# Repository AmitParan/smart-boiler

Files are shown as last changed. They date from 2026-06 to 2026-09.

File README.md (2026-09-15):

# Smart Electric Boiler — דוד חשמלי חכם

**An autonomous retrofit energy-management system for domestic electric water heaters.**

Final engineering project · Afeka College of Engineering, Tel Aviv
Students: **Elad Moalem** (אלעד מועלם) · **Amit Paran** (עמית פארן)
Supervisor: **Dmitry Teif** (דמיטרי טייף)

**Communication:** Master ↔ slave over **Power Line Communication** (KQ-330
modems on the 220 VAC wiring) — the default build. A WiFi (UDP) transport is
available as an option.

> ### 👨‍🏫 Reviewing this project? Start with the **[Guided Code Tour →](CODE_TOUR.md)**
> A short walkthrough of the safety architecture, the FreeRTOS mutex design, the
> wire protocol and the transport abstraction — each claim shown alongside the
> few lines of code that prove it, plus **four checks you can reproduce yourself**
> on the hardware in under ten minutes.

---

## Table of contents

1. [The problem](#1-the-problem)
2. [The solution — two-tier hybrid heating](#2-the-solution--two-tier-hybrid-heating)
3. [System architecture](#3-system-architecture)
4. [Hardware](#4-hardware)
5. [Safety architecture](#5-safety-architecture)
6. [Communication](#6-communication)
7. [Firmware architecture (FreeRTOS)](#7-firmware-architecture-freertos)
8. [The control brain](#8-the-control-brain)
9. [Repository layout](#9-repository-layout)
10. [Build and flash](#10-build-and-flash)
11. [Demo mode — 8 automated scenarios](#11-demo-mode--8-automated-scenarios)
12. [Results](#12-results)
13. [Documentation index](#13-documentation-index)

---

## 1. The problem

A conventional Israeli electric boiler ("דוד חשמלי") is a **blind, open-loop
machine**. The user flips a switch, waits, and gets no feedback about water
temperature or how much hot water is actually available. Three physical
inefficiencies follow from that:

| Problem | Consequence |
|---|---|
| **Open-loop operation** | The user over-heats "just in case", or under-heats and gets a cold shower |
| **Standing thermal losses** | A 80–150 L tank held at high temperature bleeds heat to the room continuously, 24 h a day |
| **Whole-tank heating** | Washing your hands heats 150 L of water to serve 2 L of demand |

The obvious fix — a **tankless instant heater** — is not available to most Israeli
homes. Those units demand **14 kW–24 kW** and three-phase service. A standard
apartment is limited to **single-phase, 16 A ≈ 3 kW**.

## 2. The solution — two-tier hybrid heating

This project fits **within the 3 kW household ceiling** by splitting the job
across two coordinated heating tiers instead of one big element.

```
   ┌──────────────────────────────────────────────────────────────┐
   │  TIER 1 — Moderate Storage                                   │
   │  Hold the main tank at only 35–40 °C, not 60–70 °C.          │
   │  A cooler tank loses far less heat to the room, so standing   │
   │  losses collapse. The tank is a warm buffer, not a kettle.    │
   └──────────────────────────────────────────────────────────────┘
                                │  water leaves the tank at ~35-40 °C
                                ▼
   ┌──────────────────────────────────────────────────────────────┐
   │  TIER 2 — Flow-Triggered Top-Up                              │
   │  A 3000 W inline heater in series with the outlet pipe adds   │
   │  a focused +3-7 °C ONLY while water is actually flowing,      │
   │  and only under hardware interlock. Energy is spent on the    │
   │  water you are using, at the moment you use it.               │
   └──────────────────────────────────────────────────────────────┘
```

The tank never has to be hot — it only has to be *warm enough* that a 3 kW
inline booster can close the remaining gap in real time. That is what keeps the
system inside a single-phase 16 A supply while still delivering a hot shower.

On top of the thermodynamics sits an **adaptive learning layer** that records
when the household actually showers and pre-heats ahead of predicted demand,
so the tank is ready without being held hot all day.

## 3. System architecture

Two microcontrollers, deliberately separated by role:

```
┌───────────────────────────────┐              ┌───────────────────────────────┐
│  MASTER — indoor command unit │              │  SLAVE — boiler-side unit     │
│  ESP32-S3                     │              │  ESP32-C6                     │
│  Viewe UEDX80480050E-WB-A     │◄────────────►│  custom PCB                   │
│  800x480 capacitive touch     │   1 packet   │                               │
│                               │   per second │                               │
│  · LVGL v8 touchscreen HMI    │              │  · 3x DS18B20 temperature     │
│  · SystemManager state machine│              │  · YF-B6 flow sensor          │
│  · Smart preheat learning     │              │  · ACS758 current sensing     │
│  · WiFi / NTP / weather       │              │  · 2x SSR drive (burst PWM)   │
│  · 8-scenario demo bench      │              │  · analog hardware interlock  │
└───────────────────────────────┘              └───────────────────────────────┘
        the user's world                              the plumbing's world
```

**Why two units?** The boiler is usually in a service balcony or on the roof —
behind reinforced concrete, often inside or near a MAMAD (safe room). Putting
the touchscreen there would be useless, and relying on WiFi reaching there was
judged unsafe for a control link. The control link therefore runs over **the
building's own 220 VAC wiring** using **Power Line Communication (PLC)**, which
passes through concrete that WiFi cannot.

> **Transport options.** PLC over KQ-330 modems is the default link. The
> communication layer is abstracted, so the same firmware can alternatively run
> the link over **WiFi (UDP)** with a single build flag, carrying byte-identical
> packets. Everything above the transport is shared by both options
> (see [section 6](#6-communication)).

## 4. Hardware

### 4.1 Slave GPIO map — ESP32-C6 *(book Table 7)*

| GPIO | Function | Direction | Component |
|:---:|---|---|---|
| **4** | `SSR_Internal` | Output (PWM) | Tank heater SSR |
| **5** | `SSR_Boost` | Output (PWM) | Inline booster SSR |
| **7** | `One_Wire_Bus` | In/Out | 3 × DS18B20 on one bus |
| **6** | `Flow_Sensor` | Input (interrupt) | YF-B6 Hall-effect flow meter |
| **10** | `PLC_RX` | Input (UART) | KQ-330 DOUT, via level shifter U3 |
| **11** | `PLC_TX` | Output (UART) | KQ-330 DIN |
| **3** | `Current_ADC` | Input (analog) | ACS758LCB-050B |

Defined in [`slave/src/config/config.h`](slave/src/config/config.h).

### 4.2 Master GPIO map — ESP32-S3 *(book Table 9)*

| GPIO | Function | Direction | Component |
|:---:|---|---|---|
| **17** | `MASTER_TX_PIN` | Output | KQ-330 DIN |
| **13** | `MASTER_RX_PIN` | Input | KQ-330 DOUT |
| **43 / 44** | `UART0_TX/RX` | — | USB CDC debug console |
| — | Touch + RGB | — | Managed by the board package (800×480) |

Defined in [`master/src/config/config.h`](master/src/config/config.h).

### 4.3 Key components

| Component | Part | Role |
|---|---|---|
| Master MCU | ESP32-S3 (Viewe UEDX80480050E-WB-A) | HMI, decisions, connectivity |
| Slave MCU | ESP32-C6-DevKitC-1 | Sensing, switching, safety |
| Power-line modem | KQ-330 | 9600 bps UART over 220 VAC |
| Solid-state relays | SSR-40DA (zero-crossing) | Switch both heating elements |
| Temperature | 3 × DS18B20 (1-Wire) | Tank, boiler outlet, boost outlet |
| Flow | YF-B6 Hall-effect | `F = 6.6 × Q` (Hz per L/min) |
| Current | ACS758LCB-050B | 40 mV/A, power calculation + fault detection |
| Comparator | LM393N + NTC | Autonomous 85 °C thermal cutoff |
| Interlock switching | 2N2222A BJT, BS170 MOSFET | Watchdog and flow gates |
| Level shifter | SN74LV1T34 | 5 V ↔ 3.3 V on the modem link |
| PSU | HLK-10M05 | 220 VAC → 5 V, isolated |

Full schematic, Gerbers, drill files and BOM live in [`pcb/`](pcb/).
Datasheets for every part are in [`datasheets/`](datasheets/).

## 5. Safety architecture

Safety is **dual-layer**: fast software checks, plus an **analog hardware
envelope that works even if the microcontroller is dead**. This is the heart of
the project and the reason the design is defensible.

### 5.1 The four hardware gates *(book §9.1.4)*

| Gate | Built from | What it physically prevents |
|---|---|---|
| **a. Internal Watchdog Gate** | 2N2222A BJT + DC-blocking capacitor | Controller freeze. The SSR latches **only** while it receives a continuous 1 kHz pulse train. A frozen MCU leaves a constant DC level, the capacitor blocks it, the base charge bleeds away and the heater is cut within ≈1 s. |
| **b. External Boost Gate** | Watchdog + flow interlock + PWM | Triple-gated. The booster cannot energise unless the controller is alive **and** water is genuinely flowing. |
| **c. Flow Interface** | BS170 MOSFET, 15–60 Hz | Dry-fire protection. When flow pulses stop, the RC network discharges and cuts the booster within 1.0 s. |
| **d. Analog Comparator + Thermal Cutoff** | LM393N + NTC, V<sub>ref</sub> ≈ 0.63 V | Boiling. At ≈85 °C the comparator output flips and disconnects SSR power directly — **no firmware involved at all**. |

> **This is why `ledcWrite(pin, 127)` at 1 kHz is not optional.**
> It looks like a PWM power setting; it is actually the **carrier that proves the
> controller is alive** to gate (a). Replacing it with `digitalWrite(HIGH)` would
> be read by the hardware as a controller-freeze fault and the heater could never
> stay on. See [`slave/src/tasks/pwm_task_internal.cpp`](slave/src/tasks/pwm_task_internal.cpp).

### 5.2 Hardware truth table *(book Table 11)*

`1` = live PWM pulse train · `DC/0` = logic low / fault / blocked · `X` = don't care

| NTC safety | CMD internal | CMD boost | Flow | SSR internal | SSR boost | Meaning |
|:---:|:---:|:---:|:---:|:---:|:---:|---|
| 0 (overheat) | X | X | X | **0** | **0** | NTC disconnects everything — system-wide safe state |
| 1 (OK) | DC / 0 | DC / 0 | X | 0 | 0 | Idle — no commands from the controller |
| 1 (OK) | 1 | DC / 0 | X | **1** | 0 | Base tank heating, independent of flow |
| 1 (OK) | DC / 0 | 1 | 1 | 0 | **1** | Booster only — requires flow |
| 1 (OK) | X | X | **0** | X | **0** | Flow interlock forces the booster off |
| 1 (OK) | 1 | 1 | 1 | **1** | **1** | Both tiers active under hardware supervision |

### 5.3 Software safety — `TaskSafety`, every 50 ms

[`slave/src/tasks/safety_task.cpp`](slave/src/tasks/safety_task.cpp) runs at the
**highest FreeRTOS priority (4)** and independently verifies:

1. Every temperature sensor is below **80 °C** (software cutoff, below the 85 °C hardware trip)
2. The booster is never commanded while flow **< 1.0 L/min** (dry-fire)
3. No **uncommanded current** is flowing — catches a welded/shorted SSR
4. A **CMD packet arrived within the last 5 s** — otherwise the link is presumed lost
5. Every temperature reading is **physically plausible** (−55…+125 °C) — a
   disconnected DS18B20 reports −127 °C, which would otherwise convince the
   controller the water is freezing and make it heat indefinitely while check 1
   stays silent. A failed sensor must stop the heater, not command full power.

Any failure latches `system_fault`, and both SSRs are cut immediately.

## 6. Communication

### 6.1 Binary packet protocol

Frame layout, identical on both sides
([`*/src/config/boiler_protocol.h`](slave/src/config/boiler_protocol.h)):

```
[ 0xAA | LEN | TYPE | SEQ | ...payload... | CRC8 | 0x55 ]
  start                                            end
         └────── CRC-8/SMBUS (poly 0x07) ──────┘
```

| Packet | Direction | Size | Contents |
|---|---|:---:|---|
| **CMD** | Master → Slave | 9 B | PWM internal %, PWM boost %, flag bits |
| **STATUS** | Slave → Master | 17 B | 3 × temperature, flow, power, status bits |

Temperatures are sent as `int16 × 10` (0.1 °C resolution), flow as `uint16 × 10`.
Cadence is **1 packet per second**, with a rolling sequence number so either side
detects a dropped packet.

### 6.2 The transport layer — PLC, with a WiFi option

The master and slave communicate over **Power Line Communication**: each board
drives a KQ-330 modem over UART (9600 bps), and the modems carry the packets
across the 220 VAC mains wiring. The link medium is abstracted behind
[`link.h`](slave/src/comms/link.h), so the **exact same bytes** can alternatively
travel over WiFi.

The PLC link was verified working on the bench: a CMD every second, a STATUS
reply, CRC-8 validation and sequence numbers, with the KQ-330 timing constants
(2 ms/byte, 200 ms half-duplex guard) locked in firmware.

```
       sendCommand() / PLC_SendStatus()          ← protocol, unchanged
                     │
          link_send() / link_poll()              ← the abstraction
                     │
           ┌─────────┴─────────┐
     link_plc.cpp        link_wifi.cpp
   KQ-330 over UART        UDP over WiFi
```

| | `link_plc.cpp` **(default)** | `link_wifi.cpp` (option) |
|---|---|---|
| Framing | Byte-by-byte receive state machine | A datagram **is** a frame |
| TX timing | 2 ms inter-byte gap (modem requirement) | none |
| Half-duplex guard | 200 ms after RX before TX | none — UDP is full duplex |
| Discovery | n/a | Automatic; no IP is configured anywhere |

Selected by one build flag in `platformio.ini` — **the same on both sides**:

```ini
build_flags =
    ; -DLINK_WIFI    ; flag absent (default) -> KQ-330 power-line modem
                     ; uncomment             -> WiFi (UDP)
```

### 6.3 PLC installation notes

- Both KQ-330 modems must be on the **same electrical phase** of the mains.
- The modem is half-duplex, so the protocol is strictly master-initiated
  request/response, with a 200 ms guard before the slave replies.
- Bytes are paced 2 ms apart, as the modem requires.

A step-by-step procedure for checking the modem link during installation is in
[`TROUBLESHOOTING_PLC.md`](TROUBLESHOOTING_PLC.md).

## 7. Firmware architecture (FreeRTOS)

### 7.1 Slave task hierarchy *(book Table 19)*

| Priority | Task | Period | Responsibility |
|:---:|---|---|---|
| **4** (highest) | `TaskSafety` | 50 ms | Closed-loop safety, hard SSR cutoff |
| **3** | `TaskPWM_Internal`, `TaskPWM_Boost` | 2000 ms window | Burst-mode SSR power control |
| **2** | `TaskTemp`, `TaskFlow`, `TaskCurrent`, `TaskPLC` | 100–500 ms | Sensing and the comms link |
| **1** (lowest) | `TaskSerial` | loop | Debug console, `d`/`r` mode switching |

### 7.2 Memory guards — the four mutexes *(book Table 20)*

The slave is fully concurrent, so every shared variable is protected:

| Mutex | Written by | Read by |
|---|---|---|
| `guard_temps` | `TaskTemp` | `TaskPLC`, `TaskSafety`, `TaskPWM_Boost` |
| `guard_flow` | `TaskFlow` | `TaskPLC`, `TaskSafety`, `TaskPWM_Boost` |
| `guard_current` | `TaskCurrent` | `TaskPLC`, `TaskSafety` |
| `guard_cmd` | `TaskPLC` | `TaskPWM_Internal`, `TaskPWM_Boost`, `TaskSafety` |

Created in [`slave/src/main.cpp`](slave/src/main.cpp) **before any task starts**.

### 7.3 Master — dual-core split *(book Table 17)*

The ESP32-S3's two cores are separated deliberately so that a heavy LVGL redraw
can never delay a control packet:

| Core | Work |
|---|---|
| **Core 0** | `TaskMasterComms` — 1 s CMD cadence, STATUS reception, CRC-8 |
| **Core 1** | LVGL GUI, touch, WiFi/NTP, weather, automated test bench |

### 7.4 Burst-mode power control

The booster must deliver a *specific* power, not simply on/off. Required power
comes from the thermodynamic relation:

```
P = ṁ · Cp · ΔT
```

For 5 L/min (ṁ = 0.0833 kg/s) and ΔT = 6 °C:
`P = 0.0833 × 4184 × 6 ≈ 2090 W` — about **70 %** of the 3000 W element.

The controller therefore runs a **2000 ms time-proportional window**: 1400 ms ON,
600 ms OFF. Because the SSR is zero-crossing, a 2 s window contains 200 mains
half-cycles at 50 Hz, so 70 % resolves to 140 half-cycles — fine-grained control
with no switching noise injected onto the power line.

```
Power envelope   ████████████████████░░░░░░░░    1400 ms ON / 600 ms OFF
1 kHz carrier    ▌▌▌▌▌▌▌▌▌▌▌▌▌▌▌▌▌▌▌▌            watchdog proof-of-life
Mains output     ∿∿∿∿∿∿∿∿∿∿∿∿∿∿∿∿∿∿∿∿            switched at zero crossings
```

## 8. The control brain

### 8.1 SystemManager — finite state machine

[`master/src/control/SystemManager.cpp`](master/src/control/SystemManager.cpp)
evaluates in strict priority order:

| Priority | State | Trigger | Output |
|:---:|---|---|---|
| 1 | `SAFETY_OVERRIDE` | Link lost **or** T ≥ 85 °C | Both PWM = 0 |
| 2 | `STATE_OFF` | User switched off | Both PWM = 0 |
| 3 | `STATE_SHOWER_BOOST` | Flow detected **and** tank < 45 °C | Booster on |
| 4 | `STATE_HEATING_TANK` | No flow **and** tank < 40 °C | Tank heater on |
| 5 | `STATE_STANDBY` | Temperature satisfied | Idle |

### 8.2 Smart preheat — the learning layer

[`master/src/control/smart_preheat.cpp`](master/src/control/smart_preheat.cpp)
records the time of each real shower (detected as flow crossing the threshold
from zero) and predicts when the household will next want hot water, starting
the tank early enough to be ready. It **never** overrides a manual ON, **never**
touches safety, and stands down entirely if the link to the slave is lost.

Three user-selectable operating modes:

| Mode | Behaviour |
|---|---|
| **Manual** | Reactive only, no pre-heating |
| **Ready-by** | User sets target times; the system computes when to start |
| **Smart** | Learned usage patterns drive pre-heating automatically |

## 9. Repository layout

Both firmwares use the same scheme, so understanding one gets you the other.

```
master/src/                              slave/src/
├── main.cpp      boot, WiFi/NTP,        ├── main.cpp      boot, mutexes,
│                 LVGL render loop       │                 task creation
├── config/       pins, wire protocol,   ├── config/       pins, wire protocol,
│                 LVGL + display config  │                 ports, WiFi secrets
├── comms/        transport + task       ├── comms/        transport + protocol
├── control/      SystemManager, smart   ├── core/         shared state, mutexes,
│                 preheat, app mode      │                 DEMO/REALTIME mode
├── data/         statistics, network    ├── tasks/        6 FreeRTOS tasks
├── ui/           LVGL screens           └── diagnostics/  test sketches
├── demo/         8-scenario bench
└── diagnostics/  test sketches
```

### Where do I look for…?

| Question | File |
|---|---|
| What decides when the heater turns on? | `master/src/control/SystemManager.cpp` |
| What do master and slave send each other? | `*/src/config/boiler_protocol.h` |
| How do the bytes travel? | `*/src/comms/link.h`, `link_plc.cpp`, `link_wifi.cpp` |
| How is an SSR actually switched? | `slave/src/tasks/pwm_task_internal.cpp` |
| What protects against overheating? | `slave/src/tasks/safety_task.cpp` |
| Where are the demo scenarios? | `master/src/demo/demo_scenarios.cpp` |
| Which GPIO is what? | `*/src/config/config.h` |
| How does the learning work? | `master/src/control/smart_preheat.cpp` |

> **Note on `#include`:** every include stays short (`#include "config.h"`)
> because each `platformio.ini` adds the `src/` subfolders to the include path.
> No source file needed editing when the folders were introduced.

## 10. Build and flash

Requires [PlatformIO](https://platformio.org/). Both projects are independent.

```bash
# Slave (ESP32-C6)
cd slave
pio run --target upload
pio device monitor
```

```bash
# Master (ESP32-S3)
cd master
pio run --target upload
pio device monitor
```

Set `upload_port` / `monitor_port` in each `platformio.ini` to your actual COM
ports (`pio device list` will show them).

### WiFi option — credentials (slave)

Only needed when building with `-DLINK_WIFI`. The slave has no touchscreen, so
its credentials are compiled in:

```bash
cd slave/src/config
cp wifi_secrets.example.h wifi_secrets.h    # then edit with your SSID/password
```

`wifi_secrets.h` is **gitignored** and never reaches GitHub. ESP32 radios are
**2.4 GHz only** — a 5 GHz-only network will not connect.

### Windows build note

`slave/platformio.ini` sets `core_dir = C:/pio`. This is **required on Windows**:
RISC-V gcc forwards all 278 framework include paths to the assembler, and with
`<WiFi.h>` included (WiFi option) the command line reaches 32,870 characters against Windows'
32,767 limit — reported misleadingly as `cannot execute as.exe`. Create the short
path once (no admin needed):

```bash
mklink /J C:\pio %USERPROFILE%\.platformio
```

## 11. Demo mode — 8 automated scenarios

The master runs a complete automated test bench
([`master/src/demo/demo_scenarios.cpp`](master/src/demo/demo_scenarios.cpp)) that
injects scripted sensor values, so the **entire control and safety chain can be
demonstrated without plumbing or 220 V loads**. The slave still fires its real
SSRs, so the behaviour is genuine end-to-end.

| # | Scenario | Demonstrates |
|:---:|---|---|
| 1 | Pre-Heating (tank only) | `STATE_HEATING_TANK`, internal SSR, 2500 W |
| 2 | Preheated Shower | `STATE_SHOWER_BOOST`, booster SSR, 3000 W |
| 3 | Warm Shower Boost Cutoff | Both SSRs off once 45 °C is reached |
| 4 | Standby / Redundant Request | Correct idle, 0 W |
| 5 | Predictive Solar Bypass | System yields to solar gain, stays off through a 28→42 °C sweep |
| 6 | Communication Loss | Link cut → slave 5 s watchdog → hard cutoff |
| 7 | Overtemperature | Software cutoff at 80 °C, hardware interlock simulated at 85 °C |
| 8 | Stuck SSR | Uncommanded current detected within 50 ms |

Switch modes from the Settings screen, or on the slave console: `d` = DEMO,
`r` = REALTIME, `?` = status.

## 12. Results

- **30–50 % reduction** in daily electricity consumption versus a conventional
  boiler, while fully preserving user comfort
- Validated on a laboratory test bench **and** through MATLAB/Simulink
  system-level simulation across all operating scenarios and edge cases
- Communication robustness and immediate safety response demonstrated
- Operates entirely within a standard **single-phase 16 A / 3 kW** household supply

The complete energy analysis, simulation models and scenario plots are in
[`Matlab/`](Matlab/).

## 13. Documentation index

| Path | Contents |
|---|---|
| [`README_v3.md`](README_v3.md) | Detailed development documentation, bug log, TODO |
| [`SYSTEM_DOCUMENTATION.md`](SYSTEM_DOCUMENTATION.md) | System-level reference |
| [`docs/plc-protocol.md`](docs/plc-protocol.md) | Packet protocol specification |
| [`docs/smart-brain.md`](docs/smart-brain.md) | Learning algorithm design |
| [`docs/smart-preheat.md`](docs/smart-preheat.md) | Pre-heat decision logic |
| [`TROUBLESHOOTING_PLC.md`](TROUBLESHOOTING_PLC.md) | KQ-330 link installation and check procedure |
| [`pcb/`](pcb/) | Schematic, board layout, Gerbers, drill files, BOM |
| [`datasheets/`](datasheets/) | Datasheets for every component used |
| [`Matlab/`](Matlab/) | Simulink model, 8 scenario scripts, energy analysis |
| [`tools/`](tools/) | `serial_logger.py`, `udp_link_probe.py` (WiFi option) |

---

<sub>Afeka College of Engineering, Tel Aviv · Final Engineering Project</sub>

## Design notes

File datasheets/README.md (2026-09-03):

# Component Datasheets

Add the PDF datasheet for each component used in the project.

## Components to add

| Component | Part Number | File |
|---|---|---|
| Microcontroller (Master) | ESP32-S3 | `esp32-s3-datasheet.pdf` |
| Microcontroller (Slave) | ESP32-C6 | `esp32-c6-datasheet.pdf` |
| Display | Viewe UEDX80480050E-WB-A | `viewe-uedx80480050e-datasheet.pdf` |
| PLC Modem | KQ-330 | `kq-330-datasheet.pdf` |
| Temperature Sensor | DS18B20 | `ds18b20-datasheet.pdf` |
| Flow Sensor | YF-B6 | `yf-b6-datasheet.pdf` |
| Current Sensor | ACS758LCB-050B | `acs758-datasheet.pdf` |
| Solid State Relay (Internal) | SSR (internal heater) | `ssr-internal-datasheet.pdf` |
| Solid State Relay (Boost) | SSR (boost heater) | `ssr-boost-datasheet.pdf` |
| Comparator (Safety) | LM393N | `lm393n-datasheet.pdf` |
| NPN Transistor (Switching) | 2N2222 | `2n2222-datasheet.pdf` |
| MOSFET (Flow Interlock) | BS170 | `bs170-datasheet.pdf` |

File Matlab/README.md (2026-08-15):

========================================================================
             SMART ELECTRIC BOILER -- SIMULATION SUITE
========================================================================

MATLAB / Simulink / Simscape models and analytical studies for a 
retrofit Smart Electric Boiler. The goal is to reduce electricity 
consumption WITHOUT reducing user comfort by heating only when needed, 
keeping a low standby temperature, preheating before predicted use, 
and using an inline boost heater on demand.

This suite validates the thermal model, runs 8 scenarios, and produces 
committee-ready figures and KPI tables.

------------------------------------------------------------------------
1. SYSTEM UNDER TEST
------------------------------------------------------------------------

+-------------------+----------------------------------+------------------------------------+
| Component         | Spec                             | Role                               |
+-------------------+----------------------------------+------------------------------------+
| Water tank        | 150 L (150 kg), Cp=4184 J/(kg*K) | Main thermal reservoir             |
| Internal heater   | 2500 W                           | Heats the whole tank               |
| Inline boost      | 3000 W (Andetong JDU30, UA=33)   | Instant on-demand lift of flow     |
| Temp sensor       | DS18B20                          | Tank / delivered temperature       |
| Flow sensor       | YF-B6                            | Detects draw (LPM)                 |
| Current sensor    | ACS758                           | Power metering + stuck-SSR check   |
| Controller        | ESP32 + FreeRTOS                 | Smart control logic                |
| Comms             | PLC Master <-> Slave             | Distributed control (packet loss)  |
| Actuators         | SSRs (internal + boost)          | Switch the heaters                 |
| Safety            | Flow interlock, SW/HW over-temp  | Fail-safe protection               |
+-------------------+----------------------------------+------------------------------------+

Key Physical Constants (defined in boiler_params.m):
- UA_Losses = 1.5 W/K (Rth = 0.667 K/W)
- Ambient Temperature = 20 degrees C
- Comfort Threshold = 38 degrees C
- Supply Voltage = 230 V
- Standby Target = 30 degrees C
- Active Target = 40 degrees C
- Conventional Target = 65 degrees C

------------------------------------------------------------------------
2. REPOSITORY STRUCTURE
------------------------------------------------------------------------

BoilerProject/
|-- boiler_params.m            % SINGLE source of truth for constants (load first)
|-- run_all.m                  % Runs Scenarios 1-8 sequentially, saves all figures
|-- summary_table.m            % Aggregates all-scenario KPIs into a table figure
|-- summary_bar.m              % Smart vs Dumb energy bar (energy scenarios)
|-- energy_philosophy.m        % Analytical 24h real-life "why we save" study (3 cases)
|-- Scenario_1_Preheating.m
|-- Scenario_2_ColdShowerStart.m
|-- Scenario_3_WarmShowerCutoff.m
|-- Scenario_4_RedundantRequest.m
|-- Scenario_5_SolarBypass.m
|-- Scenario_6_PLC_CommLoss.m
|-- Scenario_7_Overtemp.m
|-- Scenario_8_StuckSSR.m
|-- lib/
|   |-- pack_boiler_params.m   % Snapshots workspace constants into struct P
|   |-- getSig.m               % Robust logged-signal fetch (duplicate-name safe)
|   |-- extract_signals.m      % Pulls model signals into a struct S
|   |-- dumb_baseline.m        % Conventional 65C boiler reference model
|   |-- plot_boiler_std.m      % Standard 4-row scenario figure plotting tool
|   +-- kpi_report.m           % Computes + prints KPIs, publishes LAST_KPI
|-- figures/                   % Auto-saved PNGs for report and presentation slides
+-- Boiler_System_Model.slx    % Simscape thermal + control model

------------------------------------------------------------------------
3. REQUIREMENTS
------------------------------------------------------------------------

- MATLAB R2020a+ (uses exportgraphics, XEndPoints; falls back to print if older)
- Simulink + Simscape (required for Scenarios 1-4 which run Boiler_System_Model)
- Scenarios 5-8 and analytical studies are PURE MATLAB (Simulink model not required)

------------------------------------------------------------------------
4. QUICK START
------------------------------------------------------------------------

In the MATLAB Command Window:

    >> cd BoilerProject
    >> run_all             % Runs all 8 scenarios and saves PNGs to figures/
    >> summary_table       % Generates cross-scenario KPI evaluation table
    >> summary_bar         % Produces comparative energy bar chart
    >> energy_philosophy   % Runs the 24h analytical energy-saving proof

Note: Every scenario script begins by loading boiler_params, ensuring 
constants are always defined and preventing workspace cleanup errors.

------------------------------------------------------------------------
5. MODEL INTERFACE (SCENARIOS 1-4)
------------------------------------------------------------------------

Inputs (base-workspace timeseries): 
- sim_Flow (LPM)
- sim_LDR (0-1023)
- sim_Habit (0/1 predicted-use)
- sim_User_Mode (1 = manual/active, 2 = auto)

Logged signals: 
- T_Internal, T_Boost, Cmd_Internal, Cmd_Boost, Safe_Internal, P_Internal_Actual_W

PLC Packet Loss Control:
Controlled by Block_3_PLC_Channel/Switch threshold:
- -1   = 0% loss (used for all clean thermodynamic runs)
- 0.05 = approx. 52% loss (raw model default)
- 1.1  = 100% full communication loss

Model-Frozen Policy:
The core Simulink file (.slx) is never modified. Fault behaviors, safety 
override conditions, and predictive solar logics for Scenarios 5-8 are 
fully emulated script-side by post-processing or overriding the struct S.

------------------------------------------------------------------------
6. STANDARD FIGURE LAYOUT (plot_boiler_std)
------------------------------------------------------------------------

Every model-based scenario script renders 4 synchronized rows on a dynamic 
time axis (scaled automatically to seconds, minutes, or hours):
Row 1: Main Reservoir Temperature (Smart tank, Dumb baseline, Target lines)
Row 2: Cumulative Electrical Energy (Smart vs Dumb) -- or Power for safety
Row 3: Water Flow & Delivered Temp (shaded booster Delta-T band during flow)
Row 4: Actuator / SSR Command States

------------------------------------------------------------------------
7. THE EIGHT SCENARIOS
------------------------------------------------------------------------

+---+-----------------------+----------+----------------------+--------------------------+
| # | Name                  | Duration | Focus                | Baseline Reference       |
+---+-----------------------+----------+----------------------+--------------------------+
| 1 | Pre-Heating           | ~4.2 h   | Energy Efficiency    | Dumb 65 degrees C        |
| 2 | Preheated Shower      | 10 min   | Comfort / Hot Water  | Passive (No heating)     |
| 3 | Warm Shower Cutoff    | 10 min   | Active Control       | Passive                  |
| 4 | Redundant Request     | 5 min    | Idle Behavior        | --                       |
| 5 | Predictive Solar      | 24 h     | Solar Intelligence   | Elec-only & Conv-solar   |
| 6 | PLC Comm Loss         | 60 s     | Comm Fail-Safe       | --                       |
| 7 | Redundant Safety      | accel.   | Multi-threshold SW/HW| --                       |
| 8 | Stuck SSR Lockout     | 0.5 s    | Current Diagnostics  | --                       |
+---+-----------------------+----------+----------------------+--------------------------+

* Scenario 1 -- Pre-Heating:
Heats stagnant 150 L tank to the 40C smart target and compares with 
conventional heating to 65C. Demonstrates validated thermal model and the 
>50% standby energy savings. Curves overlap until smart tank hits 40C.

* Scenario 2 -- Preheated Shower:
Smart system predicted shower and preheated tank to 40C. An 8 LPM draw 
occurs, and the 3000 W inline boost tops up the delivered temperature 
(Delta-T approx. 5.4C). Conventional boiler was off (cold water).
Key Metric: Delivered temperature and comfort %, not energy.

* Scenario 3 -- Warm Shower / Dynamic Cutoff:
Tank starts at 45C, active target is 42C. Boost remains OFF while tank 
alone is sufficient. As tank drops below 42C, the boost instantly snaps 
ON (shaded band appears). Internal element has no flow interlock (only over-temp).

* Scenario 4 -- Redundant Request (Standby):
Auto mode with no predicted use (sim_User_Mode = 2, sim_Habit = 0). System 
holds 30C standby state and ignores repetitive manual ON commands to avoid 
overheating.

* Scenario 5 -- Predictive Solar (Analytical, Sunny + Cloudy):
Three-way daily comparison with 19:00 shower:
- Electric-only (1h manual): often results in cold shower (comfort failure)
- Conventional solar (1h blind manual): wastes electrical energy on sunny days
- Smart hybrid: continuously forecasts solar yield (remaining solar integration)
  and applies a precise electrical top-up only when needed.
Outputs: 2x2 plots, solar harvested indicators, green electric-pulse bands.

* Scenario 6 -- PLC Communication Loss:
Timeline: idle -> active heating -> sudden comm loss. Proves fail-safe. 
When the PLC link drops, the user demand remains active but the safety 
interlock immediately drops power to 0W. Resolution: 50 ms.

* Scenario 7 -- Thermal Runaway & Redundant Safety (Two Cases):
Tight 60-100C axis, dual-layer thresholds:
- Case 7A (SW success): software de-energizes the SSR at 80C.
- Case 7B (HW backup): software fails (stuck SSR), temperature climbs to 
  85C where physical hardware cutoff switch trips and cuts raw supply power.

* Scenario 8 -- Stuck SSR caught by Current Sensor (ACS758):
Electrical fail-safe layer. Software commands OFF but current continues 
to flow. The ACS758 current sensor detects the current-vs-command mismatch 
and trips an independent magnetic lockout relay in 50 ms -- preventing 
thermal runaway before any temperature rise occurs.

------------------------------------------------------------------------
8. ANALYTICAL STUDY -- energy_philosophy.m
------------------------------------------------------------------------

Model-independent, thermodynamic (m*Cp*dT/dt) 24h simulation analyzing 
three real-life residential behaviors (event-driven, boiler OFF between showers):
1. Dumb Wasteful: Switched on early, heats tank to 65C. Comfort OK, but 
   high standby losses and severe overheating.
2. Dumb Cold: Switched on only 1h before use. Inefficient, results in cold water.
3. Smart Hybrid: Precise preheat to 40C combined with inline boost. Comfort OK, 
   very low energy usage.

Produces diverging cumulative energy plots, an exact 4-way stacked energy 
breakdown (standing losses, useful delivered at 38C, over-heat waste, 
and residual stored energy), and a KPI comparison table.

------------------------------------------------------------------------
9. KPI DEFINITIONS
------------------------------------------------------------------------

- Smart / Dumb Energy [kWh]: Integral of (P_internal + P_boost) dt.
- % Saved: 1 - E_smart / E_dumb (suppressed when dumb baseline is passive).
- Useful Delivered [kWh]: Integral of mdot*Cp*(min(T_deliver, 38) - T_inlet) dt 
  during flow periods (comfort normalized).
- Comfort %: Fraction of active flow time where T_deliver >= 38 degrees C.
- Boost Delta-T: T_deliver - T_Internal during flow (= P_boost / (mdot*Cp)).
- Sheath Temp: T_water + P_boost/UA_boost (thick-film safety limits).
- Trip Latency: Elapsed time from fault onset to safety lockout (Scenarios 7/8).

------------------------------------------------------------------------
10. THERMAL MODEL VALIDATION
------------------------------------------------------------------------

Simscape tank validated against the exact analytic solution of the 
continuous ordinary differential equation: m*Cp*dT/dt = P - UA*(T - T_amb)
with a constant 2500W heating input:
- RMSE (Simscape vs Analytic) < 0.5 degrees C
- Injected power verified at 2500W via logged P_Internal_Actual_W
- Verified losses: 0W at start, 30W at 40C (UA = 1.5 W/K)

Fixed bugs documented during validation:
- Heater block gain fixed to P_Internal_W, not P_Internal_W/2500.
- Convective coefficient (h_Internal) raised to 1000 W/(m^2*K) to ensure 
  effective thermal coupling with the water.
- Ambient thermal reference modified to absolute Kelvin (293.15 K), not 20.
- PLC channel packet-loss switch threshold set to -1 (0% loss) for standard runs.
- Addressed duplicate Cmd_Internal logging in getSig.m.

------------------------------------------------------------------------
11. TUNING KNOBS (LOCATED AT THE TOP OF EACH SCRIPT)
------------------------------------------------------------------------

- Scenarios 2 & 3: T_tank_start, FLOW_LPM, T_target_logic
- Scenario 5: Qsun, Qcld (solar peaks), manual_lead
- Scenario 7: ramp (accelerated rate), Tsw = 80, Thw = 85
- Scenario 8: t_cmd, t_trip (50 ms lockout delay), I_nom
- energy_philosophy: showers, dur, FLOW, user_margin

------------------------------------------------------------------------
12. OUTPUTS
------------------------------------------------------------------------

Figures are automatically written to the figures/ directory as high-resolution 
PNG files (170-200 DPI). Real-time KPI summaries are printed to the command 
line during execution. Run summary_table and summary_bar to compile 
final aggregated presentation graphics.

========================================================================

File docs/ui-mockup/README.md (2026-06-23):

# Smart Boiler — UI Redesign Mockup

Interactive HTML mockup of the redesigned master touchscreen UI (ESP32-S3, 800×480, LVGL).
Open [`index.html`](index.html) in any browser — no build step, no hardware needed.

This is a **design prototype**, not firmware. It defines the target look, layout, and
navigation before the screens are ported into LVGL (`master/src/ui_manager.cpp`).

## Why this redesign

Three problems with the original single-screen UI drove this work:

1. **WiFi entry was messy** — a cramped modal where the "save password" checkbox overlapped the keyboard.
2. **Main UI was inefficient** — everything fought for space on one screen.
3. **Touch targets were too small** for the 5" panel.

## Design decisions

- **Navigation:** Home + tiles. The home dashboard holds the daily essentials; big tiles open focused sub-screens with a back button. Transitions are a smooth fade + slide.
- **Language:** English (matches current firmware).
- **Audience:** consumer-first, plus a hidden **Diagnostics** page (opens via long-press on device) showing raw sensor/PLC/SSR values for development.
- **Touch targets:** minimum 64px everywhere.

## Screens

| Screen | Purpose |
|---|---|
| **Home** | Water-temp circle, big ON/OFF, shower-status strip, `Auto` pre-heat badge, nav tiles |
| **Settings** | Large 92px −/+ target-temp control; links to Schedule and Diagnostics |
| **Schedule** | `Smart learn` vs `Ready by` time (per weekday/weekend), learning progress, next weather-adjusted pre-heat — per [`docs/smart-brain.md`](../smart-brain.md) §7 |
| **Network** | Full-screen WiFi list + password screen |
| **Stats** | Usage metrics + 24h "when you shower" histogram (the brain's learning data) |
| **Diagnostics** | Hidden raw-data grid for development |

## WiFi password flow (key change)

The old checkbox is **gone**. Instead:

- The keyboard fills the freed space (keys ~62px tall — important on the small screen).
- A show/hide eye toggle was added to the password field.
- **After** a successful connect, a dialog asks *"Save this password?"* (Not now / Save).
  Rationale: only offer to save a password that actually worked, and maximize keyboard size.

> Porting note: this means credential-saving moves out of the connect handler
> (currently `ui_manager.cpp` saves on the checkbox state) to *after* `WL_CONNECTED`.

## Status

Design phase. Next step (when the device is available): port these screens into LVGL using a
reusable component kit (`make_big_button` / `make_card` / `make_nav_bar`) + a screen manager.

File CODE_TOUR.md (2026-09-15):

# Guided Code Tour — for reviewers

This document is a short, guided path through the parts of the codebase that
carry the real engineering: **safety**, **concurrency**, **the wire protocol**,
and **the transport abstraction**.

It is deliberately **not** a code dump. Each section states a claim the project
makes, then shows the few lines that prove it, then links to the full file.
Every snippet is under 25 lines and can be read in one screen.

**How to read this:** sections 1–4 are the evidence. Section 5 tells you how to
**reproduce every claim yourself** on the hardware in a few minutes.

> Line-number links point at commit `d3754fe`, so they stay accurate permanently.

---

## 1. Safety — the part that works when the software doesn't

The system drives two mains-voltage heating elements. The design assumption is
that **the microcontroller will eventually fail**, so safety cannot depend on it.

### 1.1 The 1 kHz carrier is a hardware watchdog, not a power setting

This is the single most important — and most misreadable — line in the codebase.

[`slave/src/tasks/pwm_task_internal.cpp:8-18`](https://github.com/AmitParan/smart-boiler/blob/d3754fe/slave/src/tasks/pwm_task_internal.cpp#L8-L18)

```cpp
//  HARDWARE-INTERLOCK REQUIREMENT  (Project Book: "Internal Watchdog Gate")
//  The SSR gate is DC-blocking (series input capacitors). It latches ONLY
//  while it receives a continuous high-frequency pulse train ("AC" proof of
//  a live controller). A constant DC level is read as a controller-freeze
//  fault and the gate physically cuts the heater within ~1 s (RC, tau ~= 1 s).
//    => ledcWrite(pin, 127) @ 1 kHz supplies that MANDATORY carrier.
//    => DO NOT replace with digitalWrite(HIGH) (README "SW-3"): constant DC
//       trips the hardware watchdog and the heater can never sustain ON.
ledcAttach(PIN_SSR_INT, 1000, 8);
```

`ledcWrite(pin, 127)` looks like "50 % power". It is not. It is the
**proof-of-life carrier** that keeps the analog watchdog gate (2N2222A + series
capacitor) energised. If the firmware crashes and leaves the pin at a constant
level, the capacitor blocks it, the base charge bleeds away through R3, and the
heater is physically disconnected in about one second — **with no code running**.

Actual power control is done separately, by the 2000 ms burst window below the
carrier. See project book §9.1.4(a) and Figure 32.

### 1.2 Fault state is checked before anything else

[`slave/src/tasks/pwm_task_internal.cpp:23-28`](https://github.com/AmitParan/smart-boiler/blob/d3754fe/slave/src/tasks/pwm_task_internal.cpp#L23-L28)

```cpp
if (system_fault) {
    ledcWrite(PIN_SSR_INT, 0);
    internal_ssr_on = false;
    vTaskDelay(pdMS_TO_TICKS(100));
    continue;
}
```

The fault check is the **first** statement in the control loop, before any
command is read or any mutex is taken. A latched fault cannot be starved,
delayed or out-voted by the control path. The identical block opens
`TaskPWM_Boost`.

### 1.3 Detecting a *welded* SSR — current with no command

One of the five safety checks, and the one that shows failure-mode
thinking rather than limit-checking.

[`slave/src/tasks/safety_task.cpp:82-85`](https://github.com/AmitParan/smart-boiler/blob/d3754fe/slave/src/tasks/safety_task.cpp#L82-L85)

```cpp
bool any_commanded    = (local_pwm_int > 0u) || (local_pwm_bst > 0u);
bool do_current_check = (currentMode == MODE_DEMO) || current_sensor_valid;
if (do_current_check && !any_commanded && local_current > 0.5f) {
    fault = true;
```

A solid-state relay's characteristic failure is to fail **closed** — welded on,
with the element live and the controller convinced it is off. Comparing measured
current against commanded state catches exactly that, within one 50 ms cycle.

Note `current_sensor_valid`: the check is **skipped in REALTIME if the ACS758
failed its boot calibration**, because an uncalibrated ADC would produce phantom
faults. Refusing to act on data known to be untrustworthy is deliberate.

### 1.4 The link watchdog, and why `cmd_ever_received` exists

[`slave/src/tasks/safety_task.cpp:97`](https://github.com/AmitParan/smart-boiler/blob/d3754fe/slave/src/tasks/safety_task.cpp#L97)

```cpp
if (cmd_ever_received && (millis() - last_cmd_received_ms > PLC_TIMEOUT_MS)) {
```

If the master goes silent for 5 s, the slave assumes the link is lost and cuts
both elements. The `cmd_ever_received` guard prevents a **false trip at boot**,
when `last_cmd_received_ms` is still zero and no CMD could possibly have arrived
yet — the link may take several seconds to come up after power-on (up to 20 s
when built with the WiFi option).

### 1.5 Design → implementation traceability

The software checks in `TaskSafety` implement the **Logic Truth Table
(book Table 10)**; the analog gates implement the **Hardware Truth Table
(book Table 11)**. The mapping is one-to-one:

| Book Table 11 row | Enforced by |
|---|---|
| NTC overheat → everything off | LM393N comparator (hardware only, no firmware) |
| Boost requires flow | `safety_task.cpp:67-75` **and** the BS170 flow gate |
| Controller freeze → heater off | 1 kHz carrier + DC-blocking capacitor (§1.1) |
| Uncommanded current → fault | `safety_task.cpp:82-94` |
| Implausible sensor reading → fault | `temp_task.cpp` range check + `safety_task.cpp` check 5 |

Two of these rows are enforced **twice** — once in software, once in analog
hardware. That redundancy is the point.

**Full file:** [`slave/src/tasks/safety_task.cpp`](https://github.com/AmitParan/smart-boiler/blob/d3754fe/slave/src/tasks/safety_task.cpp) — priority 4, runs every 50 ms.

---

## 2. Concurrency — four mutexes, and who may touch what

The slave runs seven FreeRTOS tasks that share sensor and command state. Every
shared variable is protected by exactly one mutex, and the ownership rules are
documented in the header rather than left implicit.

### 2.1 The guards are declared with their scope stated

[`slave/src/core/shared_data.h:73-77`](https://github.com/AmitParan/smart-boiler/blob/d3754fe/slave/src/core/shared_data.h#L73-L77)

```cpp
extern SemaphoreHandle_t guard_temps;    ///< guards temps[3]
extern SemaphoreHandle_t guard_flow;     ///< guards current_flow
extern SemaphoreHandle_t guard_current;  ///< guards current_rms, power_watts
extern SemaphoreHandle_t guard_cmd;      ///< guards cmd_pwm_internal/boost/flags
extern portMUX_TYPE      timerMux;       ///< ISR-safe spinlock for flow pulse counter
```

`timerMux` is a **spinlock, not a mutex** — it protects the flow pulse counter
inside an interrupt service routine, where blocking on a semaphore is forbidden.
Using the right primitive for ISR context is a deliberate distinction.

### 2.2 Ownership map — implements book Table 20

| Mutex | Written by | Read by |
|---|---|---|
| `guard_temps` | `TaskTemp` | `TaskPLC`, `TaskSafety`, `TaskPWM_Boost` |
| `guard_flow` | `TaskFlow` | `TaskPLC`, `TaskSafety`, `TaskPWM_Boost` |
| `guard_current` | `TaskCurrent` | `TaskPLC`, `TaskSafety` |
| `guard_cmd` | `TaskPLC` | `TaskPWM_Internal`, `TaskPWM_Boost`, `TaskSafety` |

Each guard has exactly **one writer** and several readers. Single-writer
ownership means no write-write race is structurally possible.

### 2.3 Created before any task can run

[`slave/src/main.cpp:24-33`](https://github.com/AmitParan/smart-boiler/blob/d3754fe/slave/src/main.cpp#L24-L33)

```cpp
guard_temps   = xSemaphoreCreateMutex();
guard_flow    = xSemaphoreCreateMutex();
guard_current = xSemaphoreCreateMutex();
guard_cmd     = xSemaphoreCreateMutex();

if (!guard_temps || !guard_flow || !guard_current || !guard_cmd) {
    Serial.println("[FATAL] Failed to create mutexes - halting.");
    while (true) { vTaskDelay(pdMS_TO_TICKS(1000)); }
}
```

All four are created **before `xTaskCreatePinnedToCore` is called even once**, so
no task can ever observe a null handle. Allocation failure **halts the system**
rather than continuing unprotected — a boiler controller with broken mutual
exclusion must not run.

### 2.4 The access pattern: snapshot, release, then decide

[`slave/src/tasks/safety_task.cpp:29-38`](https://github.com/AmitParan/smart-boiler/blob/d3754fe/slave/src/tasks/safety_task.cpp#L29-L38)

```cpp
if (xSemaphoreTake(guard_temps,   pdMS_TO_TICKS(5)) == pdTRUE) {
    local_temps[0] = temps[0]; local_temps[1] = temps[1]; local_temps[2] = temps[2];
    xSemaphoreGive(guard_temps);
}
if (xSemaphoreTake(guard_flow,    pdMS_TO_TICKS(5)) == pdTRUE) {
    local_flow = current_flow; xSemaphoreGive(guard_flow);
}
```

Three properties worth noticing:

1. **Bounded wait.** Every take uses a 5 ms timeout, never `portMAX_DELAY`. The
   highest-priority safety task can never be blocked indefinitely by a lower one.
2. **Copy, then release.** Each mutex is held only for the duration of the copy —
   the safety logic runs afterwards on local copies, so it holds no lock while
   deciding.
3. **Never more than one guard is held at a time.** Verified across every task
   that touches a mutex (`plc_comms`, `safety_task`, `temp_task`, `flow_task`,
   `current_task`, both PWM tasks): each `xSemaphoreTake` is matched by its
   `xSemaphoreGive` before any other take — there is no nesting anywhere in the
   codebase. Without hold-and-wait, a deadlock cycle cannot form.

---

## 3. The wire protocol

### 3.1 A self-documenting frame

[`slave/src/config/boiler_protocol.h:15-21`](https://github.com/AmitParan/smart-boiler/blob/d3754fe/slave/src/config/boiler_protocol.h#L15-L21)

```
//  Wire frame layout (little-endian multi-byte fields):
//  [ 0xAA | LEN | TYPE | SEQ | ...payload... | CRC8 | 0x55 ]
//    ^                   |<--- LEN bytes --->|
//    start                                         end
//
//  CRC-8/SMBUS (poly 0x07) covers bytes [TYPE .. last payload byte].
```

This header is **byte-identical on master and slave** — a single shared
definition of truth for the link.

### 3.2 `#pragma pack(1)` — struct layout *is* the wire format

[`slave/src/config/boiler_protocol.h:58-66`](https://github.com/AmitParan/smart-boiler/blob/d3754fe/slave/src/config/boiler_protocol.h#L58-L66)

```cpp
//  #pragma pack(1) eliminates compiler padding → sizeof == wire size
#pragma pack(1)

struct BoilerStatusPacket_t {
    uint8_t  startByte;       // PROTO_START         = 0xAA
    uint8_t  length;          // STATUS_PAYLOAD_LEN  = 13
    uint8_t  packetType;      // PROTO_TYPE_STATUS   = 0x01
    uint8_t  sequence;        // rolling 0..255, receiver detects lost packets
    int16_t  tempInternal;    // tank temp [°C × 10]  e.g. 652 = 65.2 °C
```

Without `#pragma pack(1)` the compiler would insert padding to align `int16_t`
on a 2-byte boundary, and `sizeof(struct)` would no longer equal the number of
bytes on the wire — so a straight `memcpy` to the transport would send garbage.
Packing lets the struct be cast directly to a byte buffer and back.

**Temperatures are sent as `int16 × 10`, not `float`.** At 0.1 °C resolution that
is 2 bytes instead of 4, halving the payload. On the original power-line link —
roughly **100 bps effective** — that is not a micro-optimisation, it is the
difference between meeting the 1 packet/second budget and missing it.

### 3.3 A real packet, decoded

This is an actual 17-byte STATUS frame captured from the running system
(`[M<-S] seq=222 | t1=25.0 t2=23.0 t3=26.0 | flow=0.0 pwr=2499W | sts=0x02`):

```
AA 0D 01 DE FA 00 E6 00 04 01 00 00 C3 09 02 52 55
```

| Bytes | Field | Value | Meaning |
|---|---|---|---|
| `AA` | startByte | 0xAA | frame start |
| `0D` | length | 13 | payload length |
| `01` | packetType | STATUS | slave → master |
| `DE` | sequence | 222 | rolling counter |
| `FA 00` | tempInternal | 250 | **25.0 °C** (little-endian, ÷10) |
| `E6 00` | tempBoilerOut | 230 | 23.0 °C |
| `04 01` | tempBoostOut | 260 | 26.0 °C |
| `00 00` | flowRate | 0 | 0.0 L/min |
| `C3 09` | powerWatts | 2499 | 2499 W |
| `02` | statusByte | `0b00000010` | `STATUS_INTERNAL_ON` |
| `52` | crc8 | 0x52 | CRC-8/SMBUS over bytes 2–14 |
| `55` | endByte | 0x55 | frame end |

You can verify the CRC yourself against
[`proto_crc8()`](https://github.com/AmitParan/smart-boiler/blob/d3754fe/slave/src/config/boiler_protocol.h#L102-L113),
and you can capture your own frames live — see §5.3.

---

## 4. The transport abstraction

The master↔slave link runs over **Power Line Communication** (KQ-330 modems on
the 220 VAC wiring) by default, with **WiFi (UDP)** available as a build option.
The strongest argument for the abstraction is what the two implementations look
like next to each other. **Same signature, same bytes in, same bytes out.**

### 4.1 Sending a frame — two worlds

<table>
<tr><th>PLC — KQ-330 over UART (default)</th><th>WiFi — UDP (option)</th></tr>
<tr><td>

```cpp
void link_send(const uint8_t* data,
               uint8_t len) {
    for (uint8_t i = 0u; i < len; i++) {
        Serial1.write(data[i]);
        delay(KQ330_INTER_BYTE_DELAY_MS);
    }
}
```

</td><td>

```cpp
void link_send(const uint8_t* data,
               uint8_t len) {
    if (!link_ready()) return;
    IPAddress dst = /* peer or broadcast */;
    udp.beginPacket(dst, PORT);
    udp.write(data, len);
    udp.endPacket();
}
```

</td></tr>
</table>

[`link_plc.cpp:60-65`](https://github.com/AmitParan/smart-boiler/blob/d3754fe/slave/src/comms/link_plc.cpp#L60-L65) · [`link_wifi.cpp:96-110`](https://github.com/AmitParan/smart-boiler/blob/d3754fe/slave/src/comms/link_wifi.cpp#L96-L110)

The PLC version must pace **every single byte** with a 2 ms gap — established by
measurement, because a bulk write made the modem silently drop the last 3–4
bytes. UDP needs none of that: the network stack already preserves message
boundaries.

### 4.2 Receiving — the asymmetry is even sharper

| | PLC | WiFi |
|---|---|---|
| Frame reassembly | **5-state machine**, byte by byte | none — a datagram *is* a frame |
| Byte-gap timeout | 2000 ms, discards partial frames | not applicable |
| Half-duplex guard | 200 ms after RX before TX | not applicable — UDP is full duplex |
| Lines of code | ~75 | ~20 |

Roughly 55 lines of `link_plc.cpp` exist **solely** to cope with the physical
behaviour of a power-line modem. Isolating them behind
[`link.h`](https://github.com/AmitParan/smart-boiler/blob/d3754fe/slave/src/comms/link.h)
is what lets the WiFi option exist **without a single transport-specific line**
in `SystemManager`, the demo scenarios, the UI, or any slave task.

### 4.3 The whole interface

[`slave/src/comms/link.h:22-42`](https://github.com/AmitParan/smart-boiler/blob/d3754fe/slave/src/comms/link.h#L22-L42) *(doc comments elided for brevity — see the file)*

```cpp
void        link_begin();                                   // bring transport up
bool        link_ready();                                   // usable?
void        link_service();                                 // housekeeping
void        link_send(const uint8_t* data, uint8_t len);    // send one frame
uint8_t     link_poll(uint8_t* buf, uint8_t maxlen);        // receive one frame
const char* link_name();                                    // "PLC" / "WiFi"
```

Six functions. Selected at build time by a single flag, identical on both sides:

```ini
build_flags =
    ; -DLINK_WIFI    ; flag absent (default) -> KQ-330 power-line modem
                     ; uncomment             -> WiFi (UDP)
```

---

## 5. Verify every claim yourself

Nothing above has to be taken on trust.

### 5.1 Watch the safety watchdog cut the heaters (2 minutes)

Flash both boards, open both serial monitors, and let the demo reach
**Scenario 6 — Communication Loss**. The master deliberately stops transmitting.
Within 5 seconds the slave prints:

```
[SLAVE] ⚠️ NO CMD RECEIVED FOR 5s! TaskSafety TRIGGERED HARD-CUTOFF!
```

and both SSRs go off. That is §1.4 executing. **Scenario 8** does the same for
the stuck-SSR detector of §1.3, and **Scenario 7** for the 80 °C cutoff.

### 5.2 Prove the transport abstraction is real (2 minutes)

The default build uses the power-line transport. Uncomment `-DLINK_WIFI` in
**both** `platformio.ini` files and rebuild — both projects compile onto WiFi
with no source changes:

| | PLC (default) | WiFi (option) |
|---|---|---|
| Slave flash | 297,125 B (22.7 %) | 988,089 B (75.4 %) |
| Master flash | 2,034,762 B (31.0 %) | 2,043,126 B (31.2 %) |

The ~690 KB difference on the slave is the WiFi stack — the application code is
unchanged.

### 5.3 Capture real packets (1 minute)

Both firmwares print every frame they send and receive (`[M->S]`, `[S<-M]`,
`[S->M]`, `[M<-S]`) on the serial monitor. With the WiFi option you can also
sniff the link from a PC, from the repository root:

```bash
python tools/udp_link_probe.py listen
```

Every STATUS frame is printed as hex and ASCII. Decode one
against the table in §3.3 — the temperatures, the power reading and the status
bits will match what the two serial monitors are printing at that moment.

### 5.4 Prove the firmware reorganisation changed nothing

The folder restructuring was verified by rebuilding and comparing binaries: the
slave firmware is **byte-identical** before and after the move (988,089 bytes).
The master differs by exactly 4 bytes, because `CORE_DEBUG_LEVEL=1` embeds
`__FILE__` paths in log strings and those paths changed.

---

## Where to go next

| Question | File |
|---|---|
| What decides when the heater turns on? | [`master/src/control/SystemManager.cpp`](master/src/control/SystemManager.cpp) |
| How does the system learn shower times? | [`master/src/control/smart_preheat.cpp`](master/src/control/smart_preheat.cpp) |
| How are the 8 scenarios scripted? | [`master/src/demo/demo_scenarios.cpp`](master/src/demo/demo_scenarios.cpp) |
| Which GPIO is what? | [`slave/src/config/config.h`](slave/src/config/config.h) · [`master/src/config/config.h`](master/src/config/config.h) |
| Full system overview | [`README.md`](README.md) |

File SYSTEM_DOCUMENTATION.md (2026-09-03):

# Smart Boiler System — Documentation
**Last updated: May 9, 2026**
**Status: PLC communication ✅ | Temp sensor ✅ | Flow sensor ✅ | FreeRTOS refactor 🔄**

---

## Hardware Overview

### Master Unit — ESP32-S3 (5-inch touchscreen)
- **Board:** VIEWE UEDX80480050E-WB-A
- **Display:** 800×480 RGB IPS, ST7262 driver
- **Touch:** GT911 I2C
- **USB:** COM6 on work (Intel) laptop
- **Role:** UI display, user control, sends commands to slave every second

### Slave Unit — ESP32-C6 (PCB)
- **Board:** esp32-c6-devkitc-1
- **CPU:** RISC-V, single-core (Core 0 only — important!)
- **USB:** COM8 on personal computer
- **Role:** Reads sensors, controls SSRs, reports status to master

### KQ-330 PLC Modems (×2)
- **Protocol:** UART over 220V power line
- **Baud rate:** 9600
- **Effective throughput:** ~100 bps
- **Requirement:** Both modems must be on the same electrical circuit (same breaker)

---

## Wiring

### Master (ESP32-S3) ↔ KQ-330 Modem
| Signal | ESP32-S3 GPIO | KQ-330 Pin |
|---|---|---|
| TX (master sends) | GPIO17 | RX |
| RX (master receives) | GPIO13 | TX |

> **Note:** GPIO4/5 = RGB display data, GPIO10 = SD card CS, GPIO18 = Touch INT — all occupied. GPIO13 (SD MISO) and GPIO17 are free.

### Slave (ESP32-C6) ↔ KQ-330 Modem
| Signal | ESP32-C6 GPIO | KQ-330 Pin |
|---|---|---|
| TX (slave sends) | GPIO11 | RX |
| RX (slave receives) | GPIO10 | TX |

### Slave Sensors
| Sensor | GPIO | Status | Notes |
|---|---|---|---|
| DS18B20 temp bus | GPIO7 | ✅ Working | Up to 3 sensors on one wire, 10-bit resolution |
| YF-B6 flow sensor | GPIO6 | ✅ Working | Interrupt-driven pulse counter |
| ACS758 current sensor | GPIO3 | ⚠️ Calibrated, not load-tested | Boot auto-calibrates VREF and sensitivity from actual VCC |
| SSR Internal heater | GPIO4 | ❌ Not yet tested | PWM output — needs LED/lamp test |
| SSR Boost heater | GPIO5 | ❌ Not yet tested | PWM output — needs flow confirmed first |

---

## Software Architecture

### Repository
- **URL:** https://github.com/AmitParan/smart-boiler.git
- **Production branch:** `main_master_slave` — everything verified and working
- **Active development branches:**
  - `freertos-refactor` — FreeRTOS architecture refactor (friend's work)
  - `feature/system-manager-v2` — future SystemManager improvements

### Master Project: `smart-boiler/master/`
Built and uploaded from **work (Intel) laptop** via PlatformIO.

Key files:
- `src/main.cpp` — setup, WiFi, NTP, FreeRTOS tasks
- `src/comms_master.cpp` — PLC task: sends CMD every 1s, waits up to 3s for STATUS
- `src/ui_manager.cpp` — LVGL UI
- `src/config.h` — pin definitions (RX=GPIO13, TX=GPIO17)
- `src/boiler_protocol.h` — shared binary protocol structs

### Slave Project: `smart-boiler/slave/`
Built and uploaded from **personal computer** via PlatformIO.

Key files:
- `src/main.cpp` — FreeRTOS task creation (all on Core 0)
- `src/plc_task.cpp` — request-response: receives CMD → sends STATUS
- `src/plc_comms.cpp` — state machine RX/TX, CRC-8
- `src/config.h` — all GPIO pin definitions
- `src/boiler_protocol.h` — shared binary protocol structs
- `src/shared_data.cpp/.h` — global sensor values shared between tasks
- `src/safety_task.cpp` — overheat, dry-fire, uncommanded current protection
- `src/current_task.cpp` — ACS758 RMS current with boot calibration
- `src/temp_task.cpp` — DS18B20 one-wire temperature
- `src/flow_task.cpp` — YF-B6 pulse counter
- `src/pwm_task_internal.cpp` — SSR PWM for internal heater
- `src/pwm_task_boost.cpp` — SSR PWM for boost heater

---

## Communication Protocol

### Transport
- Half-duplex UART over KQ-330 power-line carrier
- **Request-response:** master sends CMD → slave replies with STATUS
- No spontaneous transmissions from slave (prevents collision)
- 200ms guard delay on slave after CMD received before replying

### Packet Format
```
[0xAA] [LEN] [TYPE] [PAYLOAD...] [CRC8] [0x55]
```
- Start byte: `0xAA`
- End byte: `0x55`
- CRC: CRC-8/SMBUS (poly 0x07) over [TYPE + PAYLOAD]

### CMD Packet (master → slave): 9 bytes
```c
struct BoilerCmdPacket_t {
    uint8_t startByte;    // 0xAA
    uint8_t length;       // 5
    uint8_t packetType;   // 0x02
    uint8_t sequence;
    uint8_t pwmInternal;  // 0-100%
    uint8_t pwmBoost;     // 0-100%
    uint8_t cmdFlags;     // CMD_HEATER_ENABLE, CMD_BOOST_ENABLE, CMD_EMERGENCY_STOP
    uint8_t crc8;
    uint8_t endByte;      // 0x55
};
```

### STATUS Packet (slave → master): 17 bytes
```c
struct BoilerStatusPacket_t {
    uint8_t  startByte;      // 0xAA
    uint8_t  length;         // 13
    uint8_t  packetType;     // 0x01
    uint8_t  sequence;
    int16_t  tempInternal;   // °C × 10 fixed-point
    int16_t  tempBoilerOut;
    int16_t  tempBoostOut;
    uint16_t flowRate;       // L/min × 10
    uint16_t powerWatts;
    uint8_t  statusByte;     // STATUS_FAULT = 0x08
    uint8_t  crc8;
    uint8_t  endByte;        // 0x55
};
```

---

## Build & Upload Workflow

### Work Computer (master)
```bash
cd smart-boiler/master
# Edit code here
git add -A
git commit -m "description"
git push origin <branch>
# PlatformIO: Build → Upload → Monitor (COM6)
```

### Personal Computer (slave)
```bash
cd smart-boiler/slave
git pull origin feature/esp32-c6-toolchain-fix
# PlatformIO: Build → Upload → Monitor (COM8)
# DO NOT edit, commit or push from this computer
```

---

## FreeRTOS Architecture (freertos-refactor branch)

### What Changed
The monolithic task structure was refactored into a clean producer-consumer architecture using FreeRTOS queues (length=1, "latest value wins").

### Master Task Map
| Task | Priority | Core | Period | Role |
|---|---|---|---|---|
| TaskBrain | 3 (highest) | 1 | 250ms | Runs SystemManager, publishes CommandSnapshot |
| TaskMasterComms | 2 | 1 | 10ms poll / 1s TX | PLC send/receive |
| TaskUI | 2 | 1 | 10ms | LVGL render |
| TaskNetwork | 1 | 0 | event-driven | WiFi, NTP, weather |

### Slave Task Map
| Task | Priority | Core | Period | Role |
|---|---|---|---|---|
| TaskSafety | 4 (highest) | 0 | 50ms | Overheat, dry-fire, current protection |
| TaskPwmInternal | 3 | 0 | 50ms slices | SSR internal heater PWM |
| TaskPwmBoost | 3 | 0 | 50ms slices | SSR boost heater PWM |
| TaskFlow | 2 | 0 | 1000ms | YF-B6 pulse counter |
| TaskTemp | 2 | 0 | 1000ms | DS18B20 temperature |
| TaskCurrent | 2 | 0 | 500ms | ACS758 RMS current |
| TaskPLC | 2 | 0 | 10ms poll | PLC request-response |

### Shared State (Queue-based, thread-safe)
- **SensorSnapshot** — slave sensors → PLC task → master brain
- **CommandSnapshot** — master brain → PLC task → slave PWM tasks
- **UiSnapshot** — touchscreen UI → brain task

### Key Files Added
- `master/src/task_config.h` — all stack sizes, priorities, core affinity, timing constants
- `master/src/tasks/TaskBrain.cpp` — SystemManager wrapper task
- `master/src/shared/master_state.h/.cpp` — FreeRTOS queue wrappers
- `slave/src/task_config.h` — slave task configuration
- `slave/src/shared/slave_state.h/.cpp` — slave queue wrappers

---

## Hardware Files

PCB files are stored in `hardware/`:
```
hardware/
├── boiler.sch              ← Eagle schematic source
├── boiler.brd              ← Eagle board layout source
├── schematic.pdf           ← readable without Eagle
├── board-layout.pdf        ← readable without Eagle
├── gerbers/                ← 10 Gerber files (sent to JLCPCB)
├── drill/                  ← drill file
└── bom-cpl/                ← BOM + pick & place files for JLCPCB
```

Datasheets folder: `datasheets/` — component datasheets (to be added)

---

## Known Issues & Resolved Problems

| Problem | Root Cause | Fix |
|---|---|-----|
| xTaskCreatePinnedToCore assert crash | ESP32-C6 is single-core, code pinned to Core 1 | Changed all core IDs to 0 |
| Serial2 not declared | ESP32-C6 only has Serial0/Serial1 | Changed to Serial1 |
| `as.exe` CreateProcess failure on Intel laptop | CrowdStrike EDR quarantining RISC-V toolchain | Use personal computer for slave builds |
| OneWire library incompatible with ESP32-C6 | GPIO register structure changed | Use git HEAD of OneWire |
| ACS758 reading 2694W at idle | ADC default attenuation 0dB = max 0.8V, sensor output 1.6V → saturation | Added `ADC_11db`, boot calibration |
| PLC TX/RX collision (half-duplex) | Both sides transmitting simultaneously | Switched to request-response protocol |
| Master GPIO18 RX = 0 bytes | GPIO18 is Touch INT line, pulled by hardware | Moved to GPIO13 (SD MISO, unused) |
| Master GPIO10 RX = 0 bytes | GPIO10 is SD card CS | Moved to GPIO13 |

---

---

## Current Status (May 9, 2026)

### Hardware Testing
| Component | Status | Notes |
|---|---|---|
| PLC communication (master ↔ slave) | ✅ Verified | CMD every 1s, STATUS reply, CRC-8, sequence numbers |
| DS18B20 temperature sensors | ✅ Working | 3 sensors on one wire, 10-bit resolution |
| YF-B6 flow sensor | ✅ Working | Interrupt-driven pulse counter |
| ACS758 current sensor | ⚠️ Calibrated, not load-tested | Auto-calibrates VREF and sensitivity at boot |
| SSR internal heater | ❌ Not tested | Needs LED/lamp test before real load |
| SSR boost heater | ❌ Not tested | Flow interlock confirmed by safety task |
| Hardware safety circuit (LM393N, watchdog caps, BS170) | ❌ Not tested | Plan: disconnect NTC wire to trip thermal cutoff |

### Software
| Feature | Status | Notes |
|---|---|---|
| SystemManager state machine | ✅ Verified | 11/11 test scenarios PASS |
| UI dashboard | ✅ Working | Touch, ON/OFF, target temp, info bar |
| FreeRTOS architecture refactor | 🔄 In progress | `freertos-refactor` branch |
| Smart decision tree (user data collection) | ❌ Not started | See Roadmap below |
| PLC protocol documentation | ❌ Not written | See Roadmap below |
| Datasheets folder | ❌ Not added | |

---

## Roadmap

### Immediate (hardware)
- [ ] SSR test with LED on GPIO4/GPIO5 (control side, no 220V)
- [ ] SSR test with 220V indicator lamp (output side)
- [ ] Hardware safety circuit test (disconnect NTC wire to trip LM393N)
- [ ] Current sensor validation under real heater load

### Software — next features
- [ ] **PLC protocol documentation** — write full spec for the binary protocol: packet format, field encoding, CRC calculation, request-response timing, error handling. Store in `docs/plc-protocol.md`
- [ ] **Merge `freertos-refactor` → `main_master_slave`** — review changes, re-add hardware folder (was accidentally deleted in that branch)
- [ ] **Smart decision tree / user learning system:**
  - Collect usage patterns: time of day user turns boiler on, typical session duration, typical target temp
  - Store events in SPIFFS with timestamp (on/off, temp set, flow detected)
  - After enough data: predict when user normally showers and pre-heat automatically
  - V1: simple schedule learning (store last 7 days, find repeating pattern)
  - V2: adaptive PID — adjust pre-heat lead time based on measured heat-up rate
- [ ] Persist `target_temperature` to SPIFFS (resets to 60°C on reboot)
- [ ] Move weather API key from `ui_manager.cpp` to `secrets.h` (security)

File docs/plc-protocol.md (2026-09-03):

# Smart Boiler — PLC Communication Protocol

**Version:** 1.0  
**Last updated:** May 9, 2026  
**Status:** Production — verified end-to-end ✅

---

## 1. Physical Layer

### Hardware
The two ESP32 units do not talk directly to each other over wire. Instead, they communicate through **KQ-330 PLC modems** that carry the signal over the existing 220V power line in the building.

```
[Master ESP32-S3] ──UART──► [KQ-330 Modem] ──220V power line──► [KQ-330 Modem] ──UART──► [Slave ESP32-C6]
```

### UART Settings (MCU ↔ Modem)
| Parameter | Value |
|---|---|
| Baud rate | 9600 bps |
| Data bits | 8 |
| Parity | None |
| Stop bits | 1 |
| Mode | Half-duplex (one side transmits at a time) |

### Effective Throughput
The KQ-330 modem over the power line achieves approximately **100 bps** effective throughput — much slower than the 9600 bps UART. This means packets must be sent slowly and infrequently to avoid overflowing the modem buffer.

**Rule: Maximum 1 packet per second. Never send bursts.**

### Master Pin Connections (ESP32-S3)
| Signal | GPIO |
|---|---|
| TX (master → modem) | GPIO17 |
| RX (modem → master) | GPIO13 |

### Slave Pin Connections (ESP32-C6)
| Signal | GPIO |
|---|---|
| TX (slave → modem) | GPIO11 |
| RX (modem → slave) | GPIO10 |

---

## 2. Communication Pattern

### Request-Response (Half-Duplex)
Because the power line is shared and the modem is half-duplex, only one side can transmit at a time. The protocol uses a strict **master-initiated request-response** pattern:

```
Master                          Slave
  │                               │
  │──── CMD packet ──────────────►│  (master sends every 1 second)
  │                               │  (slave waits 200ms guard delay)
  │◄─── STATUS packet ────────────│  (slave replies with sensor data)
  │                               │
  │  (master waits up to 3 seconds for STATUS)
  │  (if no reply → PLC link timeout → SAFETY_OVERRIDE)
  │                               │
```

**Why 200ms guard delay on slave?**  
The modem needs time to switch from receive mode to transmit mode after the last byte of the CMD arrives. Without this delay, the first bytes of the slave's reply collide with the modem's tail. 200ms was found to work reliably in testing.

**Why 3 second timeout on master?**  
At 100 bps effective throughput, a 17-byte STATUS packet takes ~1.4 seconds to arrive. 3 seconds allows one full CMD-STATUS cycle plus margin.

---

## 3. Packet Frame Format

Every packet, regardless of direction, follows this frame layout:

```
Byte index:  0      1      2      3      4 ... N    N+1    N+2
             ┌──────┬──────┬──────┬──────┬─────────┬──────┬──────┐
             │ 0xAA │ LEN  │ TYPE │ SEQ  │ PAYLOAD │ CRC8 │ 0x55 │
             └──────┴──────┴──────┴──────┴─────────┴──────┴──────┘
               Start  Len   Type   Seq   Data...    CRC   End
```

| Field | Size | Description |
|---|---|---|
| `startByte` | 1 byte | Always `0xAA` — marks packet start |
| `length` | 1 byte | Number of payload bytes (TYPE + SEQ + data fields) |
| `packetType` | 1 byte | `0x01` = STATUS, `0x02` = CMD |
| `sequence` | 1 byte | Rolling counter 0–255, wraps around. Receiver uses this to detect lost packets |
| payload | variable | Sensor data or commands (see below) |
| `crc8` | 1 byte | Error check — covers bytes from TYPE through last payload byte |
| `endByte` | 1 byte | Always `0x55` — marks packet end |

**What the CRC covers:**  
CRC-8 is calculated over `[TYPE, SEQ, all payload fields]`. The `startByte`, `length`, `crc8`, and `endByte` themselves are NOT included in the CRC calculation.

---

## 4. CRC-8 Algorithm

**Algorithm:** CRC-8/SMBUS  
**Polynomial:** 0x07  
**Initial value:** 0x00  
**No input/output reflection**

```c
uint8_t crc8(const uint8_t* data, uint8_t len) {
    uint8_t crc = 0x00;
    for (uint8_t i = 0; i < len; i++) {
        crc ^= data[i];
        for (uint8_t b = 0; b < 8; b++) {
            if (crc & 0x80)
                crc = (crc << 1) ^ 0x07;
            else
                crc = crc << 1;
        }
    }
    return crc;
}
```

**Example:**  
For a STATUS packet, the CRC input starts at byte index 2 (the `packetType` byte) and covers 13 bytes (STATUS_PAYLOAD_LEN = 13).

---

## 5. CMD Packet (Master → Slave)

**Direction:** Master sends to Slave  
**Frequency:** Once per second  
**Total wire size:** 9 bytes  
**Payload length (LEN field):** 5

### Byte Layout
```
Byte  0:  0xAA          startByte
Byte  1:  0x05          length = 5
Byte  2:  0x02          packetType = CMD
Byte  3:  sequence      rolling 0–255
Byte  4:  pwmInternal   0–100 (percent duty cycle for internal heater SSR)
Byte  5:  pwmBoost      0–100 (percent duty cycle for boost heater SSR)
Byte  6:  cmdFlags      bitmask (see flags below)
Byte  7:  crc8          CRC over bytes 2–6
Byte  8:  0x55          endByte
```

### CMD Flags (Byte 6)
| Bit | Constant | Meaning |
|-----|---|---|
| Bit 0 | `CMD_HEATER_ENABLE` | Allow internal tank heater to run |
| Bit 1 | `CMD_BOOST_ENABLE` | Allow boost inline heater to run |
| Bit 7 | `CMD_EMERGENCY_STOP` | Cut both SSRs immediately — overrides everything |

### Example CMD (heating tank at 100%, no boost)
```
AA 05 02 2A 64 00 01 XX 55
│  │  │  │  │  │  │  │  └─ end
│  │  │  │  │  │  │  └──── CRC
│  │  │  │  │  │  └─────── cmdFlags = 0x01 (HEATER_ENABLE)
│  │  │  │  │  └────────── pwmBoost = 0 (off)
│  │  │  │  └───────────── pwmInternal = 100 (100%)
│  │  │  └──────────────── sequence = 42
│  │  └─────────────────── type = 0x02 (CMD)
│  └────────────────────── length = 5
└───────────────────────── start = 0xAA
```

---

## 6. STATUS Packet (Slave → Master)

**Direction:** Slave sends to Master  
**Frequency:** Once per second (after receiving CMD)  
**Total wire size:** 17 bytes  
**Payload length (LEN field):** 13

### Byte Layout
```
Byte  0:  0xAA          startByte
Byte  1:  0x0D          length = 13
Byte  2:  0x01          packetType = STATUS
Byte  3:  sequence      rolling 0–255
Byte  4–5: tempInternal  int16, tank temperature [°C × 10]
Byte  6–7: tempBoilerOut int16, boiler outlet temperature [°C × 10]
Byte  8–9: tempBoostOut  int16, boost outlet temperature [°C × 10]
Byte 10–11: flowRate     uint16, flow rate [L/min × 10]
Byte 12–13: powerWatts   uint16, instantaneous power [W]
Byte 14:  statusByte    bitmask (see flags below)
Byte 15:  crc8          CRC over bytes 2–14
Byte 16:  0x55          endByte
```

### Fixed-Point Encoding
Temperatures and flow are stored as integers multiplied by 10 to preserve one decimal place without using floating-point on the wire:

| Field | Encoding | Example |
|---|---|---|
| Temperature | int16 × 10 | 65.2°C → stored as `652` (0x028C) |
| Flow rate | uint16 × 10 | 7.5 L/min → stored as `75` (0x004B) |
| Power | uint16, no scaling | 3000W → stored as `3000` (0x0BB8) |

**Byte order:** Little-endian (ESP32 native). Low byte first.

### STATUS Flags (Byte 14)
| Bit | Constant | Meaning |
|-----|---|---|
| Bit 0 | `STATUS_FLOW_ACTIVE` | Water is flowing (flow ≥ 1.0 L/min) |
| Bit 1 | `STATUS_INTERNAL_ON` | Internal tank SSR is energised |
| Bit 2 | `STATUS_BOOST_ON` | Boost inline SSR is energised |
| Bit 3 | `STATUS_FAULT` | A safety fault is currently active |

### Example STATUS (cold tank, no flow, no load)
```
AA 0D 01 5A 00 C8 00 BE 00 BE 00 00 00 00 00 XX 55
│  │  │  │  ├──┤  ├──┤  ├──┤  ├────┤  ├────┤ │  │
│  │  │  │  │200│  190   190    0      0     │ │  │
│  │  │  │  └─20.0°C     19.0°C  0L/m   0W  │ │  │
│  │  │  └── sequence = 90                    │ │  │
│  │  └────── type = 0x01 (STATUS)            │ │  │
│  └───────── length = 13                     │ └─end
└──────────── start = 0xAA               CRC─┘
```

---

## 7. Sequence Numbers and Loss Detection

Both CMD and STATUS packets carry a 1-byte rolling sequence counter (0–255, wraps to 0 after 255).

**Master** increments its TX sequence on every CMD sent.  
**Slave** increments its TX sequence on every STATUS sent.

The receiver checks if the incoming sequence is `(last_received + 1) mod 256`. If not, it logs a packet loss warning:
```
[COMMS RX] Packet loss: expected seq 91 got 0
```

This is **non-fatal** — the receiver accepts the packet anyway and updates its last-seen sequence. The sequence counter resets to 0 when either ESP32 reboots, which also appears as a "loss" in the log on the first packet after restart.

---

## 8. Error Handling

| Error | Detection | Action |
|---|---|---|
| Bad CRC | Calculated CRC ≠ received CRC | Packet discarded, logged |
| Wrong packet type | Slave receives its own CMD echo | Ignored (logged as "Own CMD echo ignored") |
| Unknown packet type | Unexpected type byte | Discarded, logged |
| Short/corrupted frame | Bad end byte `0x55` | Discarded, logged |
| RX timeout (mid-packet) | No new byte for 200ms | State machine resets to WAIT_START |
| PLC link timeout | No STATUS received within 3s | Master → `SAFETY_OVERRIDE`, UI shows "No Signal" |

---

## 9. SystemManager — How CMD Values Are Decided

The master does not just forward user input to the slave. It runs a state machine called **SystemManager** which calculates the correct `pwmInternal`, `pwmBoost`, and `cmdFlags` based on sensor data and UI state.

### States (priority order, highest first)
| Priority | State | Condition | pwmInternal | pwmBoost |
|---|---|---|---|---|
| 1 | `SAFETY_OVERRIDE` | No PLC link OR tank ≥ 85°C | 0 | 0 |
| 2 | `STATE_OFF` | User pressed OFF on UI | 0 | 0 |
| 3 | `STATE_SHOWER_BOOST` | Flow > 0.5 L/min | 0 | 100 |
| 4 | `STATE_HEATING_TANK` | Tank temp < 40°C | 100 | 0 |
| 5 | `STATE_STANDBY` | Tank temp ≥ 40°C, no flow | 0 | 0 |

### Dual-Target Energy Saving Philosophy
- Internal heater only maintains the tank at **40°C** (base temperature — low standing heat loss)
- Boost heater fires **only when tap is open** (flow detected), bringing water up to shower temperature
- **Both heaters never run simultaneously** — prevents tripping the 16A breaker with two 3000W elements

---

## 10. Serial Monitor Log Format

When running normally (TEST_MODE 0), the master prints one line per cycle:

```
[MASTER] seq=183  tInt=20.0 flow=0.0 pwr=2000W  ->  pwmInt=100% pwmBst=0% [STATE_HEATING_TANK]
```

Fields: sequence number, tank temperature, flow rate, power measured by slave, then the decision: internal PWM, boost PWM, state name.

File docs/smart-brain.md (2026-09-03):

# Smart Boiler — Decision Tree & Learning Brain

**Version:** 1.1  
**Last updated:** May 9, 2026  
**Status:** Design phase — not yet implemented

---

## 1. Why a Smart Brain?

Today the boiler is **reactive** — the user presses ON, waits for the tank to heat up (~20–30 min from cold), then showers. This wastes time and energy.

The goal of the Smart Brain is to make the boiler **predictive**:
- Learn when the user showers every day
- Pre-heat automatically so hot water is ready when the user arrives
- Save energy by heating only to the base 40°C during idle and boosting only during actual flow
- Adapt over time as habits change

This is not AI — it is a **deterministic decision tree** built on accumulated usage data. Simple, transparent, and auditable.

---

## 2. Data the System Already Has

The slave measures and reports every second:

| Data | Source | Resolution |
|---|---|---|
| Tank temperature | DS18B20 | 0.1°C |
| Flow rate | YF-B6 | 0.1 L/min |
| Power consumption | ACS758 current | ~1W |
| Boiler state (ON/OFF) | UI touch | boolean |
| Target shower temperature | UI slider | 1°C steps |

The master also has:
- **Real-time clock** (NTP synced) → exact timestamp for every event
- **WiFi** → can report data or receive updates
- **SPIFFS flash storage** → can persist data across reboots
- **Weather API** (OpenWeatherMap, fetched every 10 min) → outdoor temperature, forecast, cloud cover, UV index

### What Weather Data Gives Us
The outdoor temperature directly affects how much heating work the system needs to do:

| Condition | Effect on system |
|---|---|
| Hot summer day (35°C+) | Pipes and inlet water warm naturally — boost gap is smaller, start later |
| Cold winter morning (5°C) | Inlet water is cold — need more heating, start earlier |
| Sunny forecast | Solar gain on pipes/tank — may reduce required lead time |
| Cloud cover | No passive solar help — use full lead time |

The system already fetches `temp`, `weather description`, and forecast from OpenWeatherMap. The brain will use this to adjust the pre-heat start time dynamically.

---

## 3. Event Model

Everything the brain learns comes from **events**. An event is a timestamped record of something that happened.

### Event Types

```c
enum class BoilerEvent : uint8_t {
    USER_ON        = 0x01,  // user pressed ON on touchscreen
    USER_OFF       = 0x02,  // user pressed OFF
    FLOW_START     = 0x03,  // flow sensor crossed threshold (tap opened)
    FLOW_STOP      = 0x04,  // flow dropped to zero (tap closed)
    TEMP_SET       = 0x05,  // user changed target shower temperature
    AUTO_PREHEAT   = 0x06,  // system auto-started pre-heat (brain decision)
    TANK_READY     = 0x07,  // tank reached target temperature
    TARGET_TIME_SET = 0x08, // user set a fixed ready-by time
    WEATHER_ADJUST  = 0x09, // brain adjusted lead time due to weather
};

struct BoilerEventRecord {
    uint32_t  unixTimestamp;   // seconds since epoch (from NTP)
    BoilerEvent type;
    int16_t   valueX10;        // context: temp × 10, or flow × 10, or 0
};
```

### Event Storage
Events are appended to a circular log in SPIFFS: `events.bin`

- Each record: 7 bytes
- Target log size: 7 days × ~50 events/day × 7 bytes = ~2.5 KB (well within SPIFFS)
- When full: oldest records overwritten (circular buffer)

---

## 4. What the Brain Learns

### V1 — Daily Schedule Detection

**Question:** "At what time does this user typically open the tap?"

**Method:**
1. Every time a `FLOW_START` event is logged, extract the time-of-day (hour + minute)
2. Keep a histogram: 24 hours × 4 quarter-slots = 96 buckets, each storing a count
3. After 7 days of data, find the bucket with the highest count → that is the predicted shower time
4. If the top bucket has ≥ 3 hits (out of 7 days) → pattern is considered reliable
5. Schedule a pre-heat alarm: fire `AUTO_PREHEAT` N minutes before that time

**Example histogram (simplified):**
```
06:00–06:15  ████████ 8   ← peak, user showers here
06:15–06:30  ██ 2
07:00–07:15  ███ 3
19:00–19:15  █ 1
```
→ Schedule auto pre-heat at 05:40 (20 min lead time)

### V3 — Weather-Adjusted Lead Time

**Question:** "Given today's outdoor temperature, how much of the heating work can nature do for free?"

**How it works:**

The cold water entering the boiler is not always the same temperature. In summer, pipes sitting in the sun warm up to 25–30°C. In winter, groundwater and shaded pipes may be 12–15°C. This directly changes how much energy the heater needs to add.

The brain uses the outdoor temperature from the weather API as a proxy for inlet water temperature:

```
inlet_temp_estimate = BASE_INLET_TEMP + (outdoor_temp - 20°C) × PIPE_FACTOR
```

Where `BASE_INLET_TEMP` = 18°C (calibrated from observed tank cool-down rate), `PIPE_FACTOR` = 0.3 (empirical — pipes don't track outdoor temp 1:1).

**Effect on lead time:**
```
Warm day (32°C outdoor):  inlet ≈ 21.6°C  → gap to 55°C = 33.4°C  → lead time: 14 min
Cold day (8°C outdoor):   inlet ≈ 15.6°C  → gap to 55°C = 39.4°C  → lead time: 19 min
```

The system logs a `WEATHER_ADJUST` event every time it changes the pre-heat start time based on weather, so you can audit it.

**Sunny day bonus (cloud cover < 20%):**  
If the forecast shows clear sky AND outdoor temp > 28°C, the system adds an extra 5-minute delay before starting pre-heat (passive solar may do part of the work first). It monitors whether the tank temp rises on its own — if it does, it delays further. If not, it starts normally.

---

### V4 — User-Defined Target Time (Fixed Schedule Override)

**Question:** "What if the user already knows exactly when they want hot water?"

The learning system is powerful but takes 7 days. Some users just want to set a time. This feature gives them that — and the brain still makes it energy-optimal.

**How it works:**

The user sets a "ready-by" time on the touchscreen — for example, `07:00`. The brain then:

1. Reads the current tank temperature
2. Reads the target shower temperature (from UI slider)
3. Estimates the heat-up gap: `gap = target_temp - tank_temp`
4. Looks up the rolling average lead time from history (or uses default 20 min if no history)
5. Adjusts lead time for today's weather (V3 logic above)
6. Calculates: `start_time = ready_by_time - adjusted_lead_time`
7. Waits until `start_time`, then turns boiler ON

**Example:**
```
User sets ready-by: 07:00
Current tank: 40°C  →  target: 55°C  →  gap: 15°C
Rolling average heat-up: 18 min
Weather today: 30°C outdoor → inlet warm → adjust: -3 min
Adjusted lead time: 15 min
System starts at: 06:45
```

**Per-day-of-week schedule:**  
Users can set different times for weekdays vs weekends:
```
Mon–Fri: ready at 07:00
Sat–Sun: ready at 09:00
```

**Target time + learned schedule interaction:**
- If user has set a fixed time → fixed time takes priority, learning supplements it
- If no fixed time is set → learned histogram drives the schedule
- If both predict the same window → confirm the pattern, no change
- If they conflict → fixed time wins, log the conflict for the user to see

**Energy optimization with fixed time:**  
The system does not simply turn ON at the calculated start time and wait. It monitors the tank temperature in real time:
```
start_time = 06:45

06:45: tank = 40°C → turn ON (internal heater 100%)
06:52: tank = 48°C → still heating
06:58: tank = 54°C → almost there, slow down (reduce to 60% PWM if near target)
07:00: tank = 55°C → TANK_READY event logged, heater OFF, standby
```
This prevents overshooting (wasted energy heating beyond the target).

---

### V2 — Adaptive Lead Time

**Question:** "How many minutes does THIS boiler take to heat from 40°C to shower temperature?"

**Method:**
1. Every time the user presses ON, record: `[timestamp, tank_temp_at_start, target_temp]`
2. When `TANK_READY` fires, record: `[timestamp]`
3. Compute: `heat_up_minutes = (TANK_READY.time - USER_ON.time) / 60`
4. Store the last 5 heat-up durations, compute rolling average
5. Use this as the pre-heat lead time instead of a fixed 20 minutes

**Example:**
```
Session 1: cold tank 20°C → 60°C took 28 min
Session 2: warm tank 38°C → 60°C took 12 min
Session 3: cold tank 22°C → 60°C took 26 min
Rolling average: 22 min → use 25 min lead time (with 3 min safety margin)
```

### V3 — Multi-User / Weekend Detection (future)
- Detect different patterns for weekdays vs weekends
- Detect second user (second daily flow peak)
- Adjust schedule per day-of-week

---

## 5. Decision Tree

Every 60 seconds, the brain evaluates this tree:

```
START
  │
  ├─ Is system_fault active?
  │     └─ YES → do nothing, wait for reboot
  │
  ├─ Is user currently ON (manual)?
  │     └─ YES → let SystemManager handle it normally, log events
  │
  ├─ Is schedule learning enabled? (user setting)
  │     └─ NO → do nothing
  │
  ├─ Do we have ≥ 7 days of data?
  │     └─ NO → keep logging, build histogram
  │
  ├─ Is the pattern reliable? (top bucket ≥ 3 hits)
  │     └─ NO → keep logging
  │
  ├─ Is now within [predicted_time - lead_time] window?
  │     └─ NO → do nothing
  │
  └─ YES → fire AUTO_PREHEAT
             │
             ├─ Turn boiler ON (set boiler_state = true)
             ├─ Log AUTO_PREHEAT event
             └─ Wait for FLOW_START
                   │
                   ├─ FLOW_START received → normal operation continues
                   └─ No FLOW_START after 90 min → turn OFF, log anomaly
```

---

## 6. Data Persistence — SPIFFS Layout

```
/events.bin       ← circular event log (7-byte records)
/histogram.bin    ← 96-bucket time-of-day histogram (uint16 per bucket)
/heatup.bin       ← last 5 heat-up durations in minutes (uint8 per entry)
/settings.bin     ← user preferences (schedule on/off, lead time override)
```

All files survive power cuts and reboots. The `DataManager` class already handles SPIFFS reads/writes — the brain will use the same pattern.

---

## 7. UI Integration

The master touchscreen needs to show the brain's state and allow the user to control it:

### New UI elements needed
| Element | Location | Purpose |
|---|---|---|
| "Auto" indicator | Top bar | Shows when auto pre-heat is active |
| Schedule card | Right panel | Shows predicted shower time and lead time |
| **"Ready By" time picker** | Settings screen | User sets fixed target time (hour:min, per weekday/weekend) |
| **Weather influence indicator** | Schedule card | Shows "☀️ Adjusted -3 min" or "❄️ Adjusted +4 min" |
| Learning progress | Settings screen | "Learning: Day 4 of 7" |
| Override button | Schedule card | "Disable auto today" |
| History graph | Settings screen | Bar chart of shower times this week |

---

## 8. Implementation Plan

### Phase 1 — Event logging (no decisions yet)
- [ ] Define `BoilerEventRecord` struct in `master/src/brain/event_log.h`
- [ ] Write `EventLog` class: `append()`, `readAll()`, circular SPIFFS file
- [ ] Hook into `ui_manager.cpp`: log `USER_ON`, `USER_OFF`, `TEMP_SET`
- [ ] Hook into `comms_master.cpp`: log `FLOW_START`, `FLOW_STOP`, `TANK_READY`
- [ ] Verify events appear in serial monitor and survive reboot

### Phase 2 — Histogram and pattern detection
- [ ] Define `ShowerHistogram` class: 96 buckets, `increment()`, `findPeak()`, `isReliable()`
- [ ] After each `FLOW_START` event: update histogram
- [ ] Persist histogram to SPIFFS on every update
- [ ] Add serial log: `[BRAIN] Peak shower slot: 06:00 (8 hits)`

### Phase 3 — Auto pre-heat
- [ ] Add `BrainTask` (FreeRTOS, Core 1, runs every 60s)
- [ ] Implement the decision tree above
- [ ] Wire to `boiler_state` — brain can turn ON just like the user can
- [ ] Add `AUTO_PREHEAT` event logging
- [ ] Add 90-minute watchdog: if no flow after auto start → turn OFF

### Phase 4 — Adaptive lead time
- [ ] Track heat-up duration per session
- [ ] Store rolling average in `heatup.bin`
- [ ] Replace fixed 20-min lead time with measured average + 3 min margin

### Phase 5 — Weather adjustment
- [ ] Wire OpenWeatherMap outdoor temp into the brain (already fetched in `ui_manager.cpp`)
- [ ] Implement `inlet_temp_estimate()` function
- [ ] Adjust lead time based on estimated inlet temperature
- [ ] Add sunny-day passive delay logic (cloud cover check)
- [ ] Log `WEATHER_ADJUST` events

### Phase 6 — User-defined target time
- [ ] Add "Ready By" time picker to settings screen (hour + minute, per weekday/weekend)
- [ ] Persist target times to `settings.bin` in SPIFFS
- [ ] Brain reads target time on startup and after UI change
- [ ] Implement back-calculation: `start_time = ready_by - adjusted_lead_time`
- [ ] Implement real-time temperature monitoring during heat-up (prevent overshoot)
- [ ] Handle conflict between fixed time and learned histogram

### Phase 7 — UI
- [ ] Add schedule card to right panel
- [ ] Add learning progress indicator
- [ ] Add settings screen with on/off toggle

---

## 9. Key Design Decisions

**Why SPIFFS and not a server?**  
The system must work without internet. All learning happens on-device. WiFi is optional (weather, OTA updates) — not required for the core intelligence.

**Why not a neural network or ML model?**  
Overkill for this problem. A histogram of 96 time slots is deterministic, explainable, and uses 192 bytes of storage. A TensorFlow model would need megabytes and still do the same job.

**Why 7 days minimum before acting?**  
A single data point is not a pattern. 7 days catches weekly habits (different weekend vs weekday behaviour) and avoids false triggers from one unusual day.

**What if the user's schedule changes?**  
The histogram uses a sliding window — events older than 30 days are expired. The system re-learns naturally as the histogram shifts toward the new pattern.

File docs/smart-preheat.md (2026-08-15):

# Smart Preheat — Self-Learning Decision Tree (V1)

**Status:** implemented on branch `feature/smart-learning` (off `v8`).
**Where:** master firmware only (`master/src/smart_preheat.{h,cpp}`).

This is the "learning brain" the project book describes (§ decision-tree / habit
learning): a **transparent, deterministic If/Else decision tree** — *not* AI —
that learns when the household showers and pre-heats the tank so hot water is
ready on time, saving energy the rest of the day.

---

## 1. Three operation modes

Chosen on the Schedule page (v8 UI). Read by the brain via `ui_manager` accessors
(`UI_GetOpMode`, `UI_GetReadyByMinute`, `UI_GetHouseholdSize`). **All three modes
read the real sensors + weather** — the mode only changes *when the boiler decides
to run*.

| Mode | UI state | Behaviour |
|---|---|---|
| **Dumb** | `g_auto_enabled = false` | Plain reactive — user presses ON/OFF. Brain idle. |
| **Ready-by** | auto on, `g_smart_learn = false` | User sets a shower time; system pre-heats so the tank is warm by then. Works immediately (no learning wait). |
| **Smart** | auto on, `g_smart_learn = true` | System learns shower times and pre-heats automatically. User doesn't touch it. |

## 2. What "pre-heat" means

The tank's energy-saving base target is **40 °C** (SystemManager). Pre-heat simply
raises the "boiler ON" request during a window around the expected shower, so
SystemManager warms the tank to 40 °C and the inline boost is ready. The brain:
- **never** overrides a manual ON/OFF,
- **never** touches the safety interlocks,
- cannot overheat — SystemManager still regulates to 40 °C and drops to STANDBY.

## 3. Learning model

A **96-slot histogram** (24 h × 15 min). Every real shower (flow crossing 0 → >1 L/min)
increments its slot. Persisted to SPIFFS flash (`/preheat.json` via `DataManager`)
so it survives reboots and accumulates over 1–2 weeks.

- **Reliable** when the busiest slot has been seen **≥ 3 times** AND **≥ 7 days**
  of data exist. Until then, Smart mode keeps learning and does nothing.
- **Predicted time** = centre of the busiest slot.

## 4. The decision tree (runs every 60 s)

```
s_wantsHeat = false
if mode == DUMB              → return   # brain idle
if PLC link lost (>5 s)      → return   # safety: stand down (watchdog)
if clock not synced          → return   # need real time
if tank temp >= 80 C         → return   # safety: hand off to hard protections
if user pressed ON           → return   # respect manual control
target = (mode==READY_BY) ? user_time : learned_peak
if SMART and not reliable    → return   # still learning
if now within [target − lead, target + grace] → s_wantsHeat = true
```

Safety & user priority always win: a manual action, a **PLC timeout > 5 s**
(watchdog in `comms_master`, feeds `plcConnected`), or an **over-temp (≥ 80 °C
at the brain; SystemManager hard-cuts at 85 °C)** bypass the engine and return
control to the controller's hard protections.

`comms_master` then sets `uiStateOn = manual_on || wantsHeat()`.

**Lead time (V1):** fixed `BASE_LEAD_MIN = 45 min` (+5 min/person above 2, capped 90).
`SHOWER_GRACE_MIN = 45 min` keeps the boiler ready through the shower.

## 5. Persistence (SPIFFS)

`DataManager::savePreheat/loadPreheat` store the histogram + `total`, `days`,
`lastYday` as `/preheat.json` (~200 bytes). Loaded once at boot in `setup()`.

## 6. Integration points

| File | Change |
|---|---|
| `smart_preheat.{h,cpp}` | the brain (new) |
| `DataManager.{h,cpp}` | `savePreheat` / `loadPreheat` (SPIFFS) |
| `ui_manager.{h,cpp}` | `UI_GetOpMode` / `UI_GetReadyByMinute` / `UI_GetHouseholdSize` |
| `comms_master.cpp` | shower detection (flow rising edge) + 60 s brain tick + `uiStateOn` OR |
| `main.cpp` | `SmartPreheat::init()` after `DataManager::init()` |

## 7. V1 limitations / V2 roadmap

- **Fixed lead time** — a real cold tank can take ~1.4 h to reach 40 °C. V2: adaptive
  lead measured from real heat-up sessions (a `HeatupTracker`).
- **Weather** is read by the system but not yet used to adjust the lead. V2: colder
  inlet → start earlier.
- **Learning runs in REALTIME only** (real showers). Demonstrating it needs real time
  passing or an event-injection test hook.
- **UI feedback** (showing predicted time / "learning… N/7 days" on the Smart panel)
  is a small follow-up; the control path (modes → real behaviour) is wired.
- **Time-of-day only** — the learning histogram aggregates all days into one
  96-slot model (it does not separate weekday vs weekend showers). Ready-by mode
  *does* distinguish weekday/weekend. Per-day-of-week learning is a clean V2.
- The decision engine is a **periodic 60 s routine inside `TaskMasterComms`**, not
  a standalone FreeRTOS task (functionally equivalent; could be split out later).
- **Skip-today** button is not yet gated into the brain.

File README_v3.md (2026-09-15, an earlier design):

# Smart Boiler — Project README (Branch: v9_merge)

Last updated: August 2026  
Git branch: `v9_merge` (integrated: scenario-alignment + smart-learning + UI)  

> Sections 1–11 below describe the stable v7 baseline. The **v9 changes** and the
> **TODO** are summarised immediately below.

---

## Repository Layout — start here

Both firmwares use the same folder scheme, so once you understand one you can
read the other. Files are grouped by responsibility, and the folders are listed
in the order they make sense to read.

```
master/src/                              slave/src/
├── main.cpp      boot, WiFi/NTP,        ├── main.cpp      boot, mutexes,
│                 LVGL render loop       │                 FreeRTOS task creation
├── config/       pin map, wire          ├── config/       pin map, wire
│                 protocol, LVGL and     │                 protocol, transport
│                 display config         │                 ports, WiFi secrets
├── comms/        transport backends     ├── comms/        transport backends
│                 + master comms task    │                 + protocol + task
├── control/      SystemManager state    ├── core/         shared state, mutexes,
│                 machine, smart          │                 DEMO/REALTIME mode
│                 preheat, app mode      ├── tasks/        the six FreeRTOS tasks:
├── data/         statistics,            │                 temp, flow, current,
│                 WiFi/NTP/weather       │                 safety, 2x SSR PWM
├── ui/           LVGL screens,          └── diagnostics/  standalone test
│                 display port layer                       sketches (not built)
├── demo/         8-scenario test bench
└── diagnostics/  standalone sketches
```

### Where do I look for…?

| Question | File |
|---|---|
| What decides when the heater turns on? | `master/src/control/SystemManager.cpp` |
| What do master and slave actually send each other? | `*/src/config/boiler_protocol.h` |
| How do the bytes travel? | `*/src/comms/link.h` + `link_plc.cpp` / `link_wifi.cpp` |
| How is an SSR actually switched? | `slave/src/tasks/pwm_task_internal.cpp` |
| What protects against overheating / a stuck SSR? | `slave/src/tasks/safety_task.cpp` |
| Where are the 8 demo scenarios scripted? | `master/src/demo/demo_scenarios.cpp` |
| Which GPIO is what? | `*/src/config/config.h` |

### Transport — PLC, with a WiFi option

The master↔slave link runs over the **KQ-330 power-line modem** by default, with
**WiFi/UDP** available as an option, carrying byte-identical packets. Everything
above `comms/` — the state machine, the demo scenarios, the UI, every slave
task — is transport-agnostic.

Select it with one build flag, **the same on both sides**:

```ini
build_flags =
    ; -DLINK_WIFI    ; flag absent (default) -> KQ-330 power-line modem
                     ; uncomment             -> WiFi (UDP)
```

> **Note on `#include`:** every include stays short (`#include "config.h"`)
> because each `platformio.ini` adds the `src/` subfolders to the include path.
> No source file needed editing when the folders were introduced.

---

## 0. v9_merge — What changed (latest)

**Firmware alignment (from `feature/scenario-alignment`)**
- FreeRTOS mutexes renamed `mutex_* → guard_*` (project book Table 15 / §9.1.9).
- 8 demo scenarios aligned to the MATLAB `Models/` values & timings (book §9.1.8/10).
- SystemManager: `BOOST_CUTOFF_C 45→42 °C`, `FLOW_THRESHOLD_LPM 0.5→1.0`.
- Slave HW-interlock sim `86→85 °C`; PLC watchdog (BUG-2/SW-1) — `plcConnected`
  now a real 5 s STATUS-timeout, not hardcoded.
- Added the authoritative `Matlab/` simulation suite (8 scenarios + `boiler_params.m`).

**Self-learning "brain" (from `feature/smart-learning`, master only)**
- `smart_preheat.{h,cpp}` — deterministic decision-tree: a 96-slot (15-min) shower
  histogram (persisted to SPIFFS `/preheat.json`), reliable after ≥7 days & a slot
  seen ≥3×, then auto pre-heats before the predicted time. **Adaptive lead**: the
  start time is computed from how far the tank is below 40 °C at the modelled
  heat-up rate (~0.24 °C/min) — colder now ⇒ start earlier — clamped 10–120 min,
  + a per-person margin. Safety: stands down on manual ON, PLC loss (>5 s), or tank ≥80 °C.

**UI (master)**
- **3-way operation mode** on Schedule: **Manual / Ready-by / Smart** (replaces the
  old Auto-toggle + 2-way selector). Manual hides the pre-heat/skip column.
- **Ready-by supports two daily slots** — **Morning + Evening** per day-type, each
  with an On/Off toggle. Brain pre-heats before any enabled slot.
- **Demo/Real-time** toggle moved **Settings → Diagnostics**, renamed **"Data source"**,
  colour-coded (orange = Demo, green = Real-time).
- Pre-heat lead time display aligned to the brain (**45 min**).
- Wizard default ready-by time now seeds the Schedule + brain.
- Day-type labels: **Sun–Thu** (week) / **Fri–Sat** (weekend) — Israeli work week.

## 0.1 TODO — next steps

- [ ] **Compile-verify `v9_merge`** in PlatformIO (master + slave) — the v9 UI/brain
      changes have not yet been built on a real toolchain.
- [ ] **Week / weekend definition:** week = **Sunday–Thursday**, weekend =
      **Friday–Saturday** (Israeli). Logic already uses this; UI labels now match —
      keep this convention anywhere day-of-week is added.
- [ ] **Setup wizard:** add a **second (Evening) time** picker so onboarding can set
      both slots (currently the wizard sets the Morning default only; the Evening
      slot is set on the Schedule screen).
- [ ] **Smart panel:** show live learning progress ("N / 7 days") on the UI.
- [x] **Adaptive lead time (V2):** DONE — lead is computed from the current tank
      temperature at a modelled heat-up rate (not a fixed 45 min).
- [ ] **Learn the heat-up rate (V3):** replace the fixed ~0.24 °C/min model with a
      value measured from real heat-up sessions; optionally fold in weather/inlet
      temperature (colder inlet → start earlier).
- [ ] Update UI chapter figures/text in the project book to match the v9 screens.

---

## 1. System Overview

Two-device IoT boiler controller communicating over the 220V power line (PLC modem).

| Role | MCU | Board | IDE |
|---|---|---|---|
| Master | ESP32-S3 | Viewe UEDX80480050E-WB-A | This PC |
| Slave  | ESP32-C6 | Generic ESP32-C6-DevKitC-1 | Personal PC|

The master runs a touchscreen dashboard (LVGL v8, 800×480) and sends heater commands over the power line every second. The slave reads sensors, controls two SSRs, and sends status back.

---

## 2. Hardware Wiring

### 2.1 Master (ESP32-S3) — Comms Pins
| Signal | GPIO | Notes |
|---|---|---|
| TX → KQ-330  | 17 | MASTER_TX_PIN in config.h |
| RX ← KQ-330  | 13 | MASTER_RX_PIN — SD-MISO pin, SD not used |
| Serial debug | 43/44| UART0 (USB CDC off: ARDUINO_USB_CDC_ON_BOOT=0) |

> ⚠️ KQ-330 DOUT is **5V TTL**. GPIO13 has no pull-up so it works without a level shifter, but a proper 5V→3.3V level shifter should be added before production.

### 2.2 Slave (ESP32-C6) — All Pins
| Signal | GPIO | Component |
|---|---|---|
| DS18B20 1-Wire bus  | 7 | Three temp sensors on one wire |
| Flow sensor | 6 | YF-B6 via MOSFET Q2 + level shifter U1 |
| SSR Internal | 4 | Tank heater SSR |
| SSR Boost | 5 | Inline boost heater SSR |
| Current sensor | 3 | ACS758LCB-050B via 1.8kΩ/3.3kΩ divider |
| PLC RX | 10 | KQ-330 via level shifter U3 |
| PLC TX | 11 | KQ-330 |
| Serial debug | USB  | Serial at 115200 |

### 2.3 KQ-330 PLC Modem
- Half-duplex UART 9600 baud over 220V power line
- Master TX → KQ-330 DIN, KQ-330 DOUT → Master RX
- Slave TX → KQ-330 DIN, KQ-330 DOUT → Slave RX
- Both modems must be on the **same electrical phase** of the mains

### 2.4 Current Sensor (ACS758LCB-050B)
- Powered at 5V, sensitivity 40 mV/A, quiescent output 2.5V (VCC/2)
- Output divided by 1.8kΩ / 3.3kΩ voltage divider before ESP32 ADC
- Divider ratio: 3.3 / 5.1 = 0.647
- Calibrates zero reference at boot (200 samples × 5ms = 1 second)
- **Known issue:** if current is flowing at boot, calibration offset is wrong → safety fault fires immediately. See Section 7.

### 2.5 SSRs
- Both SSRs are **zero-crossing AC solid-state relays**
- Controlled by LEDC PWM: `ledcAttach(pin, 1000Hz, 8-bit)`, duty = 127 when ON
- **Known limitation:** 1kHz 50% duty (127/255) causes the SSR to fire on only ~50% of AC half-cycles → load gets ~50% power. Works for a resistive boiler element but may not illuminate small LED loads
- **Minimum holding current:** Zero-crossing SSRs require a minimum load current (~50–200mA depending on model) to keep the triac latched. A 9W LED (40mA) may be below this threshold and will NOT light up. The real boiler element (~13A) will work correctly.

---

## 3. Software Architecture

### 3.1 Master Tasks (ESP32-S3)

```
main.cpp
  ├── LVGL render loop (loop())
  ├── TaskMasterComms (comms_master.cpp)
  │     ├── Serial1 RX → receive STATUS packets
  │     ├── SystemManager::process() → decide PWM/flags
  │     ├── Serial1 TX → send CMD packets (every 1 second)
  │     └── handleTestMenu() — Serial console: '1'=ON '0'=OFF 'r'=auto '?'=help
  └── UI (ui_manager.cpp) — LVGL dashboard, boiler_state, target_temperature
```

**SystemManager state machine** (`SystemManager.cpp`):
| Priority | State | Condition | Output |
|---|---|---|---|
| 1 (high) | SAFETY_OVERRIDE | plcConnected = false OR temp ≥ 85°C | pwmInt=0, boost=0 |
| 2 | STATE_OFF | uiStateOn = false | pwmInt=0, boost=0 |
| 3 | STATE_SHOWER_BOOST  | flow > 1.0 L/min AND currentTemp < 42°C | pwmInt=0, boost=100 |
| 3 | STATE_SHOWER_BOOST  | flow > 1.0 L/min AND currentTemp ≥ 42°C | pwmInt=0, boost=0 (warm enough) |
| 4 | STATE_HEATING_TANK  | no flow AND currentTemp < 40°C | pwmInt=100, boost=0 |
| 5 (low)  | STATE_STANDBY | no flow AND currentTemp ≥ 40°C | pwmInt=0, boost=0 |

**Key constants** (`SystemManager.h`):
- `TARGET_TANK_TEMP = 40°C` — internal heater target
- `BOOST_CUTOFF_C = 42°C` — boost heater disables above this tank temp (Models S3 dynamic target)
- `TEMP_CUTOFF_C = 85°C` — hard safety cutoff
- `FLOW_THRESHOLD_LPM = 1.0 L/min` — minimum flow to trigger boost (matches slave boost interlock)

> Note: `plcConnected` is derived from a real STATUS-timeout watchdog in `comms_master.cpp` (5s). SAFETY_OVERRIDE fires on true PLC loss in REALTIME (BUG-2 fixed).

### 3.2 Slave Tasks (ESP32-C6, FreeRTOS, all pinned to Core 0)

```
main.cpp
  ├── TaskSafety       — priority 4 — runs every 50ms, mutex snapshot, hard-cuts SSRs on fault
  ├── TaskPWM_Internal — priority 3 — mutex snapshot of cmd at burst cycle start
  ├── TaskPWM_Boost    — priority 3 — mutex snapshot of cmd+flow, runtime mode check
  ├── TaskFlow         — priority 2 — pulse counter ISR, guard_flow protects write
  ├── TaskTemp         — priority 2 — DS18B20 readings, guard_temps protects write
  ├── TaskCurrent      — priority 2 — ACS758 RMS sampling, guard_current protects write
  ├── TaskPLC          — priority 2 — triggered: send STATUS after CMD received (200ms guard)
  └── TaskSerial       — priority 1 — serial console: 'b'=BENCH_TEST 'p'=PRODUCTION '?'=status
```

**FreeRTOS mutex layout** (created in `setup()` before any task starts):
| Mutex | Guards |
|---|---|
| `guard_temps` | `temps[3]` — written by TaskTemp, read by TaskPLC + TaskSafety |
| `guard_flow` | `current_flow` — written by TaskFlow, read by TaskPLC + TaskSafety + TaskPWM_Boost |
| `guard_current` | `current_rms`, `power_watts` — written by TaskCurrent, read by TaskPLC + TaskSafety |
| `guard_cmd` | `cmd_pwm_internal/boost/flags` — written by TaskPLC, read by TaskPWM + TaskSafety |

**TaskPLC communication pattern** (half-duplex KQ-330):
```
Master sends CMD every 1s
  └─ Slave receives CMD
       └─ 200ms guard (KQ-330 echo clears)
            └─ Slave sends STATUS
                 └─ Master receives STATUS within 3s window

Heartbeat: if no CMD received for 5s, slave pushes STATUS anyway
```
> Key: slave must NOT transmit independently at 1s intervals — that causes
> half-duplex collision with the master’s CMD and both packets are lost.

**PWM (time-proportional burst) logic** (both SSR tasks):
```
window = 2000ms
on_ms  = (2000 × pwm_val%) / 100
off_ms = 2000 - on_ms

→ ledcWrite(pin, 127)   ← SSR ON for on_ms
→ ledcWrite(pin, 0)     ← SSR OFF for off_ms
```

**Safety checks** (every 50ms):
1. Any sensor > 80°C → fault
2. Boost commanded with flow < 1.0 L/min → fault
3. `current_rms > 0.5A` with no command → fault (SSR short detection)

On fault: `ledcWrite(both SSRs, 0)` + `system_fault = true` (latches until reboot).

---

## 4. Communication Protocol

Binary packet over KQ-330 PLC modem, max 1 packet/second.

**Frame:** `[0xAA | LEN | TYPE | SEQ | ...payload... | CRC8 | 0x55]`  
CRC-8/SMBUS (poly 0x07) covers TYPE through last payload byte.

### CMD packet (Master → Slave, 9 bytes total)
| Field | Size | Description |
|---|---|---|
| startByte | 1 | 0xAA |
| length | 1 | 5 (payload length) |
| packetType  | 1 | 0x02 |
| sequence | 1 | wrapping counter |
| pwmInternal | 1 | 0–100% |
| pwmBoost | 1 | 0–100% |
| cmdFlags | 1 | bit0=HEATER_ENABLE, bit1=BOOST_ENABLE, bit7=EMERGENCY_STOP |
| crc8 | 1 | CRC |
| endByte | 1 | 0x55 |

### STATUS packet (Slave → Master, 17 bytes total)
| Field | Size | Description |
|---|---|---|
| startByte | 1 | 0xAA |
| length | 1 | 13 (payload length) |
| packetType | 1 | 0x01 |
| sequence | 1 | wrapping counter |
| tempInternal  | 2 | tank temp × 10 (fixed-point) |
| tempBoilerOut | 2 | boiler outlet temp × 10 |
| tempBoostOut  | 2 | boost outlet temp × 10 |
| flowRate | 2 | L/min × 10 |
| powerWatts | 2 | watts (uint16) |
| statusByte | 1 | bit0=FLOW_ACTIVE, bit1=INTERNAL_ON, bit2=BOOST_ON, bit3=FAULT |
| crc8 | 1 | CRC |
| endByte | 1 | 0x55 |

### Log format (both sides)
```
[M->S] seq= 42 | pwmInt=100%  pwmBst=  0% | flags=0x01 | [STATE_HEATING_TANK]
[M<-S] seq= 42 | t1= 25.2  t2= 25.5  t3= 26.0 | flow= 0.0  pwr=   0W | sts=0x02
[S<-M] seq= 42 | pwmInt=100%  pwmBst=  0% | flags=0x01
[S->M] seq= 15 | t1= 25.2  t2= 25.5  t3= 26.0 | flow= 0.0  pwr=   0W | sts=0x02
```
- `sts=0x02` → SSR Internal ON (normal heating)
- `sts=0x08` → FAULT latched
- `pwr=0W` with 9W LED test load is expected (40mA < 0.2A noise filter threshold)

---

## 5. PlatformIO Configuration

### Master (`master/platformio.ini`)
```ini
platform = https://github.com/pioarduino/platform-espressif32/releases/download/53.03.11/platform-espressif32.zip
board = BOARD_VIEWE_UEDX80480050E_WB_A
framework = arduino
upload_port = COM7       ← change to your port
monitor_port = COM7      ← change to your port
monitor_speed = 115200
build_flags =
    -DARDUINO_USB_CDC_ON_BOOT=0
    -DBOARD_HAS_PSRAM
    ...
```

### Slave (`slave/platformio.ini`)
```ini
platform = espressif32
board = esp32-c6-devkitc-1
framework = arduino
monitor_speed = 115200
```

---

## 6. Demo / Realtime Mode Framework

### 6.1 Master — Operation Mode

Toggled at runtime from the **Settings** screen ("Switch" button).

| Mode | Default | Behaviour |
|---|---|---|
| `MODE_DEMO` | ✅ boot default | Slave uses mock sensor data driven by master CMD flags. All interlocks active. Faults auto-clear (2s). |
| `MODE_REALTIME` | — | Slave reads real DS18B20 / YF-B6 / ACS758 sensors. All safety interlocks permanently active. |

Auto-switch: `CMD_DEMO_ACTIVE` flag in every CMD propagates the master mode to the slave automatically.  
Serial override: `d` = DEMO, `r` = REALTIME, `?` = status

### 6.2 Slave — SystemMode

Slave switches automatically when CMD contains `CMD_DEMO_ACTIVE` flag.

| Mode | Serial command | Behaviour |
|---|---|---|
| `MODE_DEMO` | `d` (or auto via CMD) — boot default | Mock sensors from master flags; real DS18B20/YF-B6/ACS758 ignored. All interlocks active. Faults auto-clear after 2s. |
| `MODE_REALTIME` | `r` (or auto via CMD) | Real DS18B20 / YF-B6 / ACS758 sensors. All interlocks permanent. |

### 6.3 Demo Scenario Flags in cmdFlags

| Bit | Constant | Effect on slave |
|---|---|---|
| 3 | `CMD_DEMO_ACTIVE` | Slave enters MODE_DEMO, uses mock sensor logic |
| 4 | `CMD_DEMO_FAULT_SIM` | Slave reports 13.6A even when SSRs off (S8) |
| 2 | `CMD_DEMO_FLOW` | Slave injects flow = 6.5 L/min |
| 5 | `CMD_DEMO_OVERTEMP` | Slave injects temp = 87°C (triggers safety in S7) |

Slave infers mock temp from SSR command: HEATER→ON = 25°C, BOOST→ON = 35°C, idle = 42°C.

### 6.4 Automated 8-Scenario Test Bench

`TaskAutomatedTestBench` runs on Core 1 and cycles through 8 scenarios automatically (~60s each). Starts 6s after boot, only executes when `APP_MODE_DEMO`. Values and intra-scenario timings are aligned to the authoritative MATLAB models in `Models/Models/` (`Scenario_1..8`, `boiler_params.m`).

| # | Category | Scenario | Temp | Flow | Expected State | SSR Int | SSR Boost |
|---|---|---|---|---|---|:---:|:---:|
| S1 | A | Pre-Heating | 20°C | 0 | STATE_HEATING_TANK | **ON** | OFF |
| S2 | A | Preheated Shower | 40°C | 8 @ t=30s | STATE_SHOWER_BOOST | OFF | **ON** |
| S3 | A | Warm Shower Cutoff | 45°C | 8 @ t=30s | STATE_SHOWER_BOOST | OFF | OFF |
| S4 | A | Standby | 42°C | 0 | STATE_STANDBY | OFF | OFF |
| S5 | B | Solar Bypass | 28→42°C | 0 | STANDBY (forced) | OFF | OFF |
| S6 | C | PLC Loss | 20°C | 0 | SAFETY_OVERRIDE | OFF | OFF |
| S7 | C | Overtemp | 70→86°C | 0 | SAFETY_OVERRIDE | OFF | OFF |
| S8 | C | Stuck SSR | 70°C | 0 | FAULT (0x08) | OFF | OFF |

> S6 timeline: idle 0–15s → heating 15–30s → PLC link cut at t=30s. S7 ramps from 70°C at 0.4°C/s (software cutoff 80°C ≈ t+25s, HW interlock 85°C ≈ t+37.5s).

### 6.5 Demo Serial Log Format

**Master (every ~2s):**
```
[MASTER] [seq=003] STATE: HEATING_TANK   | TEMP: 25.0°C | FLOW:  0.0LPM | PWR: 2499W | SEND -> INT: 100% | BST:   0%
[MASTER] ⚠️ PLC TIMEOUT > 5s! ENTERING SAFETY_OVERRIDE         ← event, once
[MASTER] ❌ RECEIVED STATUS_FAULT (0x08) FROM SLAVE! SYSTEM LOCKED.  ← event, once
```

**Slave (every ~2s):**
```
[SLAVE]  [seq=003] SSR_INT: ON  | SSR_BST: OFF | TEMP: 25.0°C | FLOW:  0.0LPM | PWR: 2499W | CURR: 11.4A
[SLAVE] ⚠️ SOFTWARE CUTOFF: Temp >= 80°C. Dropping PWM to 0%.     ← event, once
[SLAVE] ❌ HARDWARE INTERLOCK TRIP! (LM393N Simulation) -> CURRENT FORCED TO 0.0A!  ← event, once
[SLAVE] !!! CRITICAL FAULT: UNCOMMANDED CURRENT DETECTED IN 50ms LOOP!  ← event, once
```

---

## 7. Current Verified Status (as of branch v7, July 2026)

| Item | Status | Notes |
|---|---|---|
| Master ↔ Slave PLC comms | ✅ WORKS | Stable with KQ-330 timing constants locked |
| Master LVGL UI (v6 multi-screen) | ✅ WORKS | Home, Settings, Stats, Schedule, Diagnostics, Solar screens |
| Demo / Realtime mode toggle | ✅ WORKS | Settings page "Switch" button |
| 8-scenario automated test bench | ✅ WORKS | Runs on Core 1, 60s per scenario |
| S1 Pre-Heating (SSR INT ON) | ✅ WORKS | 2500W confirmed |
| S2 Preheated Shower (SSR EXT ON) | ✅ WORKS | 3000W confirmed |
| S3 Warm Shower Boost Cutoff | ✅ WORKS | Both SSRs off at 45°C |
| S4 Standby | ✅ WORKS | 0W confirmed |
| S5 Solar Bypass (forced 0W) | ✅ WORKS | 28→42°C sweep, SSRs stay off via override |
| S6 PLC Loss watchdog | ✅ WORKS | Slave safety trips after 5s, auto-clears in demo |
| S7 Overtemp cutoff | ✅ WORKS | Software @80°C, HW interlock sim @85°C |
| S8 Stuck SSR detection | ✅ WORKS | Uncommanded current fault within 50ms |
| UI power button locked in demo | ✅ WORKS | Cannot toggle boiler during demo |
| Mock power values | ✅ WORKS | SSR_INT=2500W (11.36A), SSR_BOOST=3000W (13.64A) |
| SystemMode runtime (slave) | ✅ WORKS | d=DEMO, r=REALTIME serial commands + auto via CMD_DEMO_ACTIVE |
| FreeRTOS mutexes (4 guards) | ✅ WORKS | guard_temps/flow/current/cmd |
| TaskMasterComms on Core 0 | ✅ WORKS | Isolated from LVGL (Core 1), no preemption |
| KQ-330 timing locked | ✅ WORKS | 2ms/byte TX + 200ms guard — DO NOT CHANGE |
| WiFi + NTP sync | ✅ WORKS | Auto-reconnect, time shown on dashboard |
| Weather + Solar Forecast | ✅ WORKS | Fetched on WiFi connect, updated hourly/daily |
| Temp display (REALTIME, no sensor) | ✅ FIXED | Shows `---` instead of stale value when DS18B20 disconnected |
| Uncommanded-current check | ✅ WORKS | Auto-disabled when VREF out of spec (ADC calibration issue); S8 always active in DEMO |
| 220V actual load test | ❌ UNTESTED | Needs resistive load (≥40W), not 9W LED |

---

## 8. Known Bugs and Limitations

### BUG-1: Current sensor false fault on boot (safety_task.cpp)
**Symptom:** `[SAFETY] FAULT: Current detected without command` fires continuously, `sts=0x08`, SSR never turns on.  
**Root cause:** If the SSR is conducting when the slave boots (stuck triac from previous session, or any other reason), the 1-second zero-current calibration in `TaskCurrent` captures the wrong VREF. The offset bakes in ~4A phantom current that persists even after the SSR is commanded OFF.  
**Workaround:** Disconnect 220V from the SSR output, then reboot the slave.  
**Proper fix needed:** Add VREF sanity clamp in `current_task.cpp` (reject calibration if VREF deviates >10% from 2.5V nominal) AND ensure SSR pins are explicitly LOW before calibration runs.

### BUG-2 (FIXED): `plcConnected` hardcoded to `true` (comms_master.cpp)
**Was:** `inputs.plcConnected = true` hardcoded in `sendCommand()` → SAFETY_OVERRIDE never fired on real PLC loss.  
**Fix:** `sendCommand()` (REALTIME) now sets `plcConnected = status_ever && (millis() - last_status_ms < 5000)`. A valid STATUS refreshes `last_status_ms`; before the first STATUS the link is treated as disconnected (fail-safe). SAFETY_OVERRIDE now fires after 5 s of silence.

### NOTE (was BUG-3): SSR LEDC 1 kHz carrier is REQUIRED by the hardware watchdog (pwm_task_internal.cpp, pwm_task_boost.cpp)
The internal/boost SSR gate is a **DC-blocking capacitive watchdog** (project book §9.1.9, "Internal/External Watchdog Gate"): it latches only while it receives a continuous high-frequency pulse train, and treats a constant DC level as a controller-freeze fault, cutting the heater within ~1s (RC τ≈1s).  
**Therefore `ledcWrite(pin, 127)` @ 1 kHz is mandatory, not a defect** — it supplies that carrier.  
**⚠️ DO NOT** replace it with `digitalWrite(HIGH)`: constant DC would trip the hardware watchdog and the heater could never sustain ON. The earlier "replace LEDC with digitalWrite" (SW-3) suggestion is **retracted**.  
**Side effect (accepted):** a zero-crossing SSR driven at 1 kHz fires on ~50% of AC half-cycles, so tiny LED test loads (below triac holding current) may not light. The real resistive boiler element works correctly. For bench LED tests use a 40W+ incandescent/resistive load.

### LIMITATION: 9W LED is not a valid SSR test load
Zero-crossing SSRs require a minimum holding current (typically 50–200mA). A 9W 220V LED draws only ~40mA. The triac drops out every zero crossing. Use a 40W+ incandescent bulb or the real boiler element for testing.

---

## 9. TODO — Next Development Steps (Priority Order)

### Phase 1: Hardware Validation Checklist
Before writing more code, confirm these hardware items work:

- [ ] **HW-1** Flash both devices on v3, confirm `[S<-M]` and `[S->M]` appear in both monitors with no `DROP` lines
- [ ] **HW-2** Connect a resistive test load (≥40W incandescent bulb) to SSR_INT output. Command boiler ON. Confirm load powers on.
- [ ] **HW-3** Measure current with a clamp meter when load is ON. Confirm `pwr` reading in slave monitor is reasonable (use ≥40W resistive load; 9W LED is too low for SSR triac holding current)
- [ ] **HW-4** Test temperature reading by warming a sensor. Confirm `t1` rises in monitor.
- [ ] **HW-5** Test flow sensor by running water. Confirm `flow > 0` appears.
- [ ] **HW-6** Test overtemp safety: heat a sensor to >80°C. Confirm `[SAFETY] FAULT: Overheat` fires and SSR turns off.
- [ ] **HW-7** Test uncommanded current detection: command OFF, then manually force SSR ON with a wire. Confirm fault fires within 50ms.
- [ ] **HW-8** Add 5V→3.3V level shifter on master RX (GPIO13) from KQ-330 DOUT before final install.

### Phase 2: Software Bug Fixes
- [x] **SW-1** ✅ DONE — PLC watchdog implemented in comms_master.cpp (`plcConnected` from 5 s STATUS-timeout; fail-safe before first STATUS).
- [ ] **SW-2** Fix BUG-1: add VREF sanity clamp in `current_task.cpp` AND drive SSR pins LOW explicitly before calibration starts
- [x] **SW-3** ❌ REJECTED — do NOT replace `ledcWrite(pin, 127)` with `digitalWrite(HIGH)`. The 1 kHz carrier is required by the DC-blocking hardware watchdog gate (see NOTE "was BUG-3"). Constant DC would trip the interlock and cut the heater. Closed, no action.
- [ ] **SW-4** Add `system_fault` reset mechanism (e.g. CMD_EMERGENCY_STOP cleared = reset fault) so recovery doesn't require hardware reboot
- [ ] **SW-5** Increase current noise floor for real boiler: change `0.2f` threshold to match actual noise profile after real load testing
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

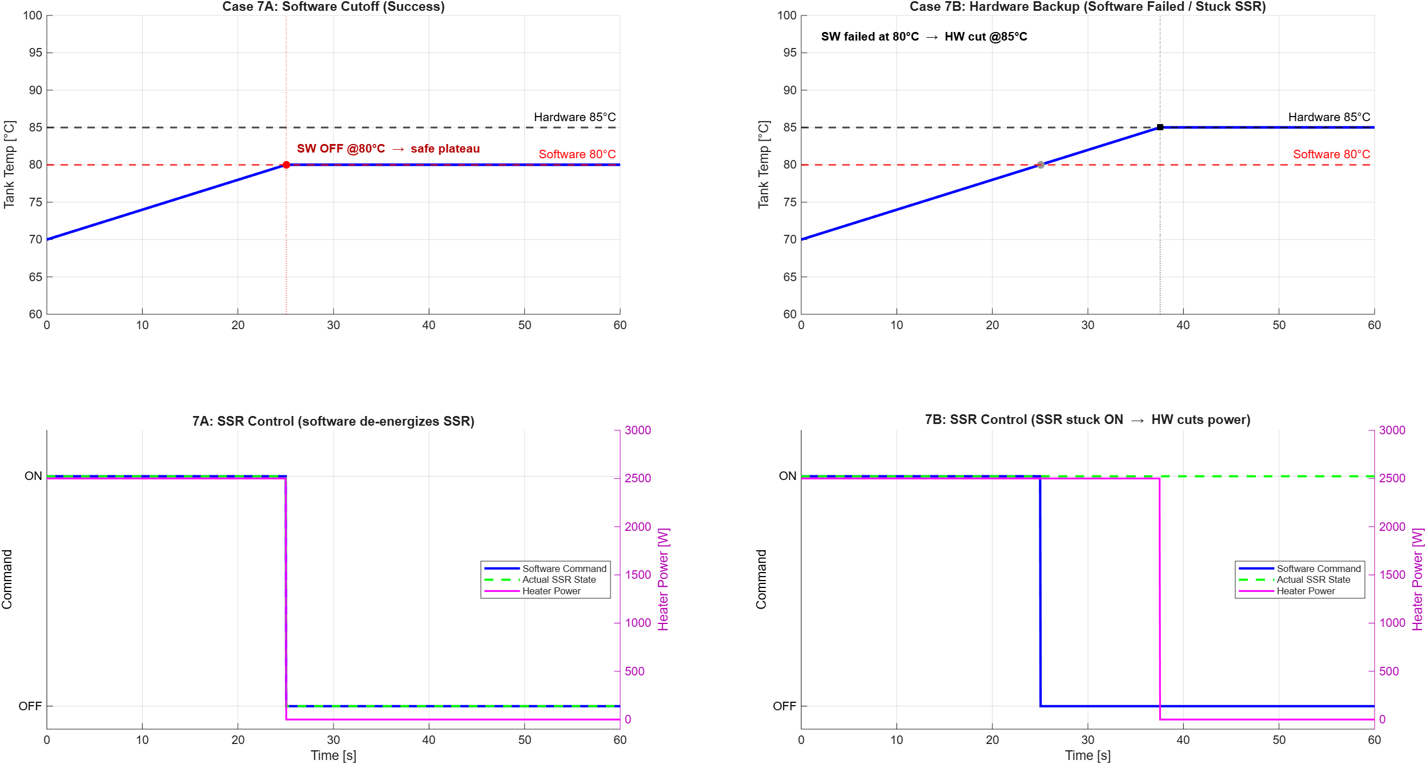
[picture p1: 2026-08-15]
Matlab/figures/Scenario_7_Overtemp.png

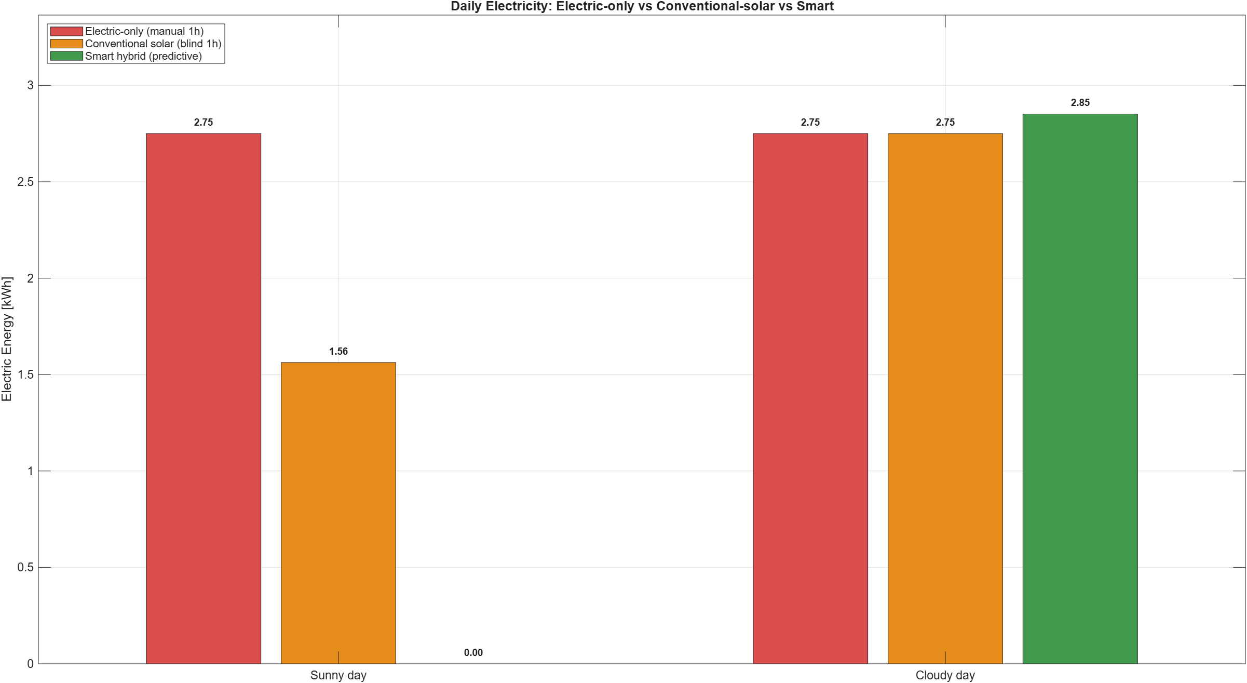
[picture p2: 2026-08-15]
Matlab/figures/Scenario_5_energy_bar.png

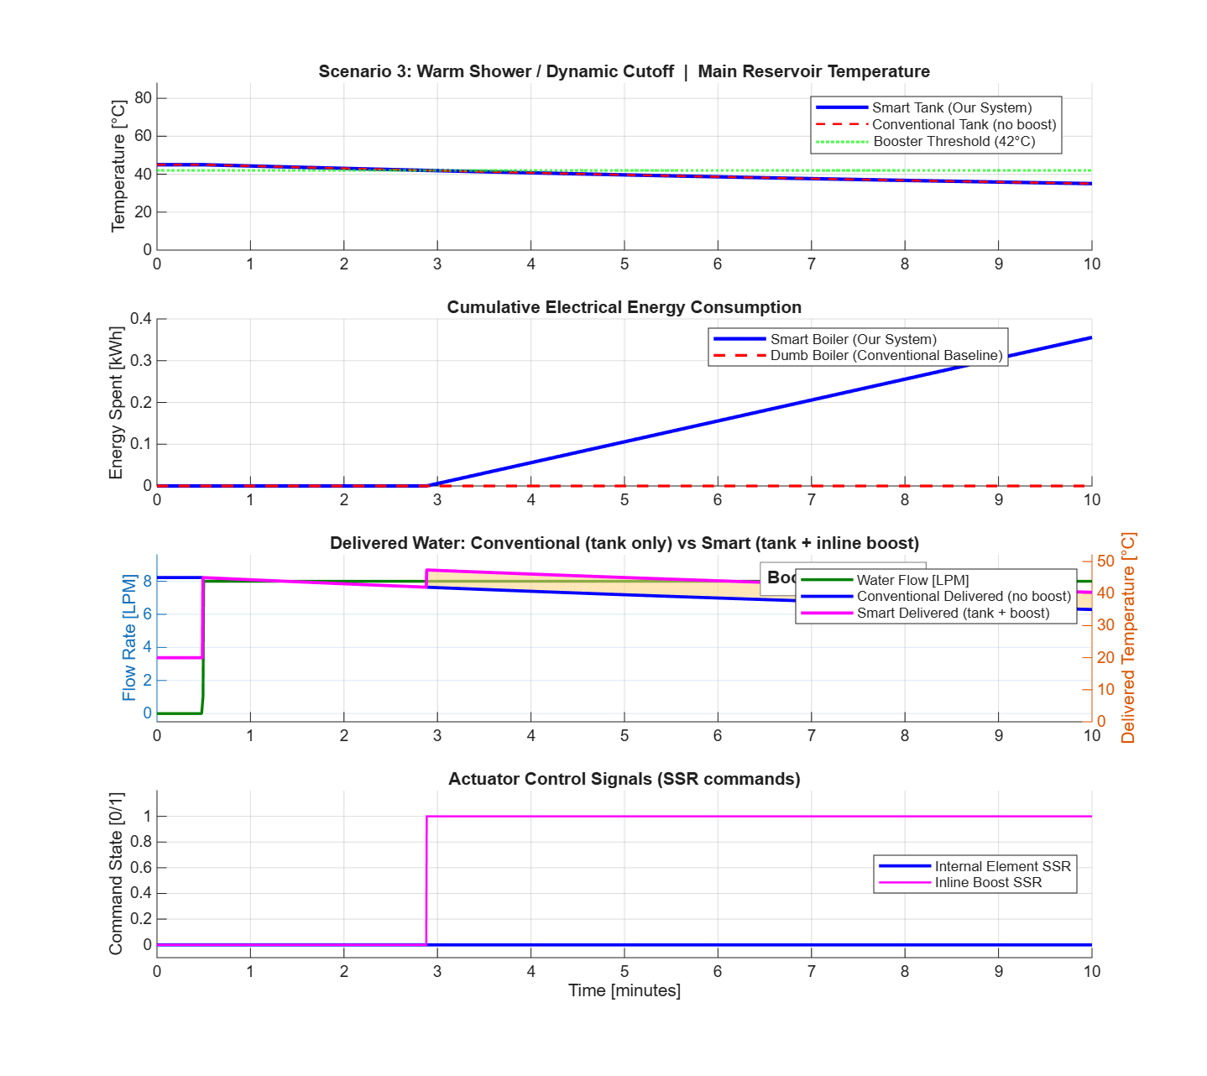
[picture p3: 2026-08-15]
Matlab/figures/Scenario_3_WarmShowerCutoff.png

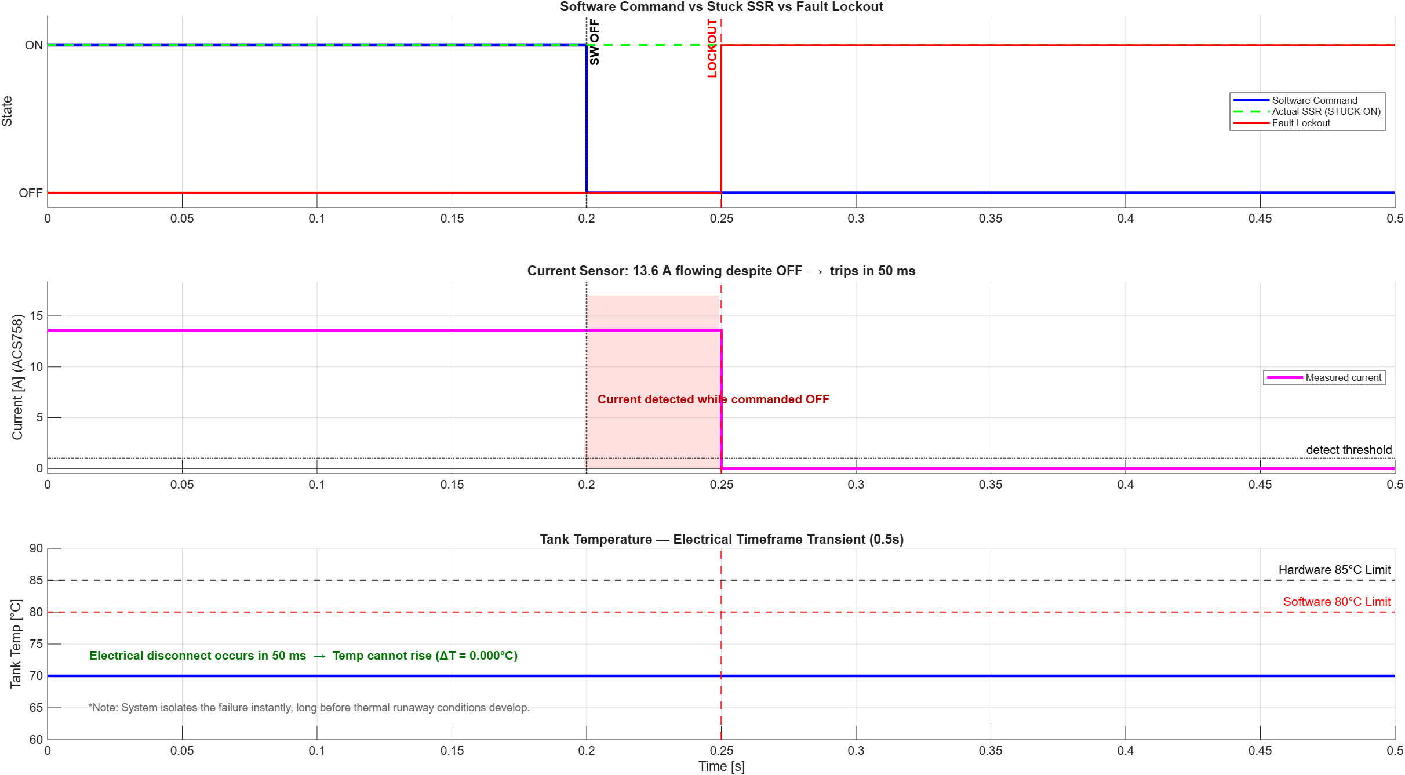
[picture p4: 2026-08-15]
Matlab/figures/Scenario_8_StuckSSR.png

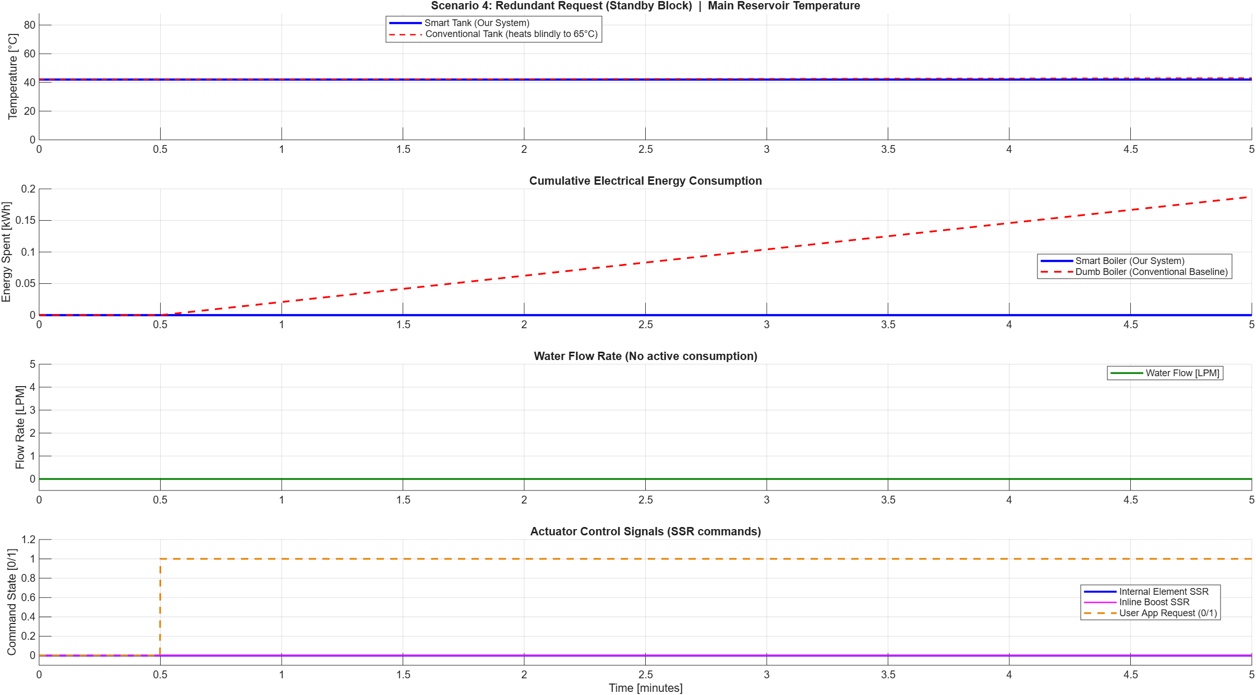
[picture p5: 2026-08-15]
Matlab/figures/Scenario_4_RedundantRequest.png

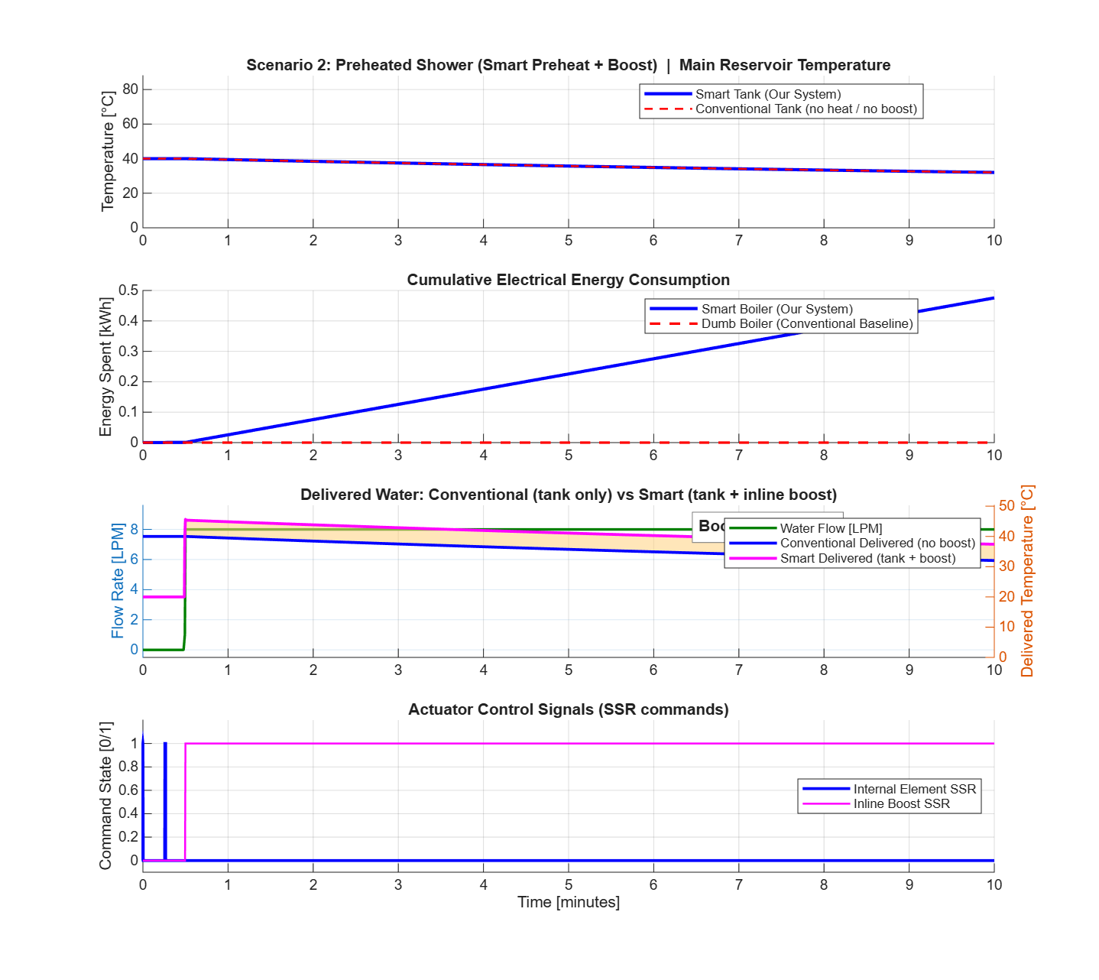
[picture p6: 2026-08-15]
Matlab/figures/Scenario_2_PreheatedShower.png

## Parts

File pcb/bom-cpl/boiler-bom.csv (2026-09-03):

Qty | Value | Device | Package | Parts | Description | AVAILABILITY | CHECK_PRICES | COPYRIGHT | DATASHEET | DESCRIPTION | MANUFACTURER | MANUFACTURER_NAME | MANUFACTURER_PART_NUMBER | MF | MP | MPN | OC_FARNELL | OC_NEWARK | PACKAGE | PARTREV | POPULARITY | PRICE | REFDES | SNAPEDA_LINK | SPICEMODEL | SPICEPREFIX | SPICEPREFIXL | STANDARD | TP_SIGNAL_NAME | TYPE
2 |  | 2N2222-NPN-TO92-EBC | TO92-EBC | T2, T3 | NPN Transistror |  |  |  |  |  |  |  |  |  |  |  |  |  |  |  | 0
1 | 1.8k | R-EU_R0603 | R0603 | R10 | RESISTOR, European symbol |  |  |  |  |  |  |  |  |  |  |  |  |  |  |  | 70 |  |  |  |  | R
2 | 100k | R-EU_R0603 | R0603 | R1, R3 | RESISTOR, European symbol |  |  |  |  |  |  |  |  |  |  |  |  |  |  |  | 70 |  |  |  |  | R
6 | 100n | C-EUC0603 | C0603 | C1, C3, C11, C12, C13, C15 | CAPACITOR, European symbol |  |  |  |  |  |  |  |  |  |  |  |  |  |  |  | 73 |  |  |  |  | C
2 | 100nF | C-EUC0603 | C0603 | C5, C14 | CAPACITOR, European symbol |  |  |  |  |  |  |  |  |  |  |  |  |  |  |  | 73 |  |  |  |  | C
2 | 100u | CPOL-USC | PANASONIC_C | C2, C16 | POLARIZED CAPACITOR, American symbol |  |  |  |  |  |  |  |  |  |  |  |  |  |  |  | 5 |  |  |  |  | C
2 | 10k | R-EU_R0603 | R0603 | R5, R11 | RESISTOR, European symbol |  |  |  |  |  |  |  |  |  |  |  |  |  |  |  | 70 |  |  |  |  | R
1 | 10k | R-TRIMM3314G | RTRIM3314G | R7 | Trimm resistor |  |  |  |  |  |  |  |  |  |  |  |  |  |  |  | 0 |  |  |  | X |  | POT
1 | 10n | C-EUC0603 | C0603 | C4 | CAPACITOR, European symbol |  |  |  |  |  |  |  |  |  |  |  |  |  |  |  | 73 |  |  |  |  | C
1 | 10uF | C-EUC0603 | C0603 | C10 | CAPACITOR, European symbol |  |  |  |  |  |  |  |  |  |  |  |  |  |  |  | 73 |  |  |  |  | C
4 | 1k | R-EU_R0603 | R0603 | R2, R4, R6, R16 | RESISTOR, European symbol |  |  |  |  |  |  |  |  |  |  |  |  |  |  |  | 70 |  |  |  |  | R
1 | 1u | C-EUC0603 | C0603 | C6 | CAPACITOR, European symbol |  |  |  |  |  |  |  |  |  |  |  |  |  |  |  | 73 |  |  |  |  | C
2 | 1uF | C-EUC0603 | C0603 | C8, C9 | CAPACITOR, European symbol |  |  |  |  |  |  |  |  |  |  |  |  |  |  |  | 73 |  |  |  |  | C
1 | 22uF | C-EUC0603 | C0603 | C7 | CAPACITOR, European symbol |  |  |  |  |  |  |  |  |  |  |  |  |  |  |  | 73 |  |  |  |  | C
1 | 3.3k | R-EU_R0603 | R0603 | R9 | RESISTOR, European symbol |  |  |  |  |  |  |  |  |  |  |  |  |  |  |  | 70 |  |  |  |  | R
1 | 330 | R-EU_R0603 | R0603 | R17 | RESISTOR, European symbol |  |  |  |  |  |  |  |  |  |  |  |  |  |  |  | 70 |  |  |  |  | R
2 | 4.7k | R-EU_R0603 | R0603 | R8, R15 | RESISTOR, European symbol |  |  |  |  |  |  |  |  |  |  |  |  |  |  |  | 70 |  |  |  |  | R
2 | 470 | R-EU_R0603 | R0603 | R12, R13 | RESISTOR, European symbol |  |  |  |  |  |  |  |  |  |  |  |  |  |  |  | 70 |  |  |  |  | R
1 | 470k | R-EU_R0603 | R0603 | R14 | RESISTOR, European symbol |  |  |  |  |  |  |  |  |  |  |  |  |  |  |  | 70 |  |  |  |  | R
1 | ACS758LCB-050B-PFF-T | ACS758LCB-050B-PFF-T | XDCR_ACS758LCB-050B-PFF-T | U4 | Check availability | In Stock | https://www.snapeda.com/parts/ACS758LCB-050B-PFF-T/Allegro/view-part/?ref=eda |  |  | Current Sensor 50A 1 Channel Hall Effect, Open Loop Bidirectional 5-CB Formed Leads, PFF |  |  |  | Allegro MicroSystems LLC | ACS758LCB-050B-PFF-T |  |  |  | 5-CB-5 Allegro MicroSystems LLC |  |  | None |  | https://www.snapeda.com/parts/ACS758LCB-050B-PFF-T/Allegro/view-part/?ref=snap
6 | BAT54 | BAT54 | SOT23 | D1, D2, D3, D4, D5, D6 | Schottky Diodes |  |  |  |  |  |  |  |  |  |  |  |  |  |  |  | 2
2 | BS170 | BS170 | SOT54E | Q1, Q2 | N-CHANNEL MOS FET |  |  |  |  |  |  |  |  |  |  |  |  |  |  |  | 5
1 | ESP32-C6-DEVKITC-1-N8 | ESP32-C6-DEVKITC-1-N8 | MODULE_ESP32-C6-DEVKITC-1-N8 | U5 |  |  |  |  |  |  | Espressif Systems |  |  |  |  |  |  |  |  | 1.3 |  |  |  |  |  |  |  | Manufacturer Recommendations
1 | FLOW | AK500/3 | AK500/3 | J4 | CONNECTOR |  |  |  |  |  |  |  |  |  |  |  | unknown | unknown |  |  | 3
2 | GREEN | LEDCHIPLED_0603 | CHIPLED_0603 | LED_3V3, LED_5V | LED |  |  |  |  |  |  |  |  |  |  |  |  |  |  |  | 28
1 | HLK-10M05 | HLK-10M05 | CONV_HLK-10M05 | U2 | Check availability | Not in stock | https://www.snapeda.com/parts/HLK-10M05/Hi-link/view-part/?ref=eda |  |  | 10W Ultra-Compact Power Module |  |  |  | Hi-link | HLK-10M05 |  |  |  | Package |  |  | None |  | https://www.snapeda.com/parts/HLK-10M05/Hi-link/view-part/?ref=snap
1 | J_AC_IN | AK500/2 | AK500/2 | J14 | CONNECTOR |  |  |  |  |  |  |  |  |  |  |  | unknown | unknown |  |  | 14
1 | J_MODEM | FE07-1 | FE07 | J2 | FEMALE HEADER |  |  |  |  |  |  |  |  |  |  |  | unknown | unknown |  |  | 3
1 | J_MODEM_AC | MA03-1 | MA03-1 | J1 | PIN HEADER |  |  |  |  |  |  |  |  |  |  |  | unknown | unknown |  |  | 48
1 | LM393N | LM393N | DIL08 | U6 | COMPARATOR |  |  |  |  |  |  |  |  |  |  |  |  |  |  |  | 2
3 | MOUNT-HOLE3.2 | MOUNT-HOLE3.2 | 3,2 | H1, H2, H3 | MOUNTING HOLE with drill center marker |  |  |  |  |  |  |  |  |  |  |  |  |  |  |  | 7
1 | NTC | AK500/2 | AK500/2 | J3 | CONNECTOR |  |  |  |  |  |  |  |  |  |  |  | unknown | unknown |  |  | 14
1 | PTR1TP15R | PTR1TP15R | TP15R | GND | TEST PIN |  |  |  |  |  |  |  |  |  |  |  |  |  |  |  | 0
2 | SN74LV1T34DBVR | SN74LV1T34DBVR | DBV0005A_N | U1, U3 |  |  |  | Copyright (C) 2026 Ultra Librarian. All rights reserved. | https://www.ti.com/lit/gpn/sn74lv1t34 | Single Power Supply BUFFER Logic Level Shifter (no enable) 5-SOT-23 -40 to 125 |  | Texas Instruments | SN74LV1T34DBVR |  |  |  |  |  |  |  |  |  | RefDes |  |  |  |  |  |  | TYPE
1 | SSR_AC_EXE | AK500/2 | AK500/2 | J11 | CONNECTOR |  |  |  |  |  |  |  |  |  |  |  | unknown | unknown |  |  | 14
1 | SSR_AC_INT | AK500/2 | AK500/2 | J9 | CONNECTOR |  |  |  |  |  |  |  |  |  |  |  | unknown | unknown |  |  | 14
1 | SSR_DC_EXE | AK500/2 | AK500/2 | J10 | CONNECTOR |  |  |  |  |  |  |  |  |  |  |  | unknown | unknown |  |  | 14
1 | SSR_DC_INT | AK500/2 | AK500/2 | J8 | CONNECTOR |  |  |  |  |  |  |  |  |  |  |  | unknown | unknown |  |  | 14
1 | TEMP_A | AK500/3 | AK500/3 | J5 | CONNECTOR |  |  |  |  |  |  |  |  |  |  |  | unknown | unknown |  |  | 3
1 | TEMP_B | AK500/3 | AK500/3 | J6 | CONNECTOR |  |  |  |  |  |  |  |  |  |  |  | unknown | unknown |  |  | 3
1 | TEMP_C | AK500/3 | AK500/3 | J7 | CONNECTOR |  |  |  |  |  |  |  |  |  |  |  | unknown | unknown |  |  | 3
2 | TPB2,54 | TPB2,54 | B2,54 | +5V, 3V3 | Test pad |  |  |  |  |  |  |  |  |  |  |  |  |  |  |  | 3

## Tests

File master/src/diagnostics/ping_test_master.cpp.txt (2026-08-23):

// =============================================================================
//  PING TEST — MASTER (ESP32-S3)
//  PURPOSE: Prove the PLC link works with ZERO project code.
//           No FreeRTOS, no protocol, no CRC, no LVGL. Just raw UART.
//
//  HOW TO USE:
//    1. In master/src/, rename main.cpp -> main.cpp.bak
//    2. Rename THIS file -> main.cpp  (drop the .txt)
//    3. Build + upload to the master.
//    4. Open the master serial monitor @ 115200.
//    5. To restore the real firmware: delete main.cpp, rename main.cpp.bak -> main.cpp
//
//  WIRING: unchanged — master Serial1 is TX=GPIO17, RX=GPIO13, through the
//          KQ-330 modem, 9600 baud. (Same pins/baud as the real firmware.)
//
//  WHAT YOU SHOULD SEE:
//    - Master prints "[MASTER PING] sent PING #N" once a second.
//    - When the slave replies, master prints "[MASTER GOT] <bytes>".
//    - If you see PONG coming back -> the link works, code is the problem.
//    - If you see nothing coming back -> the link (modems) is the problem.
// =============================================================================
#include <Arduino.h>

#define PLC_TX_PIN 17   // master TX -> KQ-330 modem RX
#define PLC_RX_PIN 13   // master RX <- KQ-330 modem TX
#define PLC_BAUD   9600

static uint32_t last_send = 0;
static uint32_t ping_num  = 0;

void setup() {
    Serial.begin(115200);
    delay(500);
    Serial.println("=== MASTER PING TEST ===");
    Serial1.begin(PLC_BAUD, SERIAL_8N1, PLC_RX_PIN, PLC_TX_PIN);
    Serial.printf("[MASTER PING] Serial1 up: TX=GPIO%d RX=GPIO%d @ %d baud\n",
                  PLC_TX_PIN, PLC_RX_PIN, PLC_BAUD);
}

void loop() {
    // 1. Send a PING once a second
    if (millis() - last_send >= 1000UL) {
        last_send = millis();
        ping_num++;
        Serial1.printf("PING%lu\n", (unsigned long)ping_num);
        Serial.printf("[MASTER PING] sent PING #%lu\n", (unsigned long)ping_num);
    }

    // 2. Print anything that arrives (raw)
    while (Serial1.available()) {
        char c = (char)Serial1.read();
        Serial.printf("[MASTER GOT] 0x%02X '%c'\n", (uint8_t)c,
                      (c >= 32 && c < 127) ? c : '.');
    }
}

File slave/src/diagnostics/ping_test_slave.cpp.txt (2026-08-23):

// =============================================================================
//  PING TEST — SLAVE (ESP32-C6)
//  PURPOSE: Prove the PLC link works with ZERO project code.
//           No FreeRTOS, no protocol, no CRC, no sensors. Just raw UART.
//
//  HOW TO USE:
//    1. In slave/src/, rename main.cpp -> main.cpp.bak
//    2. Rename THIS file -> main.cpp  (drop the .txt)
//    3. Build + upload to the slave.
//    4. Open the slave serial monitor @ 115200.
//    5. To restore the real firmware: delete main.cpp, rename main.cpp.bak -> main.cpp
//
//  WIRING: unchanged — slave Serial1 is TX=GPIO11, RX=GPIO10, through the
//          KQ-330 modem, 9600 baud. (Same pins/baud as the real firmware.)
//
//  WHAT YOU SHOULD SEE:
//    - Every 5s: "[SLAVE PING] raw bytes seen in last 5s: N"
//      (N > 0 means bytes ARE crossing the modems, even if garbled.)
//    - When a full PING line arrives, slave prints "[SLAVE GOT] <line>"
//      and replies "PONG".
//    - The master should then print the PONG it receives.
//
//  READING THE RESULT (evening test):
//    * Master sees PONG          -> link fully works; bug is in project code.
//    * Slave "raw bytes" > 0 but no PONG at master -> link works one way / noisy.
//    * Slave "raw bytes" == 0    -> nothing crosses the modems at all -> hardware
//                                   (modems, wiring to modem, power line/phase).
// =============================================================================
#include <Arduino.h>

#define PLC_TX_PIN 11   // slave TX -> KQ-330 modem RX
#define PLC_RX_PIN 10   // slave RX <- KQ-330 modem TX
#define PLC_BAUD   9600

static uint32_t last_report = 0;
static uint32_t raw_bytes   = 0;
static char     line_buf[64];
static uint8_t  line_len    = 0;

void setup() {
    Serial.begin(115200);
    delay(500);
    Serial.println("=== SLAVE PING TEST ===");
    Serial1.begin(PLC_BAUD, SERIAL_8N1, PLC_RX_PIN, PLC_TX_PIN);
    Serial.printf("[SLAVE PING] Serial1 up: TX=GPIO%d RX=GPIO%d @ %d baud\n",
                  PLC_TX_PIN, PLC_RX_PIN, PLC_BAUD);
    last_report = millis();
}

void loop() {
    // 1. Read raw bytes, count them, assemble lines
    while (Serial1.available()) {
        char c = (char)Serial1.read();
        raw_bytes++;

        if (c == '\n' || line_len >= sizeof(line_buf) - 1) {
            line_buf[line_len] = '\0';
            if (line_len > 0) {
                Serial.printf("[SLAVE GOT] \"%s\"  -> replying PONG\n", line_buf);
                Serial1.printf("PONG\n");   // reply so the master can hear us
            }
            line_len = 0;
        } else if (c >= 32 && c < 127) {
            line_buf[line_len++] = c;
        }
    }

    // 2. Every 5s report how many raw bytes crossed the wire
    if (millis() - last_report >= 5000UL) {
        Serial.printf("[SLAVE PING] raw bytes seen in last 5s: %lu\n",
                      (unsigned long)raw_bytes);
        raw_bytes   = 0;
        last_report = millis();
    }
}

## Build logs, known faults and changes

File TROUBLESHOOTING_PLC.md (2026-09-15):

# PLC Communication Troubleshooting — KQ-330 Link

**Use this when installing the system, or if master ↔ slave are not communicating.**
Work top-to-bottom, in order. The communication firmware is stable, so start with
the **physical modem link** (wiring, power, mains phase) before touching code.

---

## 0. Symptom reference

| Where | Healthy | Link problem |
|---|---|---|
| Master monitor | `[M<-S]` lines with matching seq | `[COMMS] No STATUS received within 3s` |
| Slave monitor  | `[S<-M]` lines / mode switches | only `[SLAVE]` heartbeat, no `[S<-M]` |
| Ping test (slave) | `[SLAVE GOT] "PING5"` clean text | garbage bytes `0xFF 0x7F 0xFE…` |

**Rule of thumb:** if the ping test shows the master sending **clean** `PING` but
the slave receiving garbage, the ESPs and code are fine — check the **KQ-330
modem link** (hardware), not the firmware.

---

## 1. First: read, don't touch (2 min)

1. Open **both** serial monitors @ 115200.
2. Master: is it printing `[M->S]` every second? (It's transmitting — good.)
3. Slave: is it printing its heartbeat? (It's alive — good.)
4. Note whether either side shows the *other* side's data. If neither does →
   the link is down; continue.

---

## 2. Isolate the ESPs from the modems (prove the code is fine)

Flash the **ping-test branch** on both boards — pure raw UART, no project code:
```
git checkout ping-test
# flash master, flash slave
```
Watch the slave monitor:
- **Clean `PING` text** → code + ESPs are perfect. Go to Section 3 (modem link).
- **Garbage bytes** → the corruption is downstream of the ESP (modem link). Section 3.
- **Zero bytes, master ON** → nothing crosses at all → Section 3 (dead link / power / phase).

> To confirm the bytes come from the master: power the master OFF. The slave's
> `raw bytes` count should drop to 0. If it stays > 0, that's independent line noise.

Restore real firmware afterwards: `git checkout v7` (or `v9_merge`) and reflash.

---

## 3. Test the modem link ALONE with a USB-to-UART adapter (the key tool)

A USB↔UART adapter (FTDI / CP2102 / CH340) lets you drive the modems from a PC
terminal with **no ESP involved at all**. This is the fastest way to catch a bad
modem, bad coupling, or a noisy line.

> ⚠️ Level warning: the KQ-330 DIN/DOUT are **5V TTL** (see README §2.3). Use a
> **5V-logic** adapter, or a 3.3V adapter that is 5V-tolerant on RX. Match the
> adapter baud to the modems (start at **9600 8N1**).

### Test 3A — End-to-end modem loopback (no ESPs)
Wire one adapter across BOTH modems:
```
Adapter TX  → Modem A DIN
Modem A  ── powerline ──  Modem B
Modem B DOUT → Adapter RX
Adapter GND → common GND with the modems
```
Both modems powered from mains, **same power strip**. Open a serial terminal on
the adapter @ 9600. Type `PING` (or use RealTerm/PuTTY to send text).
- **You see clean `PING` echoed back** → the modem link WORKS. The fault is at the
  ESP↔modem wiring/solder. Go to Section 4.
- **Garbage or nothing** → the modem link itself is bad. Go to Section 5.

### Test 3B — One modem at a time (if 3A fails)
Confirm each modem individually: adapter TX → Modem DIN, scope/second adapter on
the powerline side if available. Simplest: swap in a known-good modem and repeat 3A.

### Test 3C — Check ESP → modem UART
Disconnect the modem's DIN from the ESP TX. Connect adapter RX → ESP TX pin
(master GPIO17 or slave GPIO11). You should see the ESP's clean output on the PC.
Confirms the ESP TX pin + wire are good.

---

## 4. If the modem link is good but ESP↔modem is suspect

1. **Reseat / re-solder** the 3 wires between each ESP and its modem: TX, RX, GND.
   A single cold joint on **DOUT** produces `0xFF`-heavy garbage.
2. Verify pins in `config.h`: master TX=17 RX=13; slave TX=11 RX=10; baud 9600.
3. Master TX (17) → Modem DIN; Modem DOUT → Master RX (13). **Do not swap.**
4. Same for slave: TX(11)→DIN, DOUT→RX(10).
5. Check the slave RX level shifter (U3) and master GPIO13 (5V TTL, no pull-up).

---

## 5. If the modem link itself is bad (Test 3A garbage)

Try in order, re-testing 3A after each:
1. **Same electrical phase** — both modems on the **same outlet / power strip**.
   Different phases = no/garbled link (README §2.3). This is the #1 cause.
2. **Remove noise sources** — unplug chargers, LED lamps, laptop bricks, motors,
   switching supplies on the same circuit. They swamp the PLC carrier.
3. **Power-cycle both modems** — unplug from mains 10 s, replug. Confirm each
   modem's power LED is lit.
4. **Check modem baud/config** — confirm both KQ-330 units are set to the **same**
   UART baud (9600) and the same channel/mode (DIP switches or config, per the
   modem's datasheet). A drifted/reset modem garbles everything.
5. **Swap a modem** — substitute a known-good KQ-330 to find a dead unit.
6. **Coupling** — verify the mains-coupling network (caps/transformer) to each
   modem is intact and connected.

---

## 6. Once the link is clean

1. `git checkout v7` (known-good) or `v9_merge` (latest) on both boards.
2. Reflash master and slave.
3. Confirm all four log lines appear with matching seq numbers:
   ```
   [M->S] ... | [S<-M] ...      (master→slave)
   [S->M] ... | [M<-S] ...      (slave→master)
   ```

---

## Appendix — Known-good facts (do not re-investigate)

- Protocol, pins, baud, and receive code are **identical** across v3 / v7 / v9.
- `boiler_protocol.h` is **byte-identical** between master and slave.
- Timing constants (DO NOT CHANGE): 1000 ms CMD cadence, 3000 ms STATUS wait,
  200 ms guard, 2 ms/byte, 500 ms quiet, 5000 ms watchdog.
- Both builds are pinned to the same toolchain (pioarduino 53.03.11 / Arduino
  core 3.1.1). Do not revert the slave to bare `platform = espressif32` — it
  breaks ESP32-C6 `Serial1` RX.

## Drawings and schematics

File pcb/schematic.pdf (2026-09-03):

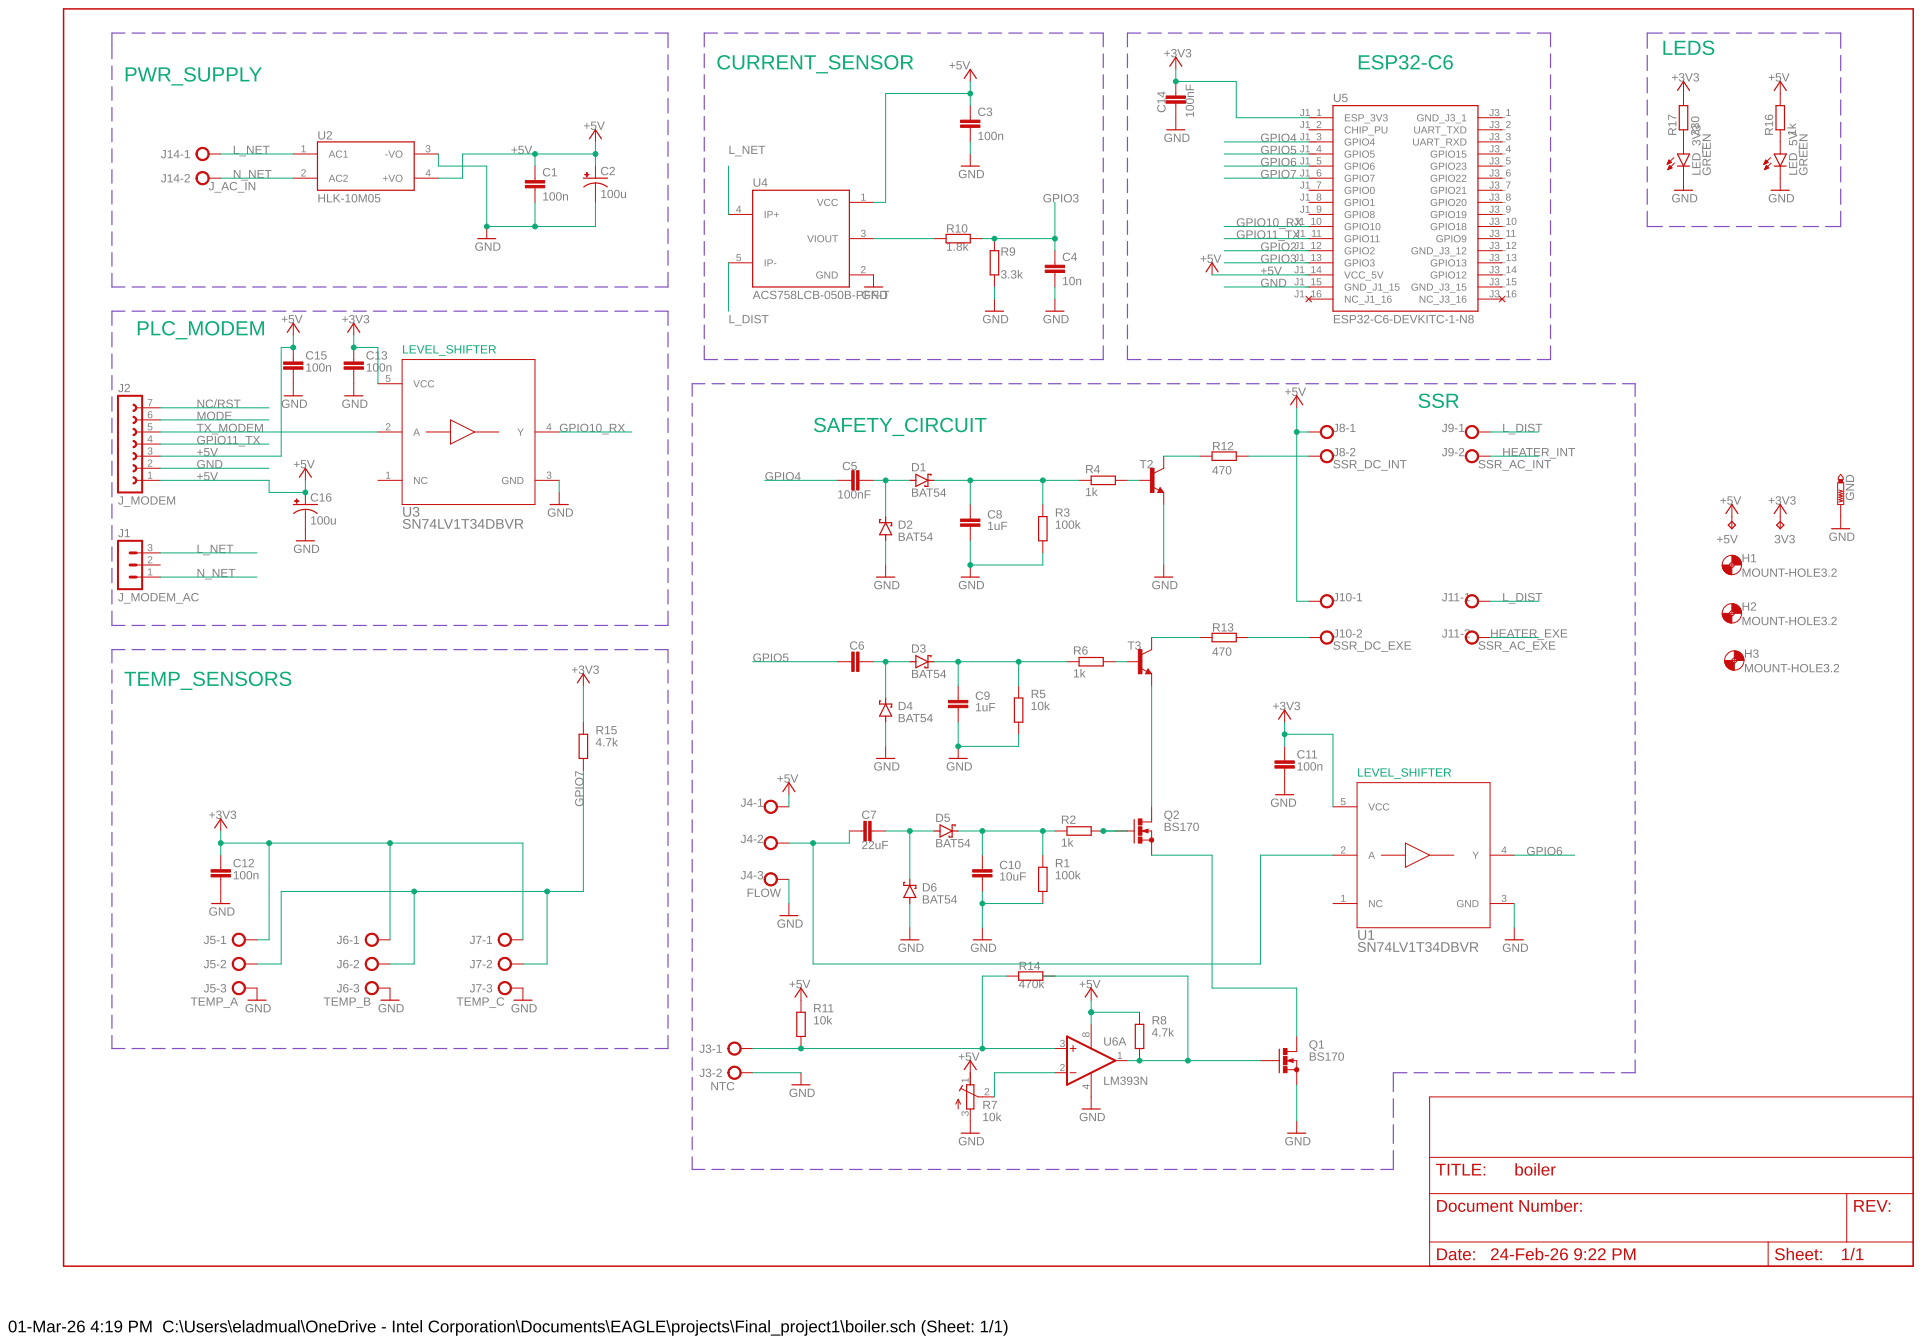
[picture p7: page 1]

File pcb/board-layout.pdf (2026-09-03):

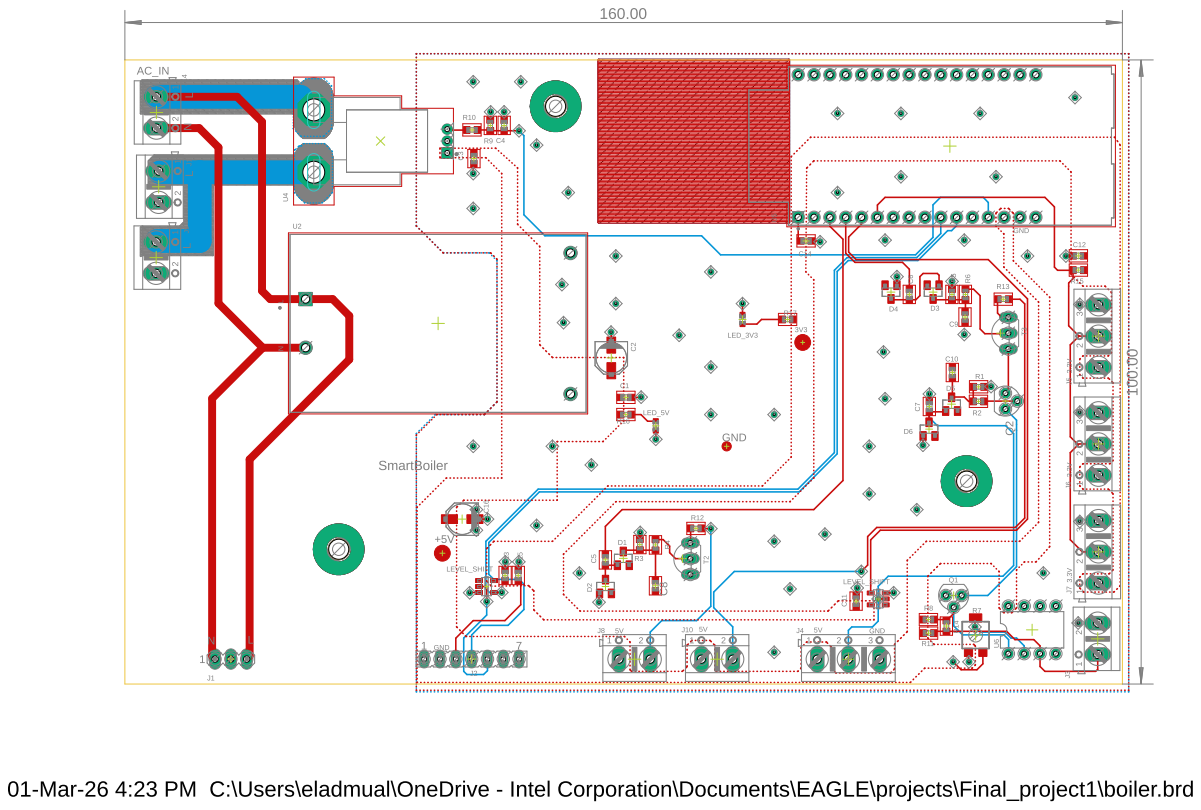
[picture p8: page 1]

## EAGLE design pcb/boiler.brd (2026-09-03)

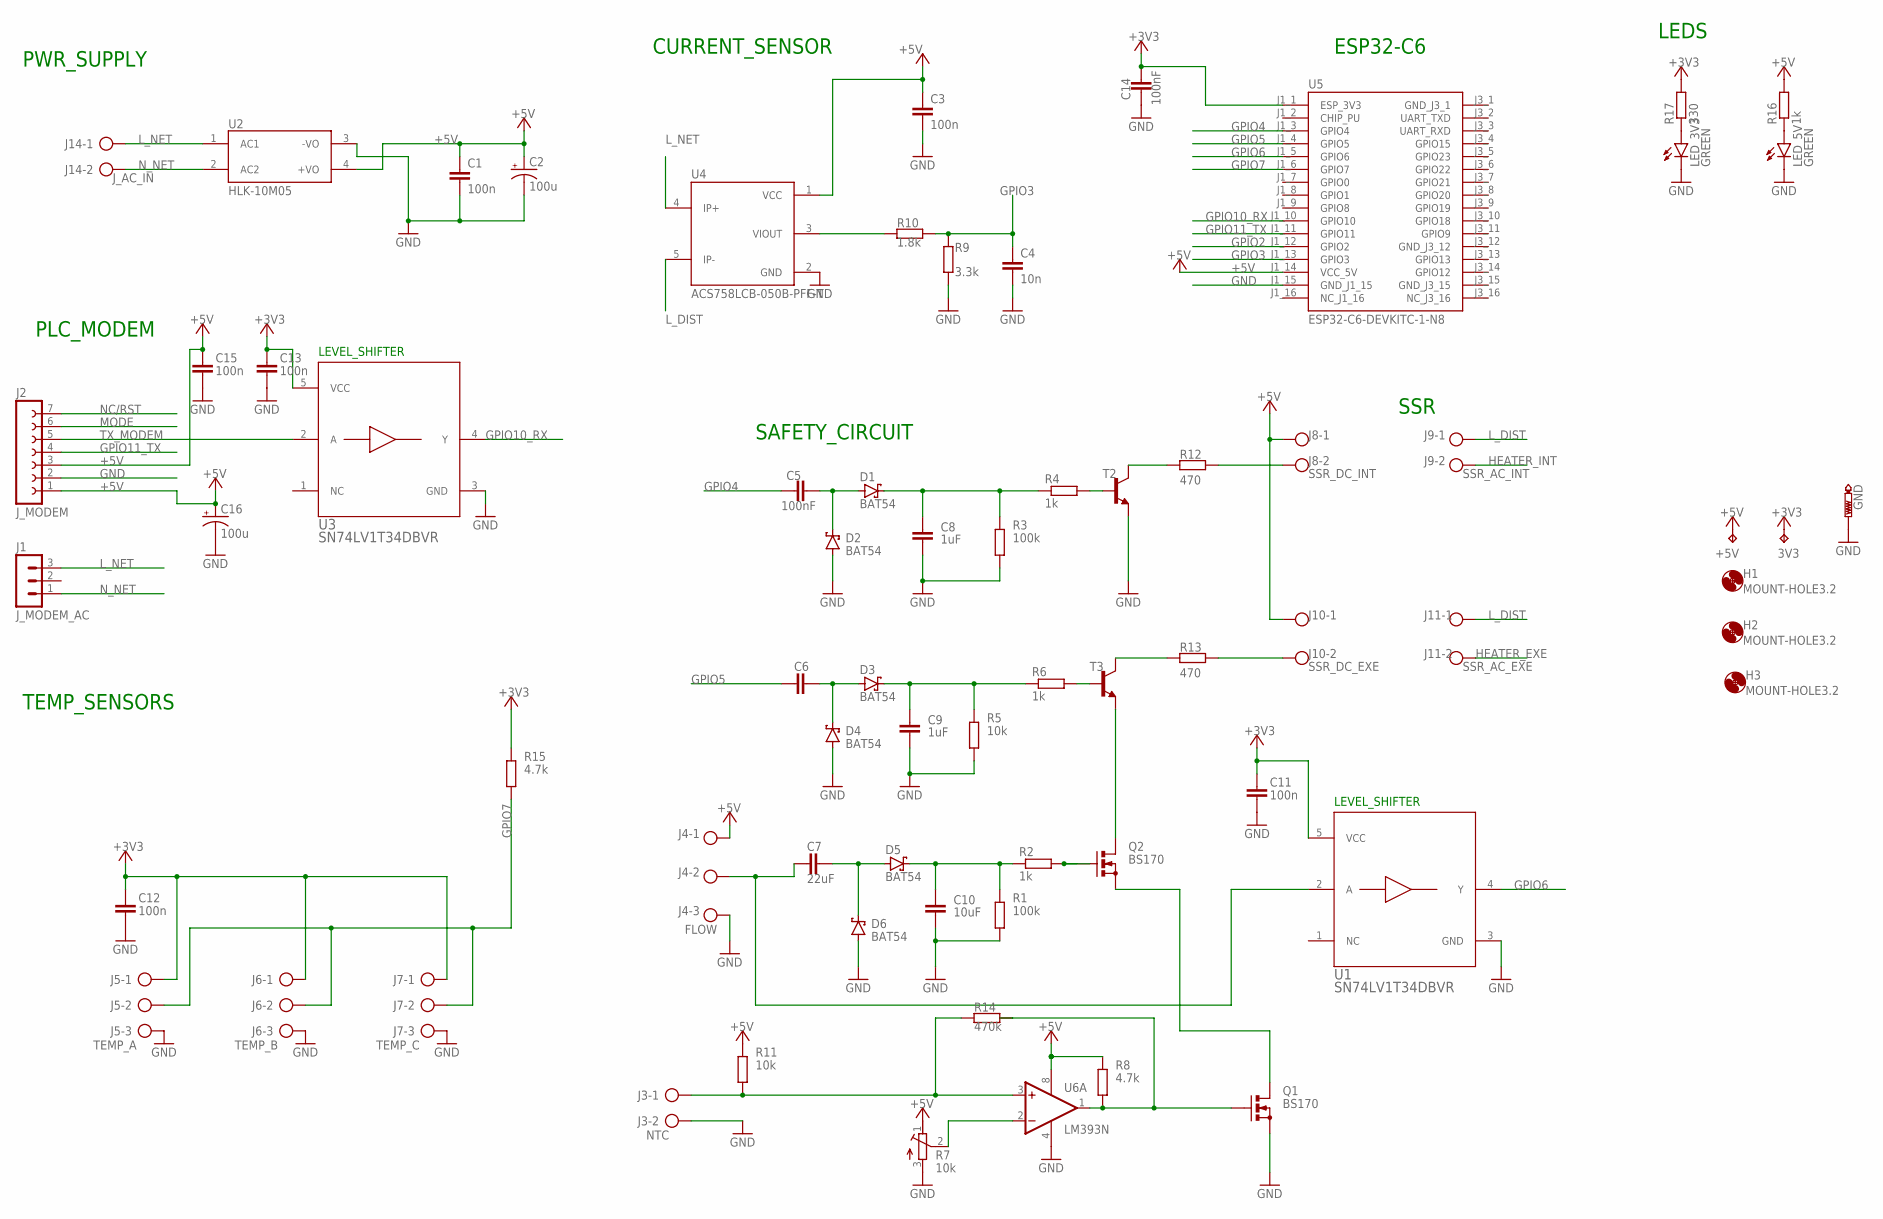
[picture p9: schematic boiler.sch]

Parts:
3V3: TPB2,54; B2,54
+5V: TPB2,54; B2,54
C1, C3, C11, C12, C13, C15: 100n; C0603
C2, C16: 100u; PANASONIC_C
C4: 10n; C0603
C5, C14: 100nF; C0603
C6: 1u; C0603
C7: 22uF; C0603
C8, C9: 1uF; C0603
C10: 10uF; C0603
D1, D2, D3, D4, D5, D6: BAT54; SOT23
GND: PTR1TP15R; TP15R
H1, H2, H3: MOUNT-HOLE3.2; 3,2
J1: J_MODEM_AC; MA03-1
J2: J_MODEM; FE07
J3: NTC; AK500/2
J4: FLOW; AK500/3
J5: TEMP_A; AK500/3
J6: TEMP_B; AK500/3
J7: TEMP_C; AK500/3
J8: SSR_DC_INT; AK500/2
J9: SSR_AC_INT; AK500/2
J10: SSR_DC_EXE; AK500/2
J11: SSR_AC_EXE; AK500/2
J14: J_AC_IN; AK500/2
LED_3V3, LED_5V: GREEN; CHIPLED_0603
Q1, Q2: BS170; SOT54E
R1, R3: 100k; R0603
R2, R4, R6, R16: 1k; R0603
R5, R11: 10k; R0603
R7: 10k; RTRIM3314G
R8, R15: 4.7k; R0603
R9: 3.3k; R0603
R10: 1.8k; R0603
R12, R13: 470; R0603
R14: 470k; R0603
R17: 330; R0603
T2, T3: 2N2222-NPN-TO92-EBC; TO92-EBC
U1, U3: SN74LV1T34DBVR; DBV0005A_N
U2: HLK-10M05; CONV_HLK-10M05
U4: ACS758LCB-050B-PFF-T; XDCR_ACS758LCB-050B-PFF-T
U5: ESP32-C6-DEVKITC-1-N8; MODULE_ESP32-C6-DEVKITC-1-N8
U6: LM393N; DIL08

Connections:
+3V3: 3V3.TP, C11.2, C12.2, C13.2, C14.2, J5.1, J6.1, J7.1, R15.2, R17.2, U1.5 (VCC), U3.5 (VCC), U5.J1_1 (ESP_3V3)
+5V: +5V.TP, C1.2, C2.+, C3.1, C15.2, C16.+, J2.1, J2.3, J4.1, J8.1, J10.1, R7.1 (E), R8.2, R11.2, R16.2, U2.4 (+VO), U4.1 (VCC), U5.J1_14 (VCC_5V), U6.8 (V+)
GND: C1.1, C2.-, C3.2, C4.2, C8.2, C9.2, C10.2, C11.1, C12.1, C13.1, C14.1, C15.1, C16.-, D2.1 (A), D4.1 (A), D6.1 (A), GND.TP, J2.2, J3.2, J4.3, J5.3, J6.3, J7.3, LED_3V3.C, LED_5V.C, Q1.S, R1.1, R3.1, R5.1, R7.3 (A), R9.1, T2.E, U1.3 (GND), U2.3 (-VO), U3.3 (GND), U4.2 (GND), U5.J1_15 (GND_J1_15), U6.4 (V-)
GND_J3_1: U5.J3_1 (GND_J3_1)
GND_J3_12: U5.J3_12 (GND_J3_12)
GND_J3_15: U5.J3_15 (GND_J3_15)
GPIO2: U5.J1_12 (GPIO2)
GPIO3: C4.1, R9.2, R10.1, U5.J1_13 (GPIO3)
GPIO4: C5.1, U5.J1_3 (GPIO4)
GPIO5: C6.1, U5.J1_4 (GPIO5)
GPIO6: U1.4 (Y), U5.J1_5 (GPIO6)
GPIO7: J5.2, J6.2, J7.2, R15.1, U5.J1_6 (GPIO7)
GPIO10_RX: U3.4 (Y), U5.J1_10 (GPIO10)
GPIO11_TX: J2.4, U5.J1_11 (GPIO11)
HEATER_EXE: J11.2
HEATER_INT: J9.2
L_DIST: J9.1, J11.1, U4.5 (IP-)
L_NET: J1.3, J14.1, U2.1 (AC1), U4.4 (IP+)
MODE: J2.6
unnamed: C7.1, J4.2, U1.2 (A)
unnamed: C5.2, D1.1 (A), D2.3 (C)
unnamed: C8.1, D1.3 (C), R3.2, R4.1
unnamed: R4.2, T2.B
unnamed: R10.2, U4.3 (VIOUT)
unnamed: C7.2, D5.1 (A), D6.3 (C)
unnamed: C10.1, D5.3 (C), R1.2, R2.1
unnamed: Q2.G, R2.2
unnamed: LED_5V.A, R16.1
unnamed: C6.2, D3.1 (A), D4.3 (C)
unnamed: C9.1, D3.3 (C), R5.2, R6.1
unnamed: R6.2, T3.B
unnamed: Q2.D, T3.E
unnamed: R13.2, T3.C
unnamed: R12.2, T2.C
unnamed: R7.2 (S), U6.2 (-IN)
unnamed: Q1.D, Q2.S
unnamed: J3.1, R11.1, R14.2, U6.3 (+IN)
unnamed: J8.2, R12.1
unnamed: J10.2, R13.1
unnamed: LED_3V3.A, R17.1
unnamed: Q1.G, R8.1, R14.1, U6.1 (OUT)
NC/RST: J2.7
N_NET: J1.1, J14.2, U2.2 (AC2)
TX_MODEM: J2.5, U3.2 (A)

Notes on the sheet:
TEMP_SENSORS
PLC_MODEM
PWR_SUPPLY
SAFETY_CIRCUIT
CURRENT_SENSOR
LEVEL_SHIFTER
ESP32-C6
SSR
LEDS

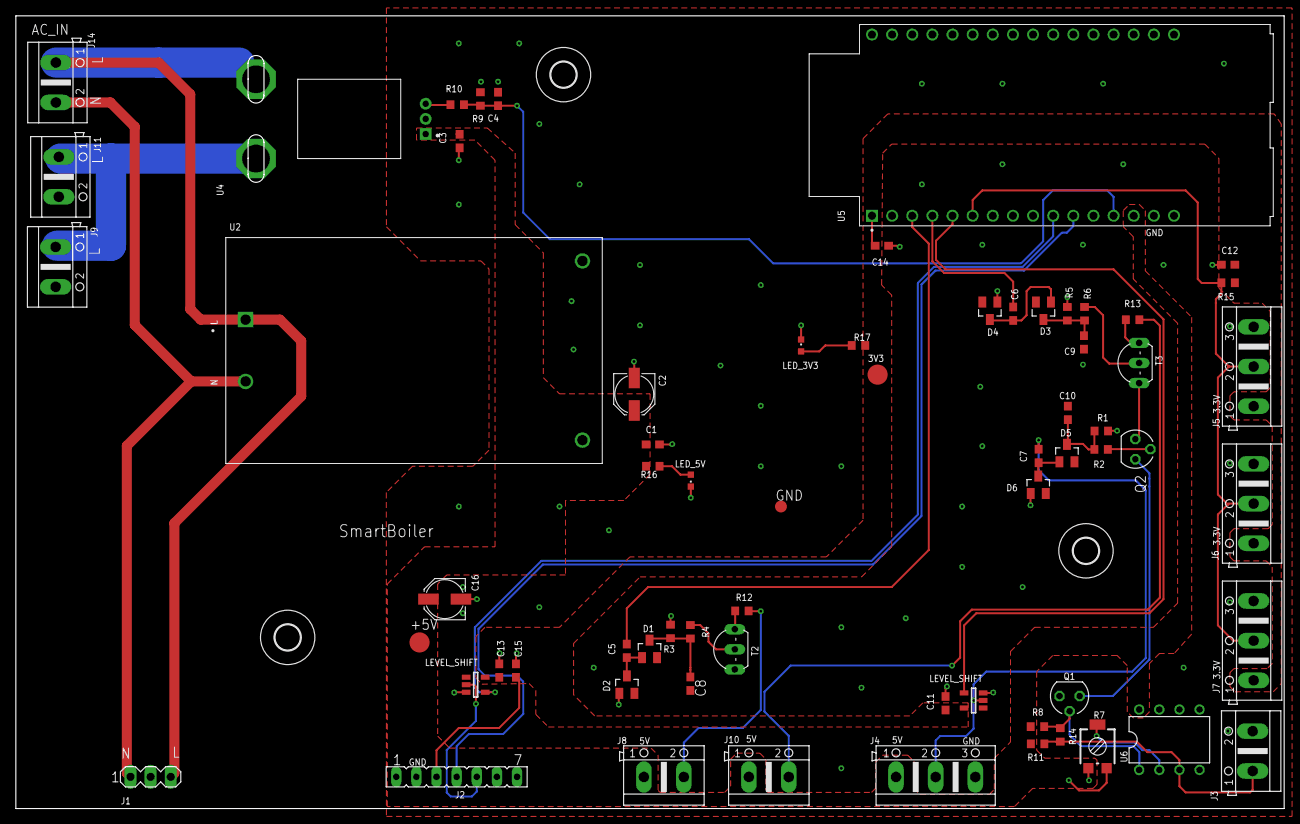
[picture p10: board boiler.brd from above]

Board: 2 copper layers, 160.0 x 100.0 mm, 69 parts (0 on the bottom side), 36 nets.

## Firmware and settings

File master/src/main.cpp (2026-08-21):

#include <Arduino.h>
#include "ui_manager.h"
#include "DataManager.h"
#include "smart_preheat.h"
#include "SystemManagerTest.h"
#include "app_mode.h"
#include "demo_scenarios.h"
#include <WiFi.h>
#include <time.h>

// Declaration of communication function (located in comms_master.cpp)
extern void TaskMasterComms(void * pvParameters);

namespace {
const char* kSetupApSsid = "Boiler-Setup";
const char* kSetupApPassword = "12345678";
const char* kNtpServer1 = "pool.ntp.org";
const char* kNtpServer2 = "time.nist.gov";
const char* kNtpServer3 = "time.google.com";
const char* kTimezoneIsrael = "IST-2IDT,M3.4.4/26,M10.5.0";

void startSetupAccessPoint() {
    WiFi.mode(WIFI_AP_STA);

    if (WiFi.softAP(kSetupApSsid, kSetupApPassword)) {
        Serial.printf("Setup AP started. SSID: %s, IP: %s\n",
                      kSetupApSsid,
                      WiFi.softAPIP().toString().c_str());
    } else {
        Serial.println("Failed to start setup AP");
    }
}

bool syncTimeFromInternet() {
    if (WiFi.status() != WL_CONNECTED) {
        Serial.println("WiFi not connected, skipping NTP sync");
        return false;
    }

    Serial.println("Synchronizing time from NTP...");
    configTime(0, 0, kNtpServer1, kNtpServer2, kNtpServer3);
    setenv("TZ", kTimezoneIsrael, 1);
    tzset();

    struct tm timeinfo;
    for (int attempt = 0; attempt < 10; ++attempt) {
        if (getLocalTime(&timeinfo, 1000)) {
            Serial.printf("Time sync OK: %04d-%02d-%02d %02d:%02d:%02d\n",
                          timeinfo.tm_year + 1900,
                          timeinfo.tm_mon + 1,
                          timeinfo.tm_mday,
                          timeinfo.tm_hour,
                          timeinfo.tm_min,
                          timeinfo.tm_sec);
            return true;
        }
        Serial.println("Waiting for NTP time...");
    }

    Serial.println("NTP sync failed");
    return false;
}

bool updateUiClockFromSystem() {
    struct tm timeinfo;
    if (!getLocalTime(&timeinfo, 100)) {
        return false;
    }

    char date_buf[16];
    strftime(date_buf, sizeof(date_buf), "%d.%m.%Y", &timeinfo);
    UI_UpdateTime(timeinfo.tm_hour, timeinfo.tm_min);
    UI_UpdateDate(date_buf);
    return true;
}
}

void setup() {
    Serial.begin(115200);
    delay(1000);
    Serial.println("--- MASTER UNIT STARTED ---");
    
    // 0. Initialize data storage (SPIFFS)
    DataManager::init();

    // Restore persisted app mode (DEMO / REALTIME). If no file exists yet
    // (first boot), the default MODE_DEMO from app_mode.cpp stands.
    uint8_t saved_mode = 0;
    if (DataManager::loadAppMode(saved_mode)) {
        appMode = (AppMode)saved_mode;
        Serial.printf("[BOOT] Restored persisted mode: %s\n",
                      appMode == MODE_DEMO ? "DEMO" : "REALTIME");
    } else {
        Serial.println("[BOOT] No persisted mode — defaulting to DEMO");
    }

    // Load the smart-preheat learning history (must come after SPIFFS is up).
    SmartPreheat::init();
    WiFi.persistent(false);
    WiFi.setSleep(false);

    // Keep station mode available for scanning/connecting, and AP mode
    // available as a local fallback network for first-time setup.
    WiFi.mode(WIFI_AP_STA);
    
    // 1. Initialize display and UI
    UI_Init();
    
    // 2. Try to reconnect to saved WiFi
    bool wifi_connected = false;
    String saved_ssid, saved_password;
    if(DataManager::loadWiFiCredentials(saved_ssid, saved_password)) {
        Serial.printf("Found saved WiFi: %s\n", saved_ssid.c_str());
        WiFi.begin(saved_ssid.c_str(), saved_password.c_str());
        
        // Wait for connection
        int timeout = 20;
        while(WiFi.status() != WL_CONNECTED && timeout > 0) {
            delay(500);
            Serial.print(".");
            timeout--;
        }
        
        if(WiFi.status() == WL_CONNECTED) {
            Serial.printf("\nReconnected to WiFi! IP: %s\n", WiFi.localIP().toString().c_str());
            wifi_connected = true;
            WiFi.softAPdisconnect(true);
            syncTimeFromInternet();
        } else {
            Serial.println("\nSaved WiFi reconnect failed, enabling setup AP");
            WiFi.disconnect(true, true);
            delay(200);
        }
    } else {
        Serial.println("No saved WiFi found, enabling setup AP");
        WiFi.disconnect(true, true);
        delay(200);
    }

    if (!wifi_connected) {
        startSetupAccessPoint();
    }

    // 3. Start PLC communication task (always — mode switching is runtime)
    Serial.printf("[BOOT] Starting in %s mode (persisted)\n",
                  appMode == MODE_DEMO ? "DEMO" : "REALTIME");
    // PLC comms on Core 0 — completely isolated from LVGL (Core 1).
    // LVGL cannot preempt TaskMasterComms, eliminating inter-byte gaps.
    xTaskCreatePinnedToCore(TaskMasterComms, "MasterComms", 4096, NULL, 2, NULL, 0);
    // Demo scenario runner stays on Core 1. It self-gates: if appMode is
    // REALTIME it idles harmlessly (1s vTaskDelay loop, no scenario output).
    // Only starts scenario playback when appMode == MODE_DEMO.
    xTaskCreatePinnedToCore(TaskAutomatedTestBench, "TestBench", 4096, NULL, 1, NULL, 1);
    
    // Example: Update time periodically (you can use RTC or NTP later)
    // UI_UpdateTime(12, 30);
    // UI_UpdateDate("Jan 10");
    
    // Example: Update weather (connect to weather API later)
    // UI_UpdateWeather(22.5, "sunny");
}

void loop() {
    // Update WiFi status every 5 seconds
    static unsigned long last_wifi_check = 0;
    if(millis() - last_wifi_check > 5000) {
        last_wifi_check = millis();
        UI_UpdateWiFiStatus();
    }

    // Keep time/date synced from the internet when WiFi is available
    static bool last_wifi_connected = false;
    static bool time_synced = false;
    static unsigned long last_ntp_sync = 0;
    static unsigned long last_wifi_retry = 0;
    bool wifi_connected = (WiFi.status() == WL_CONNECTED);

    // setup() only tries the saved network once — the ESP32 WiFi driver
    // does not keep retrying on its own after that attempt fails. Retry
    // periodically here so a boot-time miss (router still starting up,
    // transient AP hiccup, etc.) or a later drop doesn't leave the device
    // stuck offline until someone reconnects it by hand.
    if (!wifi_connected && millis() - last_wifi_retry > 30000UL) {
        last_wifi_retry = millis();
        String saved_ssid, saved_password;
        if (DataManager::loadWiFiCredentials(saved_ssid, saved_password)) {
            Serial.printf("[WiFi] Not connected, retrying saved network: %s\n", saved_ssid.c_str());
            WiFi.begin(saved_ssid.c_str(), saved_password.c_str());
        }
    }

    if (wifi_connected && !last_wifi_connected) {
        Serial.println("[WiFi] Connected — disabling setup AP");
        WiFi.softAPdisconnect(true);
        time_synced = syncTimeFromInternet();
        last_ntp_sync = millis();
    }

    if (!wifi_connected) {
        time_synced = false;
    }

    if (wifi_connected && (!time_synced || millis() - last_ntp_sync > 3600000UL)) {
        time_synced = syncTimeFromInternet();
        last_ntp_sync = millis();
    }

    static unsigned long last_clock_update = 0;
    if (millis() - last_clock_update > 1000) {
        last_clock_update = millis();
        updateUiClockFromSystem();
    }

    last_wifi_connected = wifi_connected;
    
    // Fetch weather: immediately on first boot, then every 10 minutes
    static unsigned long last_weather_fetch = 0;
    static bool weather_fetched_once = false;
    if (!weather_fetched_once || millis() - last_weather_fetch > 600000UL) {
        if (WiFi.status() == WL_CONNECTED) {
            weather_fetched_once = true;
            last_weather_fetch = millis();
            fetchWeather();
        }
    }
    
    // Fetch solar forecast: once per day (on first connection, then again
    // after local midnight). Needs a synced clock to know the local day.
    static int solar_fetch_day = -1;
    if (wifi_connected && time_synced) {
        struct tm timeinfo;
        if (getLocalTime(&timeinfo, 100) && timeinfo.tm_yday != solar_fetch_day) {
            solar_fetch_day = timeinfo.tm_yday;
            fetchSolarForecast();
        }
    }

    // Screensaver disabled per user request
    // checkScreensaver();
    
    vTaskDelay(1000);
}

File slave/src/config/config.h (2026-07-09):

#ifndef CONFIG_H
#define CONFIG_H

// ---------------------------------------------------------------------------
//  Temperature sensors  (DS18B20 on 1-Wire bus)
//  Index:  temps[0] = tank internal
//          temps[1] = boiler outlet
//          temps[2] = boost heater outlet
//  All three sensors share a single 1-Wire bus on GPIO7
// ---------------------------------------------------------------------------
#define PIN_TEMP_BUS          7

// ---------------------------------------------------------------------------
//  Flow sensor  (YF-B6, pulse output)
//  Signal passes through MOSFET Q2 + level shifter U1 before GPIO6
//  Must use hardware interrupt (attachInterrupt)
// ---------------------------------------------------------------------------
#define PIN_FLOW_SENSOR       6

// ---------------------------------------------------------------------------
//  Solid State Relays (AC burst-firing PWM)
//  SSR_INT passes through upper safety channel (T2 BJT)
//  SSR_EXT passes through middle safety channel (T3 BJT) + flow interlock
// ---------------------------------------------------------------------------
#define PIN_SSR_INT           4    // Internal tank heater
#define PIN_SSR_EXT           5    // External inline boost heater

// ---------------------------------------------------------------------------
//  Current sensor  (ACS758LCB-050B, 5V supply, 40mV/A, quiescent = 2.5V)
//  Raw output is divided by a 1.8kΩ / 3.3kΩ voltage divider before GPIO3
//  ADC conversion must reverse the divider — see current_task.cpp
// ---------------------------------------------------------------------------
#define PIN_CURRENT_SENSOR       3
#define CURRENT_DIVIDER_RATIO    (3.3f / 5.1f)   // R2/(R1+R2) = 3.3/(1.8+3.3)
#define ACS758_SENSITIVITY       0.040f            // 40 mV/A
#define ACS758_VREF              2.5f              // Quiescent output at 0A (VCC/2)

// ---------------------------------------------------------------------------
//  PLC modem  (KQ-330, UART — RX=GPIO10 via level shifter U3, TX=GPIO11)
// ---------------------------------------------------------------------------
#define PLC_RX_PIN            10
#define PLC_TX_PIN            11
#define PLC_BAUD              9600

// ---------------------------------------------------------------------------
//  Timing
// ---------------------------------------------------------------------------
#define STATUS_SEND_INTERVAL_MS   1000u   // slave pushes STATUS once per second

#endif // CONFIG_H

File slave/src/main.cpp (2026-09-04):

#include <Arduino.h>
#include "config.h"
#include "shared_data.h"
#include "system_mode.h"
#include "flow_task.h"
#include "temp_task.h"
#include "current_task.h"
#include "safety_task.h"
#include "pwm_task_internal.h"
#include "pwm_task_boost.h"
#include "plc_task.h"
// Note: comms_slave (old JSON) removed - all comms now via binary PLC protocol

void setup() {
    Serial.begin(115200);
    delay(500);
    Serial.println("=== SLAVE UNIT STARTED ===");
    Serial.println("[MODE] Boot mode: DEMO | Auto-switches to REALTIME when master sends without CMD_DEMO_ACTIVE");

    // -----------------------------------------------------------------------
    //  Create FreeRTOS mutexes before any task starts.
    //  All tasks that access shared_data must take the appropriate mutex.
    // -----------------------------------------------------------------------
    guard_temps   = xSemaphoreCreateMutex();
    guard_flow    = xSemaphoreCreateMutex();
    guard_current = xSemaphoreCreateMutex();
    guard_cmd     = xSemaphoreCreateMutex();

    if (!guard_temps || !guard_flow || !guard_current || !guard_cmd) {
        Serial.println("[FATAL] Failed to create mutexes - halting.");
        while (true) { vTaskDelay(pdMS_TO_TICKS(1000)); }
    }

    // -----------------------------------------------------------------------
    //  FreeRTOS task layout � all pinned to Core 0 (ESP32-C6 is single-core)
    //
    //  Priority 4 (highest) : Safety � hard-cuts SSRs, runs every 50 ms
    //  Priority 3           : PWM tasks � time-proportional SSR burst control
    //  Priority 2           : Sensor + PLC tasks
    //  Priority 1 (lowest)  : Serial console (mode switching)
    // -----------------------------------------------------------------------

    // Sensor tasks
    xTaskCreatePinnedToCore(TaskFlow,    "Flow",    4096, NULL, 2, NULL, 0);
    xTaskCreatePinnedToCore(TaskTemp,    "Temp",    4096, NULL, 2, NULL, 0);
    xTaskCreatePinnedToCore(TaskCurrent, "Current", 4096, NULL, 2, NULL, 0);

    // Control tasks
    xTaskCreatePinnedToCore(TaskSafety,       "Safety",  4096, NULL, 4, NULL, 0);
    xTaskCreatePinnedToCore(TaskPWM_Internal, "PWM_Int", 4096, NULL, 3, NULL, 0);
    xTaskCreatePinnedToCore(TaskPWM_Boost,    "PWM_Bst", 4096, NULL, 3, NULL, 0);

    // PLC communication (periodic push + CMD receive)
    xTaskCreatePinnedToCore(TaskPLC,    "PLC",    4096, NULL, 2, NULL, 0);

    // Serial console � mode switching ('b'/'p'/'?')
    xTaskCreatePinnedToCore(TaskSerial, "Serial", 2048, NULL, 1, NULL, 0);
}

void loop() {
    // All work is done in FreeRTOS tasks - loop does nothing
    vTaskDelay(pdMS_TO_TICKS(1000));
}

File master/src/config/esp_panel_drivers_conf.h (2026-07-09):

/*
 * SPDX-FileCopyrightText: 2023-2025 Espressif Systems (Shanghai) CO LTD
 *
 * SPDX-License-Identifier: Apache-2.0
 */
/**
 * @file  esp_panel_drivers_conf.h
 * @brief Configuration file for ESP Panel Drivers
 *
 * This file contains all the configurations needed for ESP Panel Drivers.
 * Users can modify these configurations according to their requirements.
 */

#pragma once

// *INDENT-OFF*

////////////////////////////////////////////////////////////////////////////////////////////////////////////////////////
////////////////////////////////////////////////// Bus Configurations //////////////////////////////////////////////////
////////////////////////////////////////////////////////////////////////////////////////////////////////////////////////
/**
 * @brief Bus driver availability
 *
 * Enable or disable bus drivers used in the factory class. Disable to reduce code size.
 * Set to `1` to enable, `0` to disable.
 */
#define ESP_PANEL_DRIVERS_BUS_USE_ALL                   (1)
#if !ESP_PANEL_DRIVERS_BUS_USE_ALL
    #define ESP_PANEL_DRIVERS_BUS_USE_SPI               (0)
    #define ESP_PANEL_DRIVERS_BUS_USE_QSPI              (0)
    #define ESP_PANEL_DRIVERS_BUS_USE_RGB               (0)
    #define ESP_PANEL_DRIVERS_BUS_USE_I2C               (0)
    #define ESP_PANEL_DRIVERS_BUS_USE_MIPI_DSI          (0)
#endif // ESP_PANEL_DRIVERS_BUS_USE_ALL

/**
 * @brief Controls compilation of unused bus drivers
 *
 * Enable or disable compilation of unused bus drivers.
 * When set to `0`, code for unused bus drivers will be excluded to speed up compilation. At this time,
 * users should ensure that the bus driver is not used.
 *
 * Example with SPI:
 * (CONF1 = ESP_PANEL_DRIVERS_BUS_USE_SPI, CONF2 = ESP_PANEL_DRIVERS_BUS_COMPILE_UNUSED_DRIVERS)
 *
 * | CONF1 | CONF2 | Driver Available ( = CONF1 ^ CONF2) | Factory Support ( = CONF1) |
 * |-------|-------|-------------------------------------|----------------------------|
 * |   0   |   0   |                 No                  |              No            |
 * |   1   |   0   |                 Yes                 |              Yes           |
 * |   0   |   1   |                 Yes                 |              No            |
 * |   1   |   1   |                 Yes                 |              Yes           |
 */
#define ESP_PANEL_DRIVERS_BUS_COMPILE_UNUSED_DRIVERS    (1)

////////////////////////////////////////////////////////////////////////////////////////////////////////////////////////
///////////////////////////////////////////////// LCD Configurations ///////////////////////////////////////////////////
////////////////////////////////////////////////////////////////////////////////////////////////////////////////////////
/**
 * @brief LCD driver availability
 *
 * Enable or disable LCD drivers used in the factory class. Disable to reduce code size.
 * Set to `1` to enable, `0` to disable.
 */
#define ESP_PANEL_DRIVERS_LCD_USE_ALL                   (0)
#if !ESP_PANEL_DRIVERS_LCD_USE_ALL
    #define ESP_PANEL_DRIVERS_LCD_USE_AXS15231B         (0)
    #define ESP_PANEL_DRIVERS_LCD_USE_EK9716B           (0)
    #define ESP_PANEL_DRIVERS_LCD_USE_EK79007           (0)
    #define ESP_PANEL_DRIVERS_LCD_USE_GC9A01            (0)
    #define ESP_PANEL_DRIVERS_LCD_USE_GC9B71            (0)
    #define ESP_PANEL_DRIVERS_LCD_USE_GC9503            (0)
    #define ESP_PANEL_DRIVERS_LCD_USE_HX8399            (0)
    #define ESP_PANEL_DRIVERS_LCD_USE_ILI9341           (0)
    #define ESP_PANEL_DRIVERS_LCD_USE_ILI9881C          (0)
    #define ESP_PANEL_DRIVERS_LCD_USE_JD9165            (0)
    #define ESP_PANEL_DRIVERS_LCD_USE_JD9365            (0)
    #define ESP_PANEL_DRIVERS_LCD_USE_NV3022B           (0)
    #define ESP_PANEL_DRIVERS_LCD_USE_SH8601            (0)
    #define ESP_PANEL_DRIVERS_LCD_USE_SPD2010           (0)
    #define ESP_PANEL_DRIVERS_LCD_USE_ST7262            (0)
    #define ESP_PANEL_DRIVERS_LCD_USE_ST7701            (0)
    #define ESP_PANEL_DRIVERS_LCD_USE_ST7703            (0)
    #define ESP_PANEL_DRIVERS_LCD_USE_ST7789            (0)
    #define ESP_PANEL_DRIVERS_LCD_USE_ST7796            (0)
    #define ESP_PANEL_DRIVERS_LCD_USE_ST77903           (0)
    #define ESP_PANEL_DRIVERS_LCD_USE_ST77916           (0)
    #define ESP_PANEL_DRIVERS_LCD_USE_ST77922           (0)
#endif // ESP_PANEL_DRIVERS_LCD_USE_ALL

/**
 * @brief Controls compilation of unused LCD drivers
 *
 * Enable or disable compilation of unused LCD drivers.
 * When set to `0`, code for unused LCD drivers will be excluded to speed up compilation. At this time,
 * users should ensure that the LCD driver is not used.
 *
 * Example with ILI9341:
 * (CONF1 = ESP_PANEL_DRIVERS_LCD_USE_ILI9341, CONF2 = ESP_PANEL_DRIVERS_LCD_COMPILE_UNUSED_DRIVERS)
 *
 * | CONF1 | CONF2 | Driver Available ( = CONF1 ^ CONF2) | Factory Support ( = CONF1) |
 * |-------|-------|-------------------------------------|----------------------------|
 * |   0   |   0   |                 No                  |              No            |
 * |   1   |   0   |                 Yes                 |              Yes           |
 * |   0   |   1   |                 Yes                 |              No            |
 * |   1   |   1   |                 Yes                 |              Yes           |
 */
#define ESP_PANEL_DRIVERS_LCD_COMPILE_UNUSED_DRIVERS    (1)

////////////////////////////////////////////////////////////////////////////////////////////////////////////////////////
///////////////////////////////////////////////// Touch Configurations /////////////////////////////////////////////////
////////////////////////////////////////////////////////////////////////////////////////////////////////////////////////
/**
 * @brief Touch panel configuration parameters
 */
#define ESP_PANEL_DRIVERS_TOUCH_MAX_POINTS              (10)    // Maximum number of touch points supported
#define ESP_PANEL_DRIVERS_TOUCH_MAX_BUTTONS             (5)     // Maximum number of touch buttons supported
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

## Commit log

2026-03-25 Replace xTaskCreatePinnedToCore with xTaskCreate
    [main.cpp]
2026-03-25 Optimize temperature measurement loop
    Reduced delay for sensor measurement and updated temperature reading logic.
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2026-04-16 feat(ui): build home screen layout with all live slave packet data
    - Add bottom strip: Boost Temp (t2), Flow Rate, Showers Available, Wait Time
    - Add system mode indicator card in center column
    - Add Tank SSR / Boost SSR LED indicators in right column
    - Implement UI_UpdateSensorData() to update all widgets in one LVGL lock
    - Wire comms_master.cpp: replaced UI_UpdateWaterTemp(t1) with UI_UpdateSensorData(t1,t2,flow)
    - Add UI_UpdateBoostTemp, UI_UpdateFlowRate, UI_UpdateSystemMode, UI_UpdateSSRStatus
    - Resize main_row 440->360px, columns 400->320px to accommodate bottom strip
    - Showers derived from 80L tank model; Wait Time from 2kW element heat equation
    [comms_master.cpp, ui_manager.cpp]
2026-04-16 feat(ui): consumer-first redesign - clean dashboard, shower status, demo mode
    [main.cpp, ui_manager.cpp]
2026-04-18 feat(comms): replace JSON with binary PLC protocol (CRC-8, seq numbers)
    [boiler_protocol.h, comms_master.cpp]
2026-04-18 feat(comms): binary PLC protocol - fix all shared_data vars, tasks, and main
    [boiler_protocol.h, config.h, main.cpp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]
2026-04-21 fix(slave): correct ESP32-C6 pinout, board config, and current sensor ADC formula
    [config.h, current_task.cpp, main.cpp]
2026-04-22 fix(slave): set upload port COM8 for ESP32-C6
2026-04-23 fix(slave): Serial2->Serial1 (ESP32-C6 has no Serial2), remove hardcoded COM port
    [plc_comms.cpp]
2026-04-23 fix(slave): use OneWire git HEAD for ESP32-C6 GPIO compatibility
2026-04-23 fix(slave): pin all tasks to Core 0 - ESP32-C6 is single-core
    [main.cpp]
2026-04-23 fix(slave): calibrate ACS758 zero-current at startup, fix ADC attenuation, fix Serial1 log
    [current_task.cpp, plc_comms.cpp]
2026-04-24 fix(slave): init ADC pin before setting attenuation to suppress warning
    [current_task.cpp]
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2026-04-27 fix(slave): don't TX STATUS while mid-reception (half-duplex collision fix)
    [plc_comms.cpp]
2026-04-27 fix(master): change RX pin from GPIO18 to GPIO13 (SD-MISO, free pin)
    [config.h]
2026-04-27 fix(slave): update main.cpp for split PWM tasks (internal + boost)
    [main.cpp]
2026-04-27 fix(slave): add 500ms post-reception quiet time before TX to prevent end-byte collision
    [plc_comms.cpp]
2026-04-27 fix(master): remove loopback test code
    [comms_master.cpp]
2026-04-27 fix(master): wire SystemManager into sendCommand() — replace stale inline PWM logic
    [comms_master.cpp]
2026-04-28 chore: add [TEST FILE] banners, fix temp/current tasks, update UI info bar
    [SystemManagerTest.cpp, current_task.cpp, temp_task.cpp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]
2026-06-01 fix(slave): migrate LEDC API from channel-based to pin-based (ledcAttach)
    [pwm_task_boost.cpp, pwm_task_internal.cpp, safety_task.cpp]
2026-06-01 fix(slave): drive SSR at full DC (255) not 50% PWM — partial conduction with 127
    [pwm_task_boost.cpp, pwm_task_internal.cpp]
2026-06-01 fix(slave): clamp calibrated VREF to nominal if current detected at boot
    [current_task.cpp]
2026-06-01 fix(slave): replace LEDC with plain digitalWrite for SSR control
    [pwm_task_boost.cpp, pwm_task_internal.cpp, safety_task.cpp]
2026-06-01 revert(slave): restore PWM/safety/current tasks to last working state (e7b299a)
    [current_task.cpp, pwm_task_boost.cpp, pwm_task_internal.cpp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]
2026-06-13 fix(master): move s_manager to file scope so handleManualInputs can access it
    [comms_master.cpp]
2026-06-13 refactor(master): replace serial test system with 4 hardcoded test variables
    [comms_master.cpp]
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2026-06-13 fix(slave): SLAVE_TEST_MODE only bypasses safety interlocks, always use real PLC task
    [main.cpp]
2026-06-13 fix(slave): in TEST_MODE bypass flow check in boost PWM and uncommanded-current safety check
    [pwm_task_boost.cpp, safety_task.cpp]
2026-06-18 feat(slave): v4 FreeRTOS refactor - mutexes, SystemMode runtime switching, vTaskDelayUntil periodic push
2026-06-23 docs(ui): add interactive redesign mockup for master touchscreen
    Multi-screen UI prototype (800x480) for the redesign: Home with tiles +
    Auto pre-heat badge, Settings with large temp control, Schedule (smart-learn
    / ready-by per smart-brain.md), full-screen WiFi flow, upgraded Stats with
    shower histogram, and a hidden Diagnostics page. Bigger touch targets and a
    reworked WiFi password flow (save-after-connect instead of a checkbox).
    Design artifact only; not yet ported to LVGL.
2026-06-25 feat(master): port v6 UI redesign mockup into LVGL multi-screen UI
    Replace the single-screen consumer dashboard with 7 navigable pages
    (Home, Settings, Schedule, Network, Password, Stats, Diagnostics)
    matching docs/ui-mockup. Key fix: WiFi password flow now asks "save
    this password?" after a successful connect instead of a pre-connect
    checkbox. Diagnostics/Stats wired to live sensor, PLC, and system-mode
    data instead of placeholder values.
    [comms_master.cpp, ui_manager.cpp]
2026-07-06 fix(master): WiFi scan/status bugs, weather fetch, Stats redesign, Solar Forecast
    Fixes from testing the v6 UI on real hardware:
    - WiFi scan: capture SSID/RSSI before the post-scan mode switch invalidates
    LVGL's cached results (network names were showing blank); give the SSID
    label an explicit color (it was the only unstyled label in the row); wait
    for reconnect to finish before showing network status so it isn't stale.
    - Weather fetch: URL-encode the city name (a literal space broke the
    request silently); log HTTP/JSON failures instead of failing silently.
    - Layout: fix the Connecting-status card being clipped by an undersized
    parent container on the home screen.
    - Screensaver dis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
    [DataManager.cpp, main.cpp, ui_manager.cpp]
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2026-07-09 feat(demo): 20s scenarios, lock UI power btn, clean slave serial (SSR events only)
2026-07-09 fix(slave): update boot message; note BENCH_TEST auto-switches on first master CMD
    [main.cpp]
2026-07-09 fix(demo): Stats power shows slave mock wattage instead of 0W
    [comms_master.cpp]
2026-07-09 fix(slave): mock power SSR_INT=2500W (11.36A), SSR_BOOST=3000W (13.64A)
    [current_task.cpp]
2026-07-09 fix(demo): keep PLC Connected in UI during demo; log timeout only once per event
    [comms_master.cpp, safety_task.cpp]
2026-07-09 fix(comms): bulk-write CMD packet to UART FIFO, eliminating LVGL preemption between bytes
    [comms_master.cpp]
2026-07-09 fix(comms): pin TaskMasterComms to Core 0, isolated from LVGL on Core 1
    [main.cpp]
2026-07-09 fix(protocol): revert CMD to 9 bytes, encode demo state in flag bits (KQ-330 max ~10 bytes)
    [boiler_protocol.h, comms_master.cpp, demo_scenarios.cpp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]
2026-07-09 fix(comms): reset CMD timer after STATUS received, enforce 1s gap for KQ-330 carrier settling
    [comms_master.cpp]
2026-07-09 test: revert to V5 timing - delay(2) per byte + 200ms guard
    [comms_master.cpp]
2026-07-09 fix(kq330): hardcode KQ-330 timing constants - DO NOT CHANGE (2ms byte gap + 200ms guard)
    [comms_master.cpp]
2026-07-09 feat(demo): professional serial logging - fixed-width telemetry + event-driven banners
    [comms_master.cpp, demo_scenarios.cpp, plc_comms.cpp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]
2026-07-09 fix(demo): S5 solar bypass forces pwm=0 override regardless of SystemManager
    [comms_master.cpp, demo_scenarios.cpp]
2026-07-09 docs: update README to v7 - demo framework, 8 scenarios, KQ-330 timing, branch notes
2026-07-09 fix(demo): gate demo_stop_comms by mode, clear demo state on switch, abort cycle on mode change
    [comms_master.cpp, demo_scenarios.cpp, ui_manager.cpp]
2026-07-09 fix(ui): show --- when temp sensor disconnected; fix middle-dot LVGL glyph warning
    [ui_manager.cpp]
2026-07-09 fix(slave): disable uncommanded-current check when VREF out of spec (sensor mis-powered)
    [current_task.cpp, safety_task.cpp]
2026-07-09 fix(slave): S8 uncommanded-current always active in DEMO; REALTIME only when sensor calibrated
    [safety_task.cpp]
2026-07-09 docs: update README v7 - unified mode names, ADC calibration note, verified status
2026-08-08 refactor(slave): rename mutexes to guard_* per project book (Table 15, sec 9.1.9)
    Align FreeRTOS mutex names with the project book:
    mutex_temps/flow/current/cmd -> guard_temps/flow/current/cmd.
    Also document the mandatory 1 kHz SSR carrier in the PWM tasks: the
    hardware watchdog gate is DC-blocking and requires a continuous pulse
    train, so ledcWrite(pin,127) must not be replaced with digitalWrite(HIGH)
    (README SW-3 would break the hardware interlock).
    [current_task.cpp, main.cpp, plc_comms.cpp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]
2026-08-08 test(scenarios): align 8 demo scenarios to Models (book 9.1.8/10)
    Align master/src/demo_scenarios.cpp injected values and timings to the
    authoritative MATLAB scenarios in Models/Models (boiler_params.m):
    S1 20C | S2 40C/8LPM@30s | S3 45C/8LPM@30s | S4 42C
    S5 solar-bypass (compressed live-demo representation)
    S6 idle15/heat15/cut@30s | S7 70C@0.4C/s SW80 HW85 | S8 70C/13.6A/50ms
    Also fix slave HW interlock threshold 86C -> 85C (safety_task.cpp) to
    match the NTC comparator calibration (book 9.1.9) and Models Thw=85.
    Note: S3 boost cutoff (Models 42C vs firmware BOOST_CUTOFF_C=45C) is a
    SystemManager threshold, tracked as a separate task.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
    [demo_scenarios.cpp, safety_task.cpp]
2026-08-08 docs(readme): guard_* names, aligned 8-scenario values/timings, retract SW-3
    - Rename mutex_* -> guard_* to match code and project book Table 15.
    - Update section 6.4 scenario table + section 7 status to the values now
    in demo_scenarios.cpp / Models (S1 20C, S2 40C/8LPM@30s, S3 45C/8LPM@30s,
    S6 20C phased, S7 70->86C @0.4C/s HW 85C, S8 70C).
    - Retract BUG-3/SW-3: the 1 kHz LEDC carrier is REQUIRED by the DC-blocking
    hardware watchdog gate; replacing it with digitalWrite(HIGH) would break it.
2026-08-08 fix(systemmanager): boost cutoff 45->42C, flow threshold 0.5->1.0 LPM
    Align SystemManager thresholds to the authoritative Models (book 9.1.8):
    - BOOST_CUTOFF_C 45 -> 42 (Models S3 T_target_logic=42).
    - FLOW_THRESHOLD_LPM 0.5 -> 1.0 (Models Flow_Min_LPM=1). Also removes a
    latent inconsistency where master triggered boost at >0.5 LPM while the
    slave interlock/safety require >=1.0 LPM (0.5-1.0 would command boost AND fault).
    [SystemManager.cpp, SystemManager.h]
2026-08-08 fix(comms): real PLC watchdog for plcConnected (BUG-2 / SW-1)
    REALTIME no longer hardcodes plcConnected=true. sendCommand() now derives it
    from a STATUS-timeout: plcConnected = status_ever && (now - last_status_ms < 5s).
    A valid STATUS refreshes last_status_ms; before the first STATUS the link is
    treated as disconnected (fail-safe), so SystemManager holds SAFETY_OVERRIDE
    until the slave is heard and fires it again after 5s of silence. DEMO path
    (driven by demo_stop_comms for S6) is unchanged.
    [comms_master.cpp]
2026-08-08 docs(readme): 2-mode slave cleanup, updated SM constants, BUG-2/SW-1 fixed
    - Section 6.2: slave modes reduced to MODE_DEMO / MODE_REALTIME (was 3-mode
    BENCH_TEST/DEMO/PRODUCTION) to match the code.
    - Section 3.1: BOOST_CUTOFF_C 42C, FLOW_THRESHOLD_LPM 1.0, state-table conditions.
    - BUG-2 and SW-1 marked FIXED (PLC watchdog).
2026-08-08 feat(master): first-time Setup Guide wizard; fix WiFi auto-reconnect; fix build config
    master/ui_manager.cpp: add a 3-step Setup Guide (target temperature,
    household size, ready-by time) reachable from Settings > Setup. Values
    are persisted via DataManager and reloaded at boot so they survive a
    reboot, which target_temperature previously did not.
    master/main.cpp: the ESP32 WiFi driver does not retry saved credentials
    on its own after a failed connection attempt, and setup() only tried
    once. loop() now retries periodically while disconnected, and shuts
    down the fallback setup AP once a delayed reconnect succeeds.
    master/platformio.ini: the board-specific env's lib_deps was replacing
    (not ex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
    [main.cpp, ui_manager.cpp]
2026-08-08 feat(brain): self-learning preheat decision tree (V1)
    Fresh, simple decision-tree brain on the master that learns household shower
    times and pre-heats the tank so hot water is ready on time. Not AI — transparent
    If/Else, per the project book.
    - smart_preheat.{h,cpp}: 96-slot (15-min) shower histogram + 60s decision tree.
    Reliable after >=7 days and a slot seen >=3x. Modes: DUMB / READY_BY / SMART.
    - DataManager: save/loadPreheat -> SPIFFS /preheat.json (survives reboots).
    - ui_manager: UI_GetOpMode/ReadyByMinute/HouseholdSize expose the v8 3-mode
    Schedule page to the brain (was a front-end placeholder).
    - comms_master: detect real showers (flow rising edge) -> recordShower; run the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
    [DataManager.cpp, comms_master.cpp, main.cpp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]
2026-08-15 fix(ui): schedule lead time 15 -> 45 min to match SmartPreheat brain
    The Auto badge and 'next heating' card computed target - 15 min, but the brain
    preheats target - 45 min (BASE_LEAD_MIN). Align the UI so the displayed preheat
    time matches actual behaviour.
    [ui_manager.cpp]
2026-08-15 refactor(ui): move Demo/Real-time toggle Settings -> Diagnostics, rename 'Data source'
    Demo/Real-time is a developer & presentation control, not a consumer operation
    mode. Removed the 'Operation mode' row + Switch button from the Settings screen;
    added a 'Data: Demo / Data: Real-time' toggle to the Diagnostics (technician)
    header. Same mode_toggle_cb; Settings is now consumer-only, and 'operation mode'
    now unambiguously means the Dumb/Ready-by/Smart schedule modes.
2026-08-15 feat(ui): explicit 3-way operation-mode selector (Manual / Ready-by / Smart)
    Replace the Auto on/off header toggle + 2-way Ready/Smart selector with a single
    named 3-way segmented control on the Schedule screen:
    Manual = g_auto_enabled false (reactive; Home power button)
    Ready-by = auto on, user-set time
    Smart = auto on, learned prediction
    Adds a Manual info panel, hides the next-preheat/skip column in Manual, updates
    the Smart panel text (learning is now real, not a placeholder), and shows
    'Manual' on the Home Auto badge. Removed the now-redundant Auto toggle + callback.
    [ui_manager.cpp]
2026-08-15 fix(ui): wizard default ready-by time now populates the Schedule + brain
    The Setup wizard saved g_pref_ready_* but the Schedule screen and the brain read
    g_ready_hh/mm[] — they were never linked, so the wizard time had no effect.
    Seed g_ready_hh/mm from the saved default at boot, and apply it on wizard finish
    (both weekday & weekend), refreshing the Schedule labels.
    [ui_manager.cpp]
2026-08-15 feat(schedule): two ready-by slots (Morning/Evening) + clearer Demo/Real-time
    - Ready-by schedule now [day-type][slot]: Morning + Evening per weekday/weekend,
    each with an On/Off toggle. New slot selector + enable button on the Schedule
    panel; time stepper edits the selected slot; badge/next-preheat use the
    earliest enabled slot (and show 'Auto (smart)' in Smart mode).
    - Brain: PreheatInputs carries a list of enabled ready-by times; SmartPreheat
    pre-heats before ANY of them. UI_GetReadyByMinute -> UI_GetReadyByMinutes.
    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
2026-08-21 feat(brain): adaptive pre-heat lead time (condition-based, not fixed 45min)
    Lead is now computed from how far the tank is below the 40C target at a modelled
    heat-up rate (~0.24 C/min, ~2500W into 150L): colder tank now -> start earlier,
    near-warm -> start just before. Clamped 10-120 min + per-person margin. Replaces
    the fixed BASE_LEAD_MIN. UI 'next pre-heat' relabeled as an estimate that adapts
    to water temperature. README changelog/TODO updated (V2 done; learn-rate = V3).
    [ui_manager.cpp]
2026-08-21 feat(ui): target-temp range 30-80 -> 25-65 C (cap at 65; safer + no waste)
    Settings +/- and Setup wizard now clamp the user target to 25-65 C (was 30-80).
    Range label updated to 'range 25-65'. Saved values are clamped to 25-65 on load
    to protect against stale prefs (e.g. an old 80). Default stays 60 C.
2026-08-21 fix(mode): persist DEMO/REALTIME across reboots + mode sync + always-visible PLC comms
    - Persist appMode to SPIFFS via DataManager (survives master reboot)
    - Add confirmation dialog for mode toggle (prevents accidental switch)
    - Add STATUS_MODE_REALTIME bit (bit 4) to protocol statusByte so master
    can detect mode mismatch with slave
    - Always log PLC communication in both directions (both modes) so the
    link status is visible on serial monitors at all times
    - Slave serial override ('d'/'r') now warns that master CMD will
    overwrite within ~1s; logs clearly when override is overwritten
    - Power button shows correct state on boot and mode switch (ON in DEMO,
    boiler_state in REALTIME)
    - Pro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
    [DataManager.cpp, boiler_protocol.h, comms_master.cpp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]
2026-08-21 fix(slave): shorten Serial output to prevent USB-CDC stalls breaking PLC RX
    ESP32-C6 uses USB-CDC for Serial (not UART0). Long Serial.printf calls
    can block the CPU when the host reads slowly, causing Serial1 (PLC UART)
    RX FIFO to overflow and drop incoming bytes.
    Changes:
    - Move [S<-M] log AFTER state machine reset (minimise time with RX disabled)
    - Shorten all PLC log lines to reduce USB-CDC transfer time
    - Unify DEMO/REALTIME STATUS log format to [S->M]
    This is the likely cause of v9 slave not communicating while v7 worked:
    v9 added always-on [S<-M] logging that v7 suppressed in DEMO mode.
    [plc_comms.cpp]
2026-08-22 fix(slave): revert plc_comms to v7 PLC behavior for comm debugging
    Only diff from v7 is guard_* rename (cosmetic).
    If comms work, we re-add v9 features one at a time.
    [plc_comms.cpp]
2026-08-22 fix(slave): pin ESP32 platform to 53.03.11 (Arduino core 3.1.1)
    Root cause of the sudden PLC comm failure: slave used unpinned
    "platform = espressif32", which resolves to the latest registry version.
    After clearing the PlatformIO cache, it downloaded espressif32@6.12.0,
    whose ESP32-C6 UART/Serial1 support differs and breaks PLC RX on GPIO10.
    Pin to the same pioarduino 53.03.11 + Arduino core 3.1.1 the master uses,
    so both boards run an identical, proven toolchain. No source code changed.
2026-08-23 test(plc): add minimal raw-UART PING/PONG sketches for link diagnosis
    Two standalone sketches (saved as .cpp.txt so PlatformIO ignores them until
    renamed) that strip out ALL project code — no FreeRTOS, protocol, CRC, LVGL.
    Master spams PING once/sec and prints anything received; slave counts raw
    bytes crossing the wire and replies PONG.
    Decisive test: if PONG crosses the KQ-330 modems the link is good and the
    fault is in project code; if the slave sees zero raw bytes the modems/link
    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
2026-08-24 docs: add ordered PLC/KQ-330 troubleshooting checklist
    Step-by-step link-fault procedure: isolate ESPs via ping-test branch, then
    test the modem link alone with a USB-to-UART adapter (end-to-end loopback),
    then targeted fixes for ESP-modem wiring vs modem link vs power-line phase.
    Captures the Aug 2026 finding: clean TX in, garbage out => modem link fault,
    not firmware.
2026-09-03 feat(comms): add switchable PLC/WiFi transport layer
    The KQ-330 power-line link failed in hardware: raw-UART PING/PONG showed the
    master transmitting cleanly while the slave received zero bytes. Rather than
    keep chasing a modem fault, the master/slave link now runs over WiFi, with the
    PLC path kept intact and still selectable.
    A thin transport abstraction (link.h) sits under the protocol layer:
    link_plc.cpp KQ-330 over UART: receive state machine reassembles frames
    byte by byte, 2 ms inter-byte TX gap, 200 ms half-duplex guard
    link_wifi.cpp UDP: one datagram is one frame, so none of the above is needed
    Selected by -DLINK_WIFI in platformio.ini; both sides must matc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
    [comms_master.cpp, link_plc.cpp, link_wifi.cpp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]
2026-09-03 refactor(slave): organise src/ into config, comms, core, tasks, diagnostics
    Groups 30 flat source files into five folders so the project can be read in a sensible order: config -> comms -> core -> tasks.
    config/ pin map, wire protocol, transport ports, WiFi credentials
    comms/ transport backends (PLC/WiFi) + protocol + comms task
    core/ shared state, mutexes, DEMO/REALTIME mode
    tasks/ the six FreeRTOS tasks (sensors, safety, both SSR PWMs)
    diagnostics/ standalone test sketches, excluded from the build
    No source file was edited. Every #include stays short because platformio.ini now puts the subfolders on the include path. build_src_filter excludes diagno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
    [boiler_protocol.h, config.h, current_task.cpp]
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2026-09-03 docs(readme): add repository layout guide for new readers
    Adds a "start here" section at the top of the README: side-by-side folder trees for master and slave, a "where do I look for X" table pointing at the file that answers each common question, and a short explanation of the switchable PLC/WiFi transport.
    Aimed at someone opening the repo cold - the folders are listed in the order they make sense to read.
2026-09-03 docs: comprehensive project README + restore datasheets, PCB and reference docs
    Replaces the placeholder root README with full project documentation written for someone opening the repository cold - including the teachers reviewing it.
    Contents: the physical problem and the two-tier hybrid heating solution; the master/slave split and why it exists; both GPIO maps and the component list; the four-gate hardware safety architecture with the hardware truth table; the binary packet protocol and the PLC/WiFi transport abstraction; the FreeRTOS task hierarchy and mutex layout for both units; burst-mode power control with the P = m*Cp*dT derivation; the SystemManager state machine and the smart-pre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
    [BOM_JLCSMT_Corrected.xlsx, BOM_JLCSMT_FINAL.csv, boiler-bom.csv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]
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2026-09-04 fix(safety): treat an implausible temperature reading as a sensor fault
    A disconnected or dead DS18B20 makes DallasTemperature return DEVICE_DISCONNECTED_C (-127.0). That value was stored straight into temps[] and sent to the master as if it were a real measurement.
    The consequence was dangerous rather than merely wrong: SystemManager would read -127 C, conclude the water is freezing and hold STATE_HEATING_TANK indefinitely, while safety check 1 stayed silent because -127 is not greater than 80. A failed sensor commanded maximum heat instead of stopping the heater.
    TaskTemp now range-checks every reading against the DS18B20 specification (-55..+125 C). Out-of-range readings are not publish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
    [safety_task.cpp, temp_task.cpp]
2026-09-04 docs(code-tour): re-pin permalinks after the sensor-fault change
    The tour described five safety checks while its permalinks still pointed at d2c5f93, which predates check 5 - a reviewer clicking through would have seen code that did not match the text.
    All permalinks now point at d3754fe, and the line ranges shifted by the new check are corrected: uncommanded current 81-84 -> 82-85, link watchdog 96 -> 97, boost interlock 66-74 -> 67-75, mutex snapshot 28-37 -> 29-38, and the guard declarations 61-65 -> 73-77 after the temperature-health block was added to shared_data.h. Each range was verified against the file.
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2026-09-15 fix(wifi): derive the discovery broadcast address from the subnet mask
    The WiFi option hardcoded x.x.x.255 as the broadcast address, which only
    holds on a /24 network. A phone hotspot hands out a /28, so discovery
    never completed. Compute IP | ~netmask instead. PLC is unaffected.
    [link_wifi.cpp]

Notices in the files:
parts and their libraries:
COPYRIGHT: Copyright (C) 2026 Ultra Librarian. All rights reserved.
